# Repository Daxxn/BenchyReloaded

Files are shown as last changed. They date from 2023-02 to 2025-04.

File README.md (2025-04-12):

# BENCHY Version 2 - A Whole New Benchy Boi

>Alot of this is old and needs to be updated!

Your electronics workbench buddy! (Warning - Benchy is not actually your buddy and will probably try to kill you. It's hideously expensive, and way too time consuming to build!)

## Features

- Single Board Computer running embedded linux
- 5 Port USB 3.1 hub
- All data ports are **properly** protected agains over-current and backfeeding
- 2 USB 2.0 ports for the SBC peripherals (keyboard/mouse)
- 2 1Gb Ethernet ports
- 8 Software controlled relays for general things like lighting
- (In Development) Lab Power Supply W/ Current or Voltage Limiting (15V @ 2A)
- Lighting system that can drive 4 RGBW, 2 RGB, 6 dimmable, and 4 switched LED strips
- Electronic Load (5A Max)
- Simple 8 channel volt meter for quick and easy voltage testing
- (in development) Simple LCR Meter
- (in development) Function Generator

# Complete Assembly

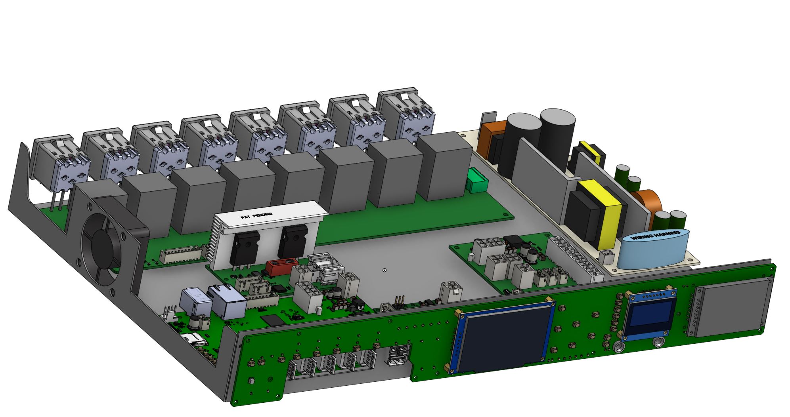
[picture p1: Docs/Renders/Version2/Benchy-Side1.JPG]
Assembly Render


## Motherboard Processor

This design integrates an STM32MP1 Series micro processor (U2) with 8Gb DDR3 memory (U20). This adds a large amount of raw power internally. Taking alot of the load required to control the sub-systems from the users PC and adds more flexability to the system as a whole.

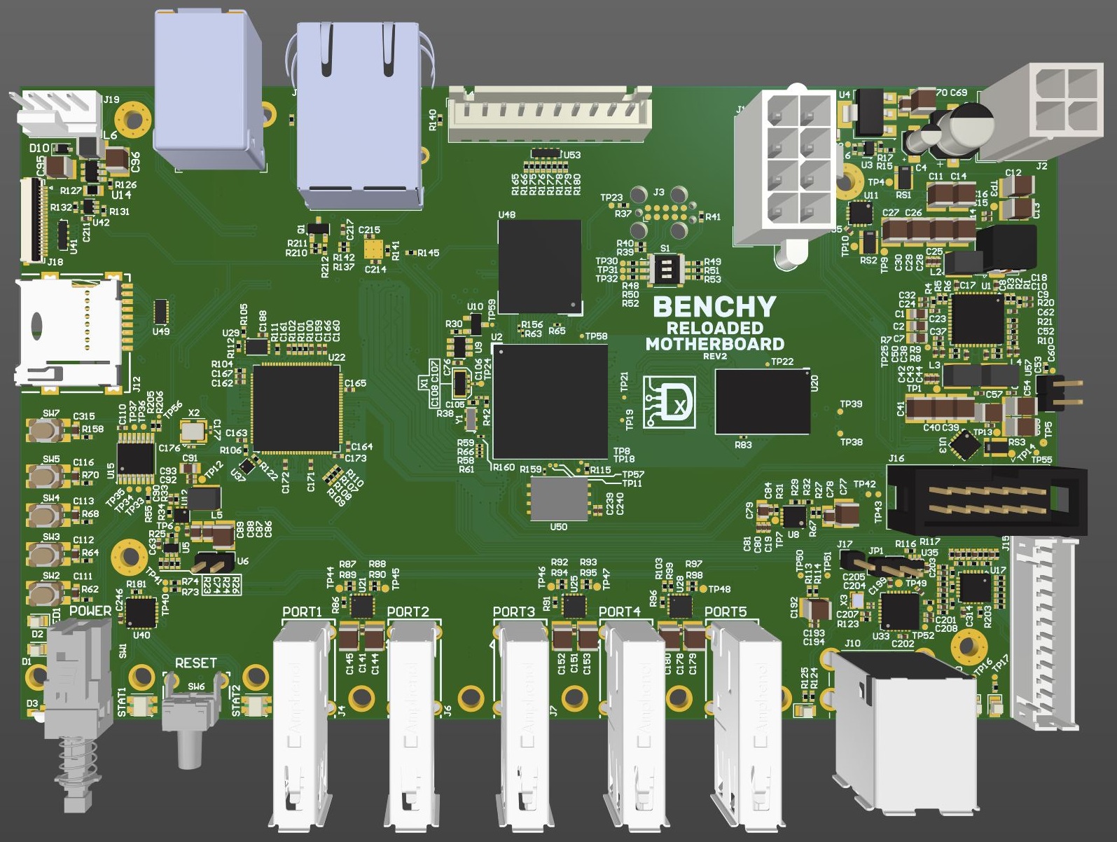
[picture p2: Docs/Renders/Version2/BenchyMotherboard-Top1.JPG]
MB Render


## USB Hub

The main reason why I needed to design my own USB hub instead of stuffing an "off the shelf" hub up benchys trumpet was the absolute lack of protection circuitry in most "consumer grade" USB hubs. There is no back-feed protection, verry little to no current monitoring, and the bare minimum ESD and EMI protection. Thats just not acceptable! imagine my supprise when I cracked open an $85 hub from Amazon and, after blowing out a channel, found no power management at all. The cost of finding a hub that has these protections is going to be around the same price as designing and building my own. (Except for the time investment... but who cares about that?!?)

These features arent exaclty flashy, they dont look very good on a brochure. So they usually arent there. If they are, its just a bullet point. Often they just _claim_ to conform to the USB spec. The lack protection doesn't actually conform to the spec at all. I will admit, some of the protection features are optional and not necessary for every day use. The problem is an electronics workbench is very mean. It will bully these simple hubs until they don't want to play along anymore.

## I2C Bus

Im using a quite extensive I2C bus system to communicate with the different boards and functional blocks. This cuts WAY down on the number of wires and pins required for the main controller and allows for better modularity within benchy.

Due to the size of the bus and the different devices, the bus is split by an I2C Mux to keep bus integrity while communicating to far PCBs.

# Power Supply

The one thing that made the two different power supplies possible was the Switch-Mode Power Supply (SMPS) that was built into the DVR box that spawned this project. The output from the SMPS is a high-current 12V source and 30V source. This was easy to adapt to my needs.

## Adjustable supply

- 15v @ 2A
- Controlled from the motherboard or front panel

The adjustable supply is built with help from [Dave, (Thanks Dave!)](https://www.youtube.com/watch?v=CIGjActDeoM&list=PLBF35875F73B5C9B5&index=1&ab_channel=EEVblog) using the [LM317](https://rocelec.widen.net/view/pdf/mlzstqhekh/slvs044x.pdf?t.download=true&u=5oefqw) adjustable regulator.

## 5V Supply

The ATX supply can provide 15 amps to the USB ports allowing each port to supply around 2 amps. Power is managed by the [UCS2114s.](https://ww1.microchip.com/downloads/aemDocuments/documents/APID/ProductDocuments/DataSheets/UCS2114-Data-Sheet-20005743B.pdf) Controlling both the current limit and backfeeding.

# Electronic Load

Fairly standard design using a MOSFET in its linear region, dissipating alot of energy. With the help of a big heatsink and a fan, it can be used to load power supplies to test their response. The current shunt will allow for precise measurement of power usage. Control is linked to the main microcontroller on the the motherboard. Allowing full control.

# 8 Channel Volt Meter

Low voltage volt meters with moderate accuracy and speed. Designed to measure multiple voltage levels simultaneously. This is helpful for testing power supplies designed for advanced ICs that require lots of voltages to run. Such as Processors, FPGAs, and PC Motherboards.

# Function generator

Creates sine, square, and triangle waves. from ~100Hz to ~100KHz.

# 8 Mains Rated Relays

8 channel relay block used to control general things around the bench like lighting and other small devices. Rated for mains voltage but not for high current.

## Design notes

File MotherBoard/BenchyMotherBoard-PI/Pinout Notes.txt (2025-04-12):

8 relay pins

	COMMS:
6 USART signals
1 I2C
2 SPI
FMC interface? Need to set up the RasPI and STM32 to run some tests with the code I found.

	INPUTS:
PWR SWITCH
EXT-INT
SLEEP
EXTRA BUTTON
PWR PGOOD

	OUTPUTS:
8 RELAYS

  INDICATORS:
STATUS
USB
DEBUG
ETH
MAIN-PG

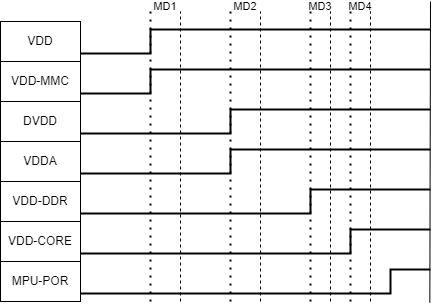
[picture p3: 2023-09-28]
Docs/Notes/AM6254-Power-Seq.png

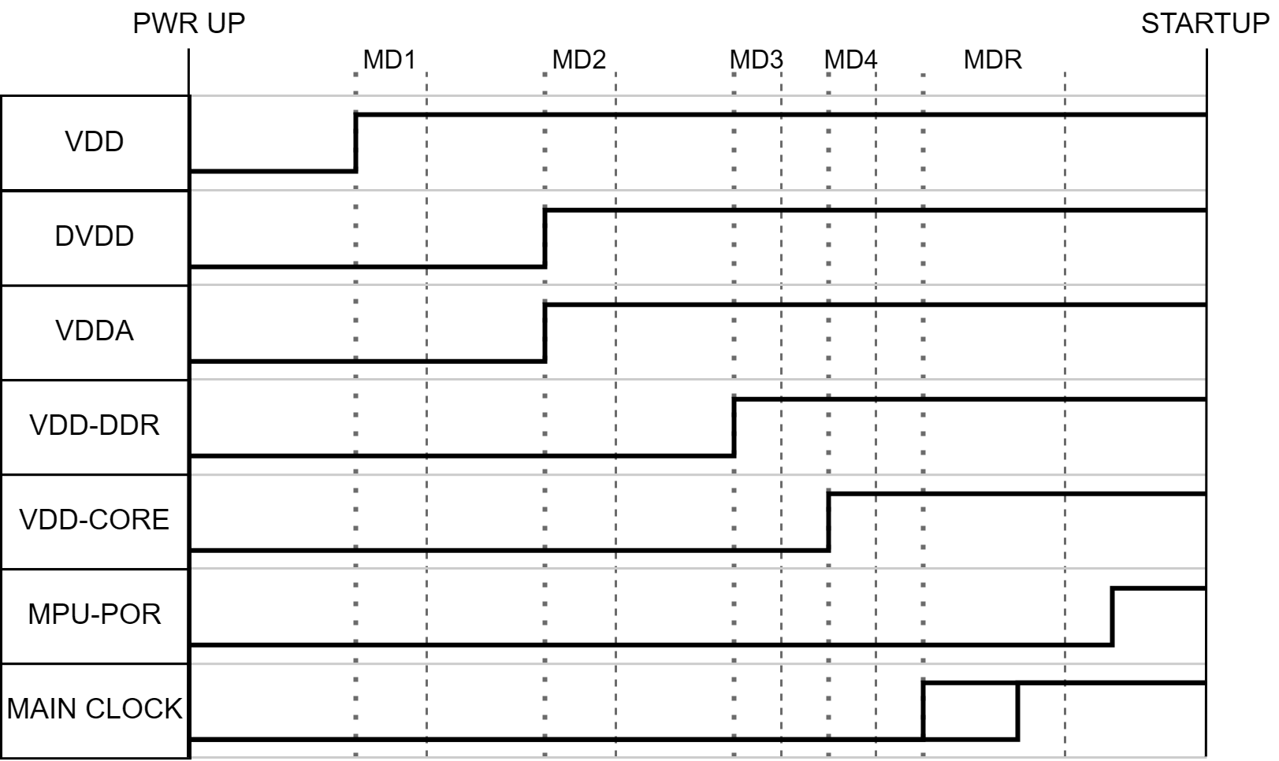
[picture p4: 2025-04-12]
MotherBoard/BenchyMotherBoard-AM625/Docs/AM6254-Power-Seq.png

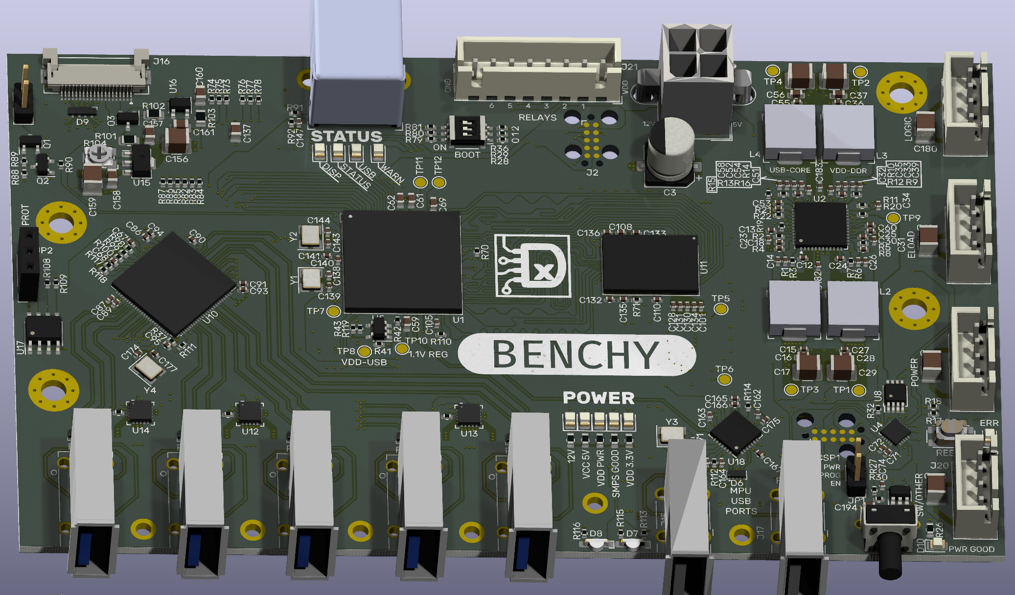
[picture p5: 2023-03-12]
Docs/Renders/MotherBoard/BenchyMotherBoard-REV1-TOP1.png

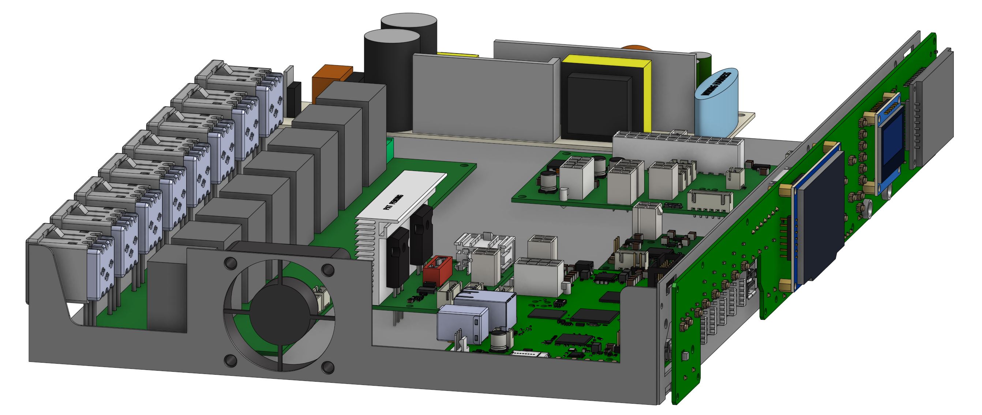
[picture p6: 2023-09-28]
Docs/Renders/Version2/Benchy-Side2.JPG

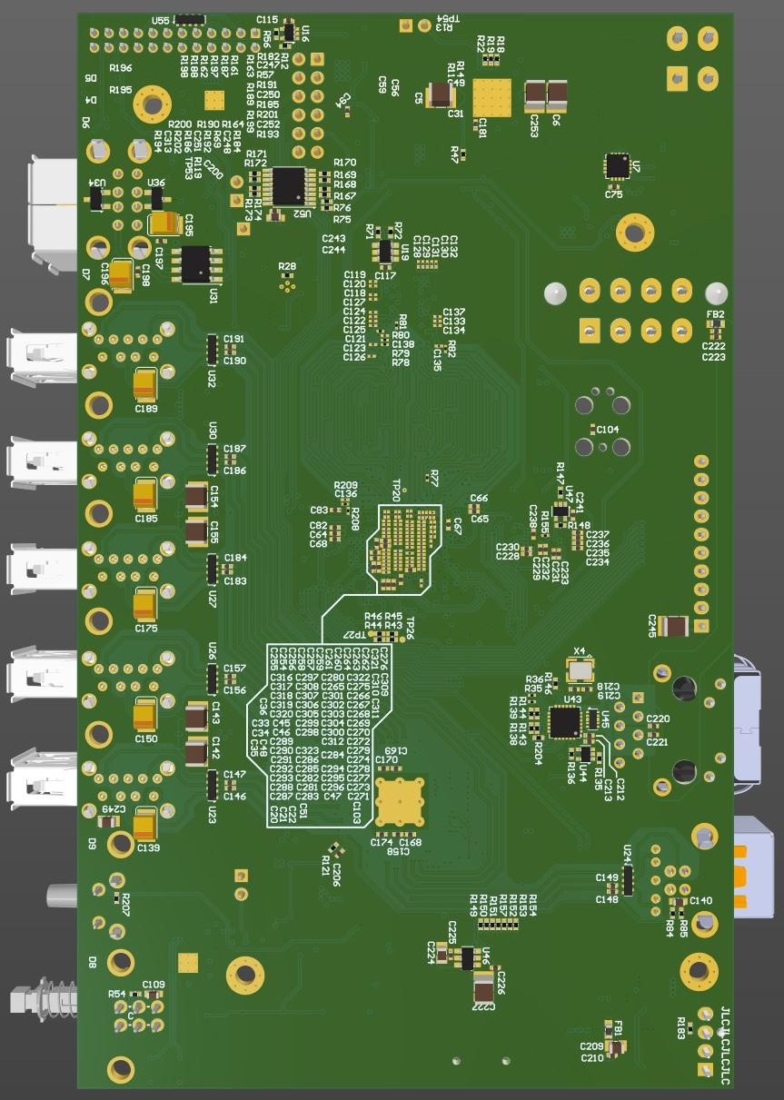
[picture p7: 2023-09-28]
Docs/Renders/Version2/BenchyMotherboard-Bot1.JPG

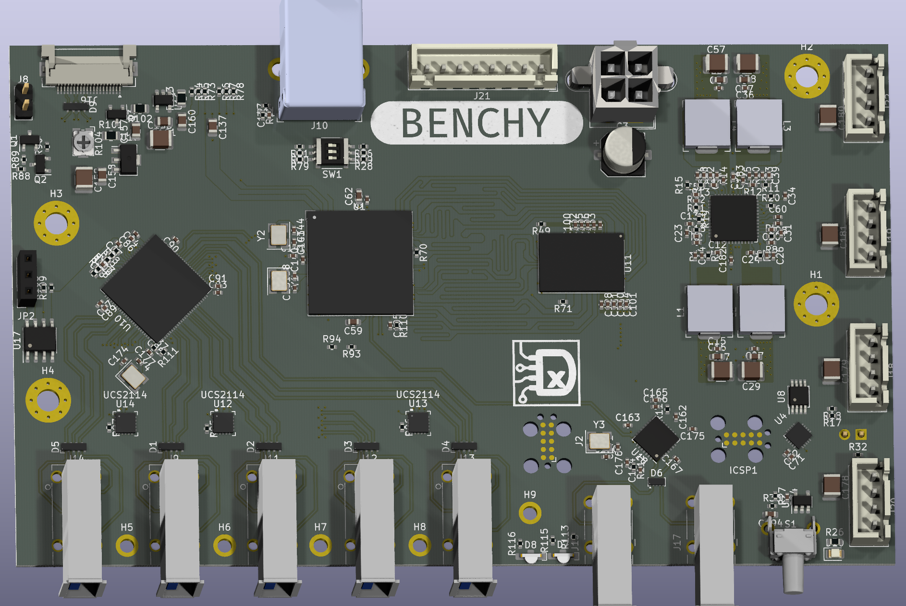
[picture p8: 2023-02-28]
Docs/Renders/MotherBoard/BenchyMotherBoard-PCB_Early2-TOP1.png

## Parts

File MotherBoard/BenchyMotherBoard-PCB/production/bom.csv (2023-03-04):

Designator | Footprint | Quantity | Value | LCSC Part #
C1 | 0603 | 1 | 100nF
C10 | 0402 | 1 | 100nF
C100 | 0402 | 1 | 100nF
C101 | 0402 | 1 | 100nF
C102 | 0402 | 1 | 100nF
C103 | 0402 | 1 | 100nF
C104 | 0402 | 1 | 100nF
C105 | 0402 | 1 | 100nF
C106 | 0402 | 1 | 100nF
C107 | 0402 | 1 | 100nF
C108 | 0402 | 1 | 100nF
C109 | 0402 | 1 | 100nF
C11 | 0402 | 1 | 100nF
C110 | 0402 | 1 | 100nF
C111 | 0402 | 1 | 100nF
C112 | 0402 | 1 | 100nF
C113 | 0402 | 1 | 100nF
C114 | 0402 | 1 | 100nF
C115 | 0402 | 1 | 100nF
C116 | 0402 | 1 | 100nF
C117 | 0402 | 1 | 100nF
C118 | 0402 | 1 | 100nF
C119 | 0402 | 1 | 100nF
C12 | 0402 | 1 | 100nF
C120 | 0402 | 1 | 100nF
C121 | 0402 | 1 | 100nF
C122 | 0402 | 1 | 100nF
C123 | 0603 | 1 | 1uF
C124 | 0603 | 1 | 1uF
C125 | 1210 | 1 | 22uF
C126 | 1210 | 1 | 22uF
C127 | 0402 | 1 | 100nF
C128 | 0402 | 1 | 100nF
C129 | 0402 | 1 | 100nF
C13 | 0402 | 1 | 100nF
C130 | 0402 | 1 | 100nF
C131 | 0402 | 1 | 100nF
C132 | 0402 | 1 | 100nF
C133 | 0402 | 1 | 100nF
C134 | 0402 | 1 | 100nF
C135 | 0402 | 1 | 100nF
C136 | 0402 | 1 | 100nF
C137 | 0805 | 1 | 4.7uF
C138 | 0402 | 1 | 15pF
C139 | 0402 | 1 | 15pF
C14 | 0402 | 1 | 100nF
C140 | 0402 | 1 | 1nF
C141 | 0402 | 1 | 10nF
C142 | 0805 | 1 | 4.7uF
C143 | 0402 | 1 | 15pF
C144 | 0402 | 1 | 15pF
C145 | 1210 | 1 | 10uF
C146 | 1210 | 1 | 10uF
C147 | 0402 | 1 | 100nF
C148 | 1210 | 1 | 10uF
C149 | 1210 | 1 | 10uF
C15 | 0402 | 1 | 100nF
C150 | 1210 | 1 | 10uF
C151 | 1210 | 1 | 10uF
C152 | 1210 | 1 | 10uF
C153 | 1210 | 1 | 10uF
C154 | 1210 | 1 | 10uF
C155 | 1210 | 1 | 10uF
C156 | 1210 | 1 | 10uF
C157 | 0805 | 1 | 1uF
C158 | 0805 | 1 | 1uF
C159 | 1210 | 1 | 10uF
C16 | 0603 | 1 | 1uF
C160 | 0805 | 1 | 1uF
C161 | 0805 | 1 | 100nF
C162 | 0402 | 1 | 100nF
C163 | 0402 | 1 | 100nF
C164 | 0402 | 1 | 100nF
C165 | 0402 | 1 | 100nF
C166 | 0402 | 1 | 100nF
C167 | 0402 | 1 | 100nF
C168 | 1210 | 1 | 10uF
C169 | 1210 | 1 | 1uF
C17 | 1210 | 1 | 10uF
C170 | 0402 | 1 | 15pF
C171 | 0402 | 1 | 15pF
C172 | 1210 | 1 | 10uF
C173 | 1210 | 1 | 1uF
C174 | 0402 | 1 | 15pF
C175 | 0402 | 1 | 100nF
C176 | 0402 | 1 | 100nF
C177 | 0402 | 1 | 15pF
C178 | 1210 | 1 | 10uF
C179 | 1210 | 1 | 10uF
C18 | 0402 | 1 | 47pF
C180 | 1210 | 1 | 10uF
C181 | 1210 | 1 | 10uF
C182 | 0402 | 1 | 100nF
C183 | 0402 | 1 | 100nF
C184 | 1210 | 1 | 10uF
C185 | 0402 | 1 | 100nF
C186 | 0402 | 1 | 100nF
C187 | 0402 | 1 | 100nF
C188 | 0402 | 1 | 100nF
C189 | 0402 | 1 | 100nF
C19 | 0603 | 1 | 1uF
C190 | 0402 | 1 | 100nF
C191 | 0402 | 1 | 100nF
C192 | 0402 | 1 | 100nF
C193 | 0402 | 1 | 100nF
C194 | 0603 | 1 | 1uF
C195 | 0402 | 1 | 100nF
C2 | 0603 | 1 | 100nF
C20 | 0603 | 1 | 1uF
C21 | 0603 | 1 | 1uF
C22 | 0603 | 1 | 1uF
C23 | 0402 | 1 | 330pF
C24 | 0402 | 1 | 100nF
C25 | 0402 | 1 | 100nF
C26 | 0402 | 1 | 100nF
C27 | 0402 | 1 | 100nF
C28 | 0603 | 1 | 1uF
C29 | 1210 | 1 | 10uF
C3 | CP_Elec_6.3x7.7 | 1 | 47uF
C30 | 0402 | 1 | 117pF
C31 | 0402 | 1 | 1nF
C32 | 0402 | 1 | 100nF
C33 | 0402 | 1 | 100pF
C34 | 0402 | 1 | 100nF
C35 | 0402 | 1 | 100nF
C36 | 0402 | 1 | 100nF
C37 | 0603 | 1 | 1uF
C38 | 1210 | 1 | 10uF
C39 | 0402 | 1 | 820pF
C4 | 1210 | 1 | 10uF
C40 | 0402 | 1 | 100nF
C41 | 0402 | 1 | 100nF
C42 | 0402 | 1 | 100nF
C43 | 0402 | 1 | 100nF
C44 | 0402 | 1 | 100nF
C45 | 0402 | 1 | 100nF
C46 | 0402 | 1 | 100nF
C47 | 0402 | 1 | 100nF
C48 | 0402 | 1 | 100nF
C49 | 0402 | 1 | 100nF
C5 | 0402 | 1 | 100nF
C50 | 0402 | 1 | 100nF
C51 | 0402 | 1 | 100nF
C52 | 0402 | 1 | 150pF
C53 | 0402 | 1 | 100nF
C54 | 0402 | 1 | 100nF
C55 | 0402 | 1 | 100nF
C56 | 0603 | 1 | 1uF
C57 | 1210 | 1 | 10uF
C58 | 0402 | 1 | 1.5nF
C59 | 0603 | 1 | 2.2uF
C6 | 0402 | 1 | 100nF
C60 | 0402 | 1 | 100nF
C61 | 0603 | 1 | 2.2uF
C62 | 0603 | 1 | 1uF
C63 | 0603 | 1 | 4.7uF
C64 | 0805 | 1 | 10uF
C65 | 0805 | 1 | 10uF
C66 | 0805 | 1 | 10uF
C67 | 0402 | 1 | 100nF
C68 | 0402 | 1 | 100nF
C69 | 0603 | 1 | 2.2uF
C7 | 0402 | 1 | 100nF
C70 | 0603 | 1 | 1uF
C71 | 0402 | 1 | 100nF
C72 | 0402 | 1 | 100nF
C73 | 0603 | 1 | 1uF
C74 | 0402 | 1 | 100nF
C75 | 0603 | 1 | 1uF
C76 | 0402 | 1 | 100nF
C77 | 0603 | 1 | 4.7uF
C78 | 0402 | 1 | 200nF
C79 | 0603 | 1 | 1uF
C8 | 0402 | 1 | 100nF
C80 | 0603 | 1 | 1uF
C81 | 0402 | 1 | 100nF
C82 | 0402 | 1 | 100nF
C83 | 0402 | 1 | 100nF
C84 | 0402 | 1 | 100nF
C85 | 0402 | 1 | 100nF
C86 | 0402 | 1 | 100nF
C87 | 0402 | 1 | 100nF
C88 | 0402 | 1 | 100nF
C89 | 0402 | 1 | 100nF
C9 | 0402 | 1 | 100nF
C90 | 0402 | 1 | 100nF
C91 | 0402 | 1 | 100nF
C92 | 0402 | 1 | 100nF
C93 | 0402 | 1 | 100nF
C94 | 0402 | 1 | 100nF
C95 | 0402 | 1 | 100nF
C96 | 0805 | 1 | 10uF
C97 | 0805 | 1 | 10uF
C98 | 0402 | 1 | 1nF
C99 | 0402 | 1 | 100nF
D1, D2, D3, D4, D5, D9 | U-DFN3810-9 | 6 | ESDLC5V0PB8
D10 | 0805 | 1 | GREEN
D11 | 0805 | 1 | RED
D12 | 0805 | 1 | ORANGE
D13 | 0805 | 1 | RED
D14 | 0805 | 1 | ORANGE
D15 | 0805 | 1 | GREEN
D6 | DFN2510A-10 | 1 | PUSB3AB4-2USB
D7 | LED-SMD-1204_RA | 1 | ORANGE
D8 | LED-SMD-1204_RA | 1 | YELLOW
H1, H2, H3, H4 | MountingHole_3.5mm_Pad_Via | 4 | M3
H10, H5, H6, H7, H8, H9 | MountingHole_2.2mm_M2_ISO7380_Pad | 6 | M2
ICSP1 | Tag-Connect_TC2050-IDC-FP_2x05_P1.27mm_Vertical | 1 | ICSP
J1 | 4-Pin_Molex_Mini-Fit_Jr_Vertical_Mount | 1 | PWR-CONN
J10 | USB-GSB3211311WEU | 1 | USB3_B
J11 | GSB4116341HR | 1 | USB3-PORT2
J12 | GSB4116341HR | 1 | USB3-PORT3
J13 | GSB4116341HR | 1 | USB3-PORT4
J14 | GSB4116341HR | 1 | USB3-PORT5
J15 | 1002-014-01000 | 1 | USB-INTERNAL-PORT1
J16 | FH12A-20S-0.5SH55 | 1 | TFT-DISPLAY
J17 | 1002-014-01000 | 1 | USB-INTERNAL-PORT2
J18 | JST_XH_B4B-XH-A_Vertical | 1 | COMMS-PWR
J19 | JST_XH_B4B-XH-A_Vertical | 1 | COMMS-ELOAD
J2 | Tag-Connect_TC2050-IDC-FP_2x05_P1.27mm_Vertical | 1 | SWD-TAG
J20 | JST_XH_B4B-XH-A_Vertical | 1 | COMMS-SWITCHER
J21 | JST_XH_B8B-XH-A_1x08_P2.50mm_Vertical | 1 | RELAYS-CONN
J22 | JST_XH_B4B-XH-A_Vertical | 1 | COMMS-LOGIC
J3 | microSD_HC_Molex_47219-2001 | 1 | FILES-SD-CARD
J7 | microSD_HC_Molex_47219-2001 | 1 | BOOT-SD-CARD
J8 | PinHeader_1x02_P2.54mm_Vertical | 1 | FAN-CONN
J9 | GSB4116341HR | 1 | USB3-PORT1
JP1 | PinHeader_1x02_P2.54mm_Vertical | 1 | PWR-ICSP-RST
JP2 | PinSocket_1x03_P2.54mm_Vertical | 1 | WP-JMP
L1 | PA4341 | 1 | 22uH
L2, L3, L4 | PA4341 | 3 | 10uH
Q1 | SOT-23 | 1 | SQ2310ES_SOT23
Q2 | SOT-23 | 1 | MMBT2222A
Q3 | SOT-23 | 1 | RQ5A030AP
R1 | 0402 | 1 | 24K
R10 | 0402 | 1 | 13K
R100 | 0402 | 1 | 10K
R101 | 0805 | 1 | 10 1%
R102 | 0805 | 1 | 120
R103 | 0805 | 1 | 330
R104 | Bourns_TC33X | 1 | 10K
R105 | 0402 | 1 | 10K
R106 | 0402 | 1 | 200K
R107 | 0402 | 1 | 200K
R108 | 0402 | 1 | 2.2K
R109 | 0402 | 1 | 2.2K
R11 | 0402 | 1 | 10K
R110 | 0402 | 1 | 3K
R111 | 0402 | 1 | 10K
R112 | 0402 | 1 | 12K 1%
R113 | 0402 | 1 | 50K
R114 | 0402 | 1 | 50K
R115 | 0402 | 1 | 1K
R116 | 0402 | 1 | 1K
R117 | 0402 | 1 | 10K
R118 | 0402 | 1 | 200K
R119 | 0402 | 1 | 4.7K
R12 | 0402 | 1 | 15K
R13 | 0402 | 1 | 8.2K
R14 | 0402 | 1 | 4.3K
R15 | 0402 | 1 | 10K
R16 | 0402 | 1 | 11K
R17 | 0402 | 1 | 2.2K
R18 | 0402 | 1 | 2.2K
R19 | 0402 | 1 | 10K
R2 | 0402 | 1 | 24K
R20 | 0402 | 1 | 10K
R21 | 0402 | 1 | 160K
R22 | 0402 | 1 | 160K
R23 | 0402 | 1 | 10K
R24 | 0402 | 1 | 10K
R25 | 0402 | 1 | 10K
R26 | 0603 | 1 | 500
R27 | 0402 | 1 | 1K
R28 | 0402 | 1 | 1K
R29 | 0402 | 1 | 1K
R3 | 0402 | 1 | 10K
R30 | 0402 | 1 | 10K
R31 | 0603 | 1 | 500
R32 | 0402 | 1 | 10K
R33 | 0603 | 1 | 500
R34 | 0402 | 1 | 10K
R35 | 0402 | 1 | 6.8K
R36 | 0402 | 1 | 1K
R37 | 0402 | 1 | 12K 1%
R38 | 0603 | 1 | 500
R39 | 0603 | 1 | 500
R4 | 0402 | 1 | 7.5K
R40 | 0603 | 1 | 500
R41 | 0402 | 1 | 10K
R42 | 0402 | 1 | 100
R43 | 0402 | 1 | 10K
R44 | 0402 | 1 | 56
R45 | 0402 | 1 | 100
R46 | 0402 | 1 | 56
R47 | 0402 | 1 | 56
R48 | 0402 | 1 | 56
R49 | 0402 | 1 | 10K
R5 | 0402 | 1 | 10K
R50 | 0402 | 1 | 10K
R51 | 0402 | 1 | 56
R52 | 0402 | 1 | 56
R53 | 0402 | 1 | 56
R54 | 0402 | 1 | 56
R55 | 0402 | 1 | 56
R56 | 0402 | 1 | 56
R57 | 0402 | 1 | 56
R58 | 0402 | 1 | 56
R59 | 0402 | 1 | 56
R6 | 0402 | 1 | 6.2K
R60 | 0402 | 1 | 56
R61 | 0402 | 1 | 56
R62 | 0402 | 1 | 56
R63 | 0402 | 1 | 56
R64 | 0402 | 1 | 56
R65 | 0402 | 1 | 56
R66 | 0402 | 1 | 56
R67 | 0402 | 1 | 56
R68 | 0402 | 1 | 56
R69 | 0402 | 1 | 56
R7 | 0402 | 1 | 10K
R70 | 0402 | 1 | 240 1%
R71 | 0402 | 1 | 240 1%
R72 | 0402 | 1 | 56
R73 | 0402 | 1 | 10K
R74 | 0402 | 1 | 47K
R75 | 0402 | 1 | 47K
R76 | 0402 | 1 | 47K
R77 | 0402 | 1 | 47K
R78 | 0402 | 1 | 47K
R79 | 0402 | 1 | 100
R8 | 0402 | 1 | 10K
R80 | 0402 | 1 | 100
R81 | 0402 | 1 | 100
R82 | 0402 | 1 | 10K
R83 | 0402 | 1 | 47K
R84 | 0402 | 1 | 47K
R85 | 0402 | 1 | 47K
R86 | 0402 | 1 | 47K
R87 | 0402 | 1 | 47K
R88 | 0402 | 1 | 10K
R89 | 0402 | 1 | 100
R9 | 0402 | 1 | 10K
R90 | 0402 | 1 | 1K
R91 | 0402 | 1 | 43K
R92 | 0402 | 1 | 50K
R93 | 0402 | 1 | 2.2K
R94 | 0402 | 1 | 2.2K
R95 | 0402 | 1 | 18K
R96 | 0402 | 1 | 18K
R97 | 0402 | 1 | 18K
R98 | 0402 | 1 | 10K
R99 | 0402 | 1 | 10K
S1 | TL1105SF | 1 | PWR-SW
S2 | TL3365AF180QG | 1 | PWR-RESET
SW1 | SW_DIP_SPSTx03_Slide_Copal_CVS-03xB_W5.9mm_P1mm | 1 | BOOT-SEL
TP1 | TestPoint_Pad_D1.5mm | 1 | TP-VDD-CORE
TP10 | TestPoint_Pad_D1.5mm | 1 | TP-1V1-REG
TP11 | TestPoint_Pad_D1.5mm | 1 | TP-1V8-REG
TP12 | TestPoint_Pad_D1.5mm | 1 | TP-DSI-REG
TP2 | TestPoint_Pad_D1.5mm | 1 | TP-VDD-DDR
TP3 | TestPoint_Pad_D1.5mm | 1 | TP-VDD
TP4 | TestPoint_Pad_D1.5mm | 1 | TP-USB-CORE
TP5 | TestPoint_Pad_D1.5mm | 1 | TP-VTT
TP6 | TestPoint_Pad_D1.5mm | 1 | TP-VREF-DDR
TP7 | TestPoint_Pad_D1.5mm | 1 | TP-VDDA
TP8 | TestPoint_Pad_D1.5mm | 1 | TP-VDD-USB
TP9 | TestPoint_Pad_D1.5mm | 1 | TP-VDD-PWR
U1 | LFBGA354-P0.8mm | 1 | STM32MP157FAB1
U10 | 100-VQFN-GND_12X12 | 1 | USB7206C
U11 | DDR_FBGA-96_9x13mm_P0.8mm | 1 | IS43TR16256B-125KBLI
U12, U13, U14 | UCS2114T-1-V_LXVAO-Custom | 3 | UCS2114
U15 | SOT-89-3 | 1 | LM317L
U16 | SOT-23-5 | 1 | AS321
U17 | SOIC-8_3.9x4.9mm_P1.27mm | 1 | 24LC08
U18 | QFN-28-1EP_5x5mm_P0.5mm_EP3.35x3.35mm | 1 | USB2412
U2 | QFN-48-1EP_7x7mm_P0.5mm_EP5.15x5.15mm_ThermalVias | 1 | TPS65400RGZT
U3 | DFN-10-1EP_3x3mm_P0.5mm_EP1.65x2.38mm | 1 | NCP51200
U4 | QFN-20-1EP_3x3mm_P0.4mm_EP1.65x1.65mm | 1 | ATTINY416-MNR
U5 | SOT-23-5 | 1 | TLV3401
U6 | DFN-10-1EP_3x3mm_P0.5mm_EP1.65x2.38mm | 1 | MAX15027
U7 | SOT-23-5 | 1 | SN74LVC1G32
U8 | TSSOP-8_3x3mm_P0.65mm | 1 | 74HCT2G08
U9 | SOT-23-5 | 1 | AP2127K-3.3
Y1 | Crystal_SMD_4Pin_3.2x2.5mm | 1 | 24MHz
Y2 | Crystal_SMD_4Pin_3.2x2.5mm | 1 | 32.7KHz
Y3, Y4 | Crystal_SMD_4Pin_3.2x2.5mm | 2 | 25MHz

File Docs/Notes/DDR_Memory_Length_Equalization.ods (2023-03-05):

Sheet: Sheet 1
Memory_length_equalization_in_mm_for_STM32MP15XXAB
Board reference: | STM32MP15XXAB
Variant:
PCB revision:
Assembly revision:
Date:

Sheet: Address_Command
 | STM32MP15XXAB
LFBGA354 PINOUT | NET NAME | STM32MP15XXAB LENGTH (mm) | STM32MP15XXAB to memory (mm) | KiCAD Total Length (mm) | TOTAL LENGTH (mm) | DELTA WITH ((CLK_P+CLK_N)/2): from -1.016 to 0 mm | Fill the column C with the track lengths of printed circuit board including via Modify the track length of column C in order to be within the limits of column E
H18 | A0 | 5.19 | 61.4075 | 65.0171 | 65.0171 | -0.2012 | value | within the limits
M17 | A1 | 6.31 | 60.0967 | 65.0539 | 65.0539 | -0.164400000000001 | value | outside the limits
G18 | A2 | 5.63 | 61.0362 | 65.0241 | 65.0241 | -0.194199999999995
F19 | A3 | 6.58 | 60.1274 | 64.9999 | 64.9999 | -0.218400000000003
P17 | A4 | 5.55 | 61.1017 | 65.0387 | 65.0387 | -0.179599999999994
H17 | A5 | 3.79 | 62.8956 | 65.0519 | 65.0519 | -0.166399999999996
N16 | A6 | 4.06 | 62.6386 | 65.0006 | 65.0006 | -0.217699999999994
E17 | A7 | 7.8 | 58.8546 | 64.9999 | 64.9999 | -0.218400000000003
R17 | A8 | 6.62 | 60.0918 | 65 | 65 | -0.218299999999999
G17 | A9 | 4.05 | 62.6402 | 65.0131 | 65.0131 | -0.205200000000005
M19 | A10 | 6.59 | 60.0643 | 65 | 65 | -0.218299999999999
M18 | A11 | 5.69 | 61.0072 | 65 | 65 | -0.218299999999999
L17 | A12 | 4.57 | 62.0861 | 65.0903 | 65.0903 | -0.128
F17 | A13 | 6.34 | 60.2901 | 65.0523 | 65.0523 | -0.165999999999997
N18 | A14 | 6.65 | 60.0339 | 65.0218 | 65.0218 | -0.1965
L16 | A15 | 4.11 | 0 | 0 | 4.11 | -61.1083
G19 | BA0 | 6.01 | 60.6675 | 65 | 65 | -0.218299999999999
N17 | BA1 | 6.76 | 59.676 | 65 | 65 | -0.218299999999999
J16 | BA2 | 5.81 | 60.8156 | 65 | 65 | -0.218299999999999
K17 | CASN | 4.85 | 61.8182 | 65.0271 | 65.0271 | -0.191199999999995
P19 | CKE | 6.66 | 60.0232 | 65 | 65 | -0.218299999999999
L19 | CLK_N | 6.03 | 60.559 | 65.2336 | 65.2336
K19 | CLK_P | 6.09 | 60.7447 | 65.203 | 65.203
J18 | CSN | 5.86 | 60.8061 | 65.0106 | 65.0106 | -0.207700000000003
H19 | ODT | 6.47 | 60.1628 | 65 | 65 | -0.218299999999999
L18 | RASN | 5.21 | 61.4307 | 65.0012 | 65.0012 | -0.217100000000002
J17 | WEN | 4.69 | 61.9582 | 65 | 65 | -0.218299999999999

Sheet: Data
STM32MP15XXAB
 | LFBGA354 PINOUT | NET NAME | STM32MP15XXAB LENGTH (mm) | STM32MP15XXAB to memory (mm) | KiCAD Total Length (mm) | TOTAL LENGTH (mm) | DELTA WITH ((DQSn_P+DQSn_N)/2) MAX: +/- 1.016 mm | DELTA WITH ((CLK_P+CLK_N)/2): from -15 to 0 mm | Fill the column D with the track lengths of printed circuit board including via Modify the track length of column D in order to be within the limits of columns F and G
Byte 0 | A17 | DQ0 | 8.17 | 0 | 65.0894 | 65.0894 | 0.0852499999999878 |  | value | within the limits
 | A18 | DQ1 | 8.19 | 0 | 65.0434 | 65.0434 | 0.0392499999999956 |  | value | outside the limits
 | D18 | DQ2 | 6.92 | 0 | 65.0477 | 65.0477 | 0.0435499999999962
 | B17 | DQ3 | 6.97 | 0 | 64.9933 | 64.9933 | -0.0108500000000049
 | E18 | DQ4 | 6.7 | 0 | 65.0011 | 65.0011 | -0.00305000000001598
 | D17 | DQ5 | 7.63 | 0 | 65.0037 | 65.0037 | -0.000450000000014938
 | D19 | DQ6 | 7.33 | 0 | 65 | 65 | -0.00415000000000987
 | B18 | DQ7 | 7.47 | 0 | 65.0023 | 65.0023 | -0.00185000000000457
 | C18 | DQM0 | 6.76 | 0 | 65.0017 | 65.0017 | -0.00245000000001028
 | C19 | DQS0_P | 8.08 | 0 | 65 | 65 |  | -0.214149999999989
 | B19 | DQS0_N | 8.09 | 0 | 65.0083 | 65.0083
Byte 1 | P18 | DQ8 | 5.36 | 0 | 65.0211 | 65.0211 | -0.0274500000000017
 | T17 | DQ9 | 7.37 | 0 | 65 | 65 | -0.0485500000000059
 | R18 | DQ10 | 6.67 | 0 | 65.0964 | 65.0964 | 0.0478499999999968
 | V19 | DQ11 | 7.66 | 0 | 65.0914 | 65.0914 | 0.0428499999999872
 | W18 | DQ12 | 7.85 | 0 | 65.0942 | 65.0942 | 0.0456499999999949
 | T18 | DQ13 | 6.8 | 0 | 65.0643 | 65.0643 | 0.015749999999997
 | V18 | DQ14 | 7.23 | 0 | 65.0042 | 65.0042 | -0.0443500000000086
 | W17 | DQ15 | 7.9 | 0 | 65.0048 | 65.0048 | -0.0437500000000028
 | U18 | DQM1 | 6.83 | 0 | 65.0071 | 65.0071 | -0.0414500000000118
 | U19 | DQS1_P | 7.26 | 0 | 65.011 | 65.011 |  | -0.169749999999993
 | T19 | DQS1_N | 7.26 | 0 | 65.0861 | 65.0861

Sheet: Impedance
DDR3 MEMORY IMPEDANCE
Differential Pairs | Req | Calculated | Width | Spacing
Diff Pair Inner | 100 | 100.189 | 0.195 | 0.1
DiffPair Outer | 100 | 100.164 | 0.12 | 0.13
Striplines | Req | Calculated | Width | Clearance
Strip Line (Inner) | 55 | 55.0422 | 0.15 | 0.4584
Microstrip Line (Outer) | 55 | 55.0052 | 0.15 | 0.3
Theres no guarantee that the impedance calculations are correct

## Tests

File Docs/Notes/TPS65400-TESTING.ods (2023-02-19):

Voltage Feedback
VREF | RTOP | RBOT
0.8 | 6.6 | 7.5
VOUT
1.504
Inductor Selection / Ripple
uL | L | Khz | Hz | Nominal Ripple | Max Ripple
10 | 0.00001 | 1000 | 1000000 | 0.6 | 0.9
VIN
12
Output Current Ripple
0.131549866666667

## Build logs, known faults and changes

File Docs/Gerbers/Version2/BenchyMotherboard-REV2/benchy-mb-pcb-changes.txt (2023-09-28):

%FSLAX23Y23*%
%MOIN*%
%SFA1B1*%

%IPPOS*%
%ADD9500C,0.007900*%
%ADD9501C,0.009800*%
%ADD9502C,0.011800*%
%ADD9503C,0.015700*%
%ADD9504C,0.027600*%
%ADD9505C,0.029100*%
%ADD9506C,0.029500*%
%ADD9507C,0.035000*%
%ADD9508C,0.035400*%
%ADD9509C,0.036200*%
%ADD9510C,0.037400*%
%ADD9511C,0.039400*%
%ADD9512C,0.040200*%
%ADD9513C,0.051200*%
%ADD9514C,0.055100*%
%ADD9515C,0.059000*%
%ADD9516C,0.063000*%
%ADD9517C,0.090600*%
%ADD9518C,0.106300*%
%ADD9519C,0.037000*%
%ADD9520C,0.039000*%
%ADD9521C,0.043300*%
%ADD9522C,0.093500*%
%ADD9523C,0.118100*%
%ADD9524C,0.128000*%
%LNbenchy-mb-pcb-changes-1*%
%LPD*%
G54D9500*
X911Y887D03*
X954Y1181D03*
X822D03*
Y1338D03*
X954D03*
X1076Y1531D03*
X1183Y1486D03*
X1395Y1502D03*
X1474D03*
X1465Y1426D03*
Y1385D03*
Y1343D03*
X1423D03*
Y1385D03*
Y1426D03*
X1506D03*
Y1385D03*
Y1343D03*
X1366Y1334D03*
X1350Y1387D03*
X1492Y893D03*
X1795Y1023D03*
X2214D03*
X2242D03*
X2192Y905D03*
X2110Y1133D03*
Y1161D03*
Y1190D03*
X2637Y1169D03*
X2667D03*
X2696Y1171D03*
Y1143D03*
Y1200D03*
Y1252D03*
Y1322D03*
Y1342D03*
X2722Y1344D03*
X2744D03*
X2765D03*
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

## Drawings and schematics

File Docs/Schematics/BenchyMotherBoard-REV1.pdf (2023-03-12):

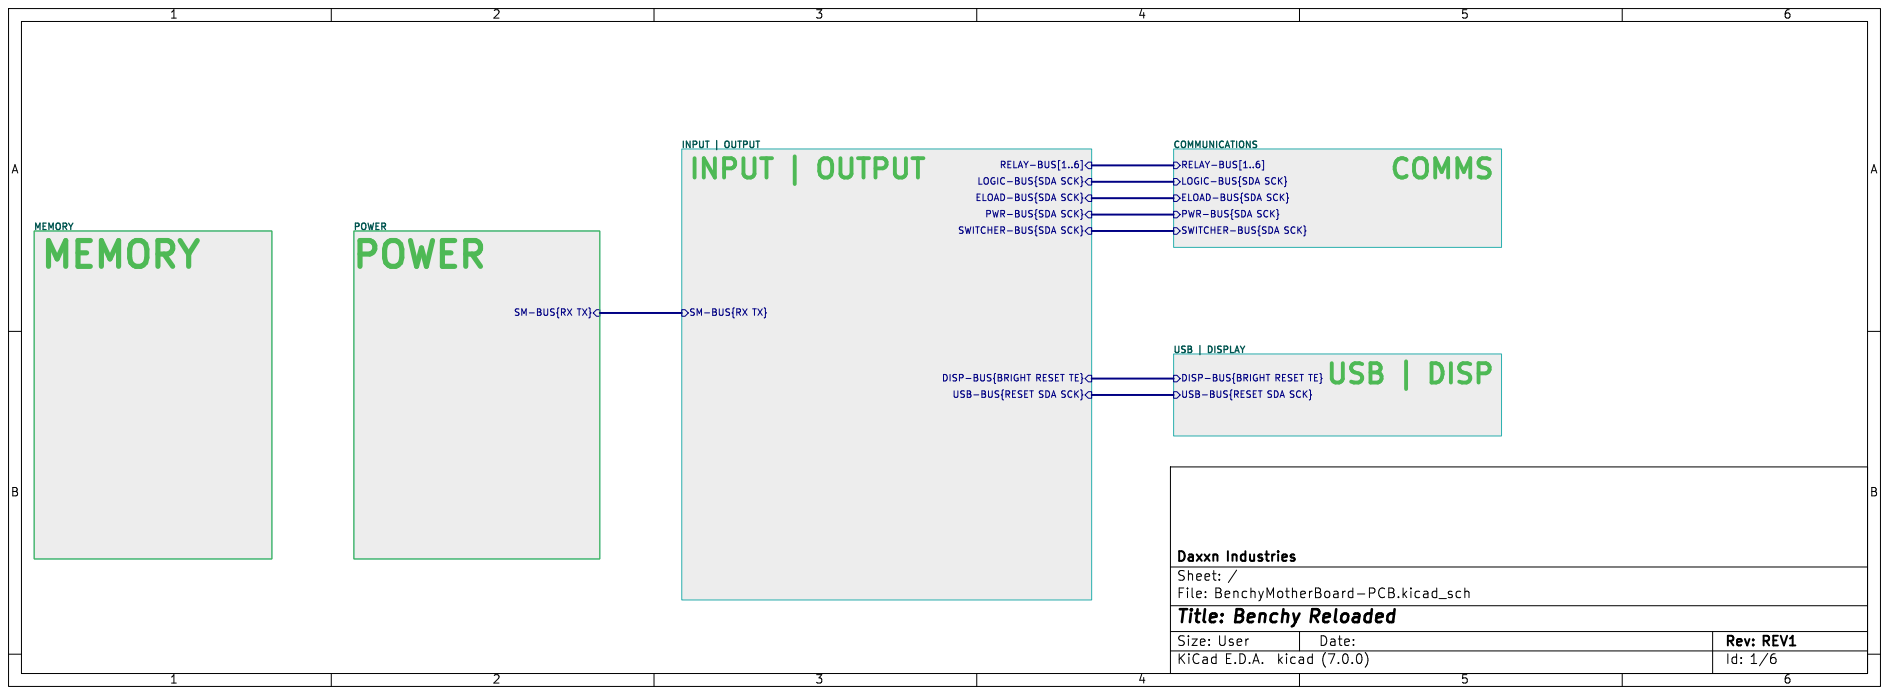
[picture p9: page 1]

Id: 1/6 Title: Benchy Reloaded

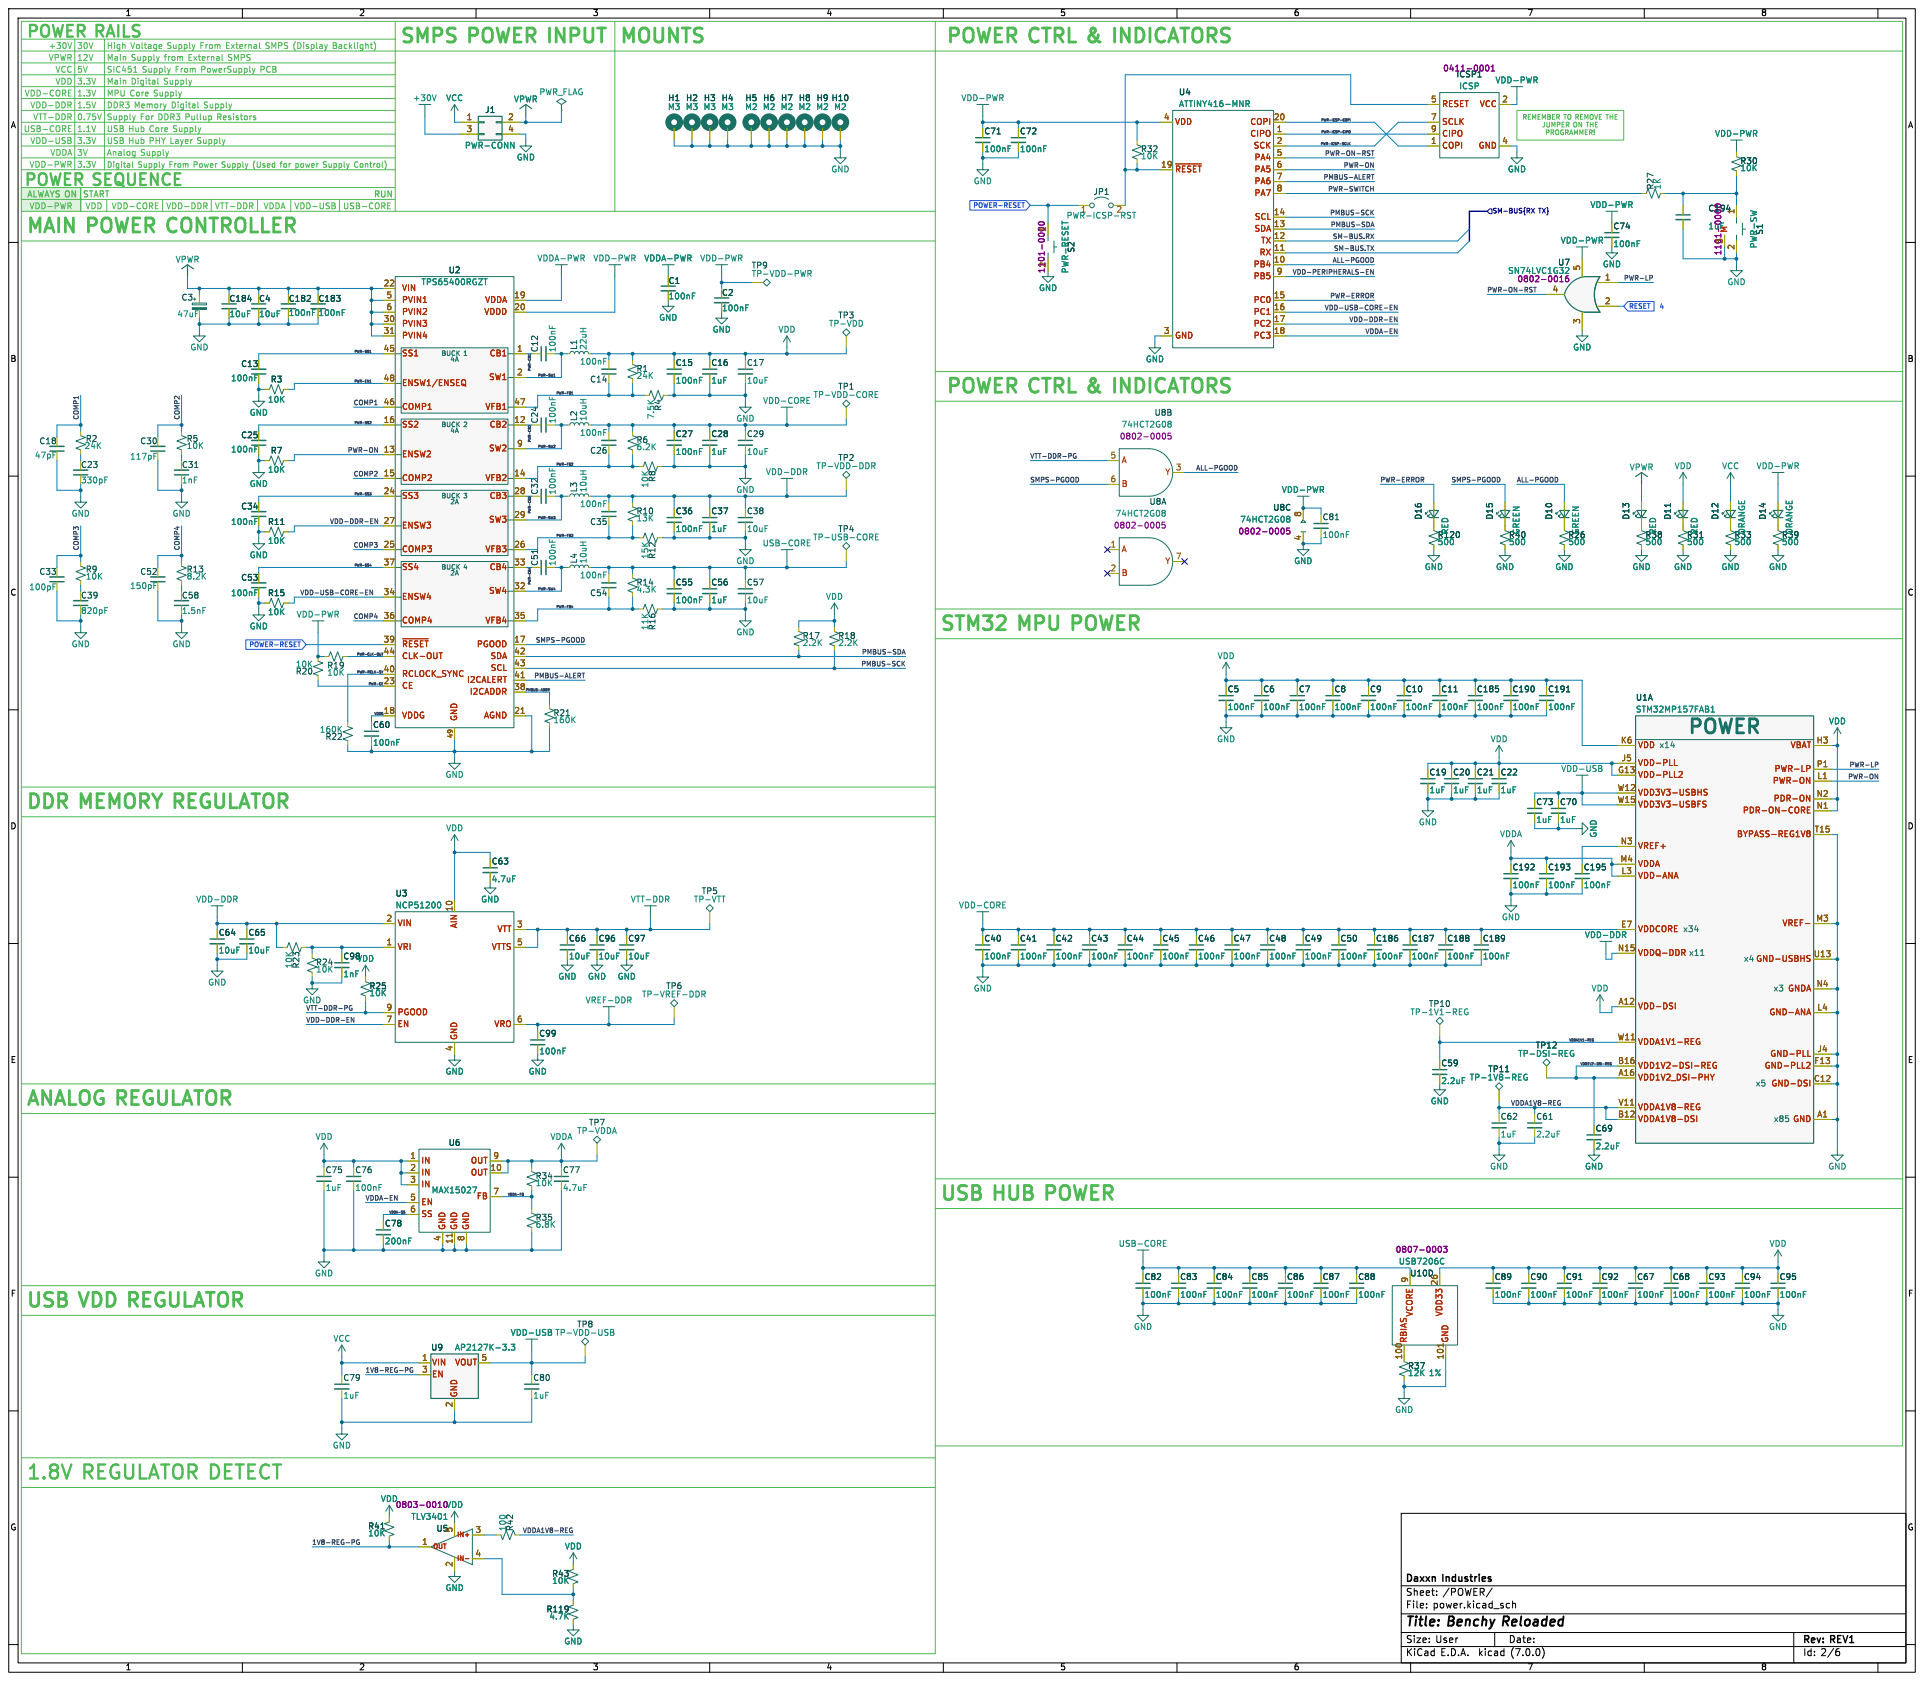
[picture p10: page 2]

30V USB VDD REGULATOR
Supply For DDR3 Pullup Resistors VDD-PWR ANALOG REGULATOR
1.1V MAIN POWER CONTROLLER

Digital Supply From Power Supply (Used for power Supply Control) POWER

High Voltage Supply From External SMPS (Display Backlight) VDD-DDR
SIC451 Supply From PowerSupply PCB Main Supply from External SMPS
VTT-DDR POWER SEQUENCE

JP1 PWR-ICSP-RST VDD-PWR GND

VDD-USB USB Hub Core Supply

PWR-ICSP-COPI PWR-ON-RST

VDDA 3V
VTT-DDR-PG VDD-PWR

100nF VDDA-PWR VDD-PWR

PWR-ON
PMBUS-ALERT PWR-SWITCH

POWER-RESET VDD-USB-CORE-EN

PWR-ERROR
VDD-USB-CORE-EN

J5 VDD
J4 VDD-PLL
P1 BYPASS-REG1V8 T15 GND-USBHS U13 VDDA1V8-REG
L1 VDD-ANA

4 VTTS 5 VRO 6 EN 7 PGOOD 9 U3 NCP51200 GND

4 VTTS 5 VRO 6 EN 7 PGOOD 9 GND GND

TP6 TP-VREF-DDR GND

2 EN 3 VOUT 5 U9 AP2127K-3.3 VREF-DDR GND

4 EN 5 SS 6 FB 7 GND

Id: 2/6 Title: Benchy Reloaded

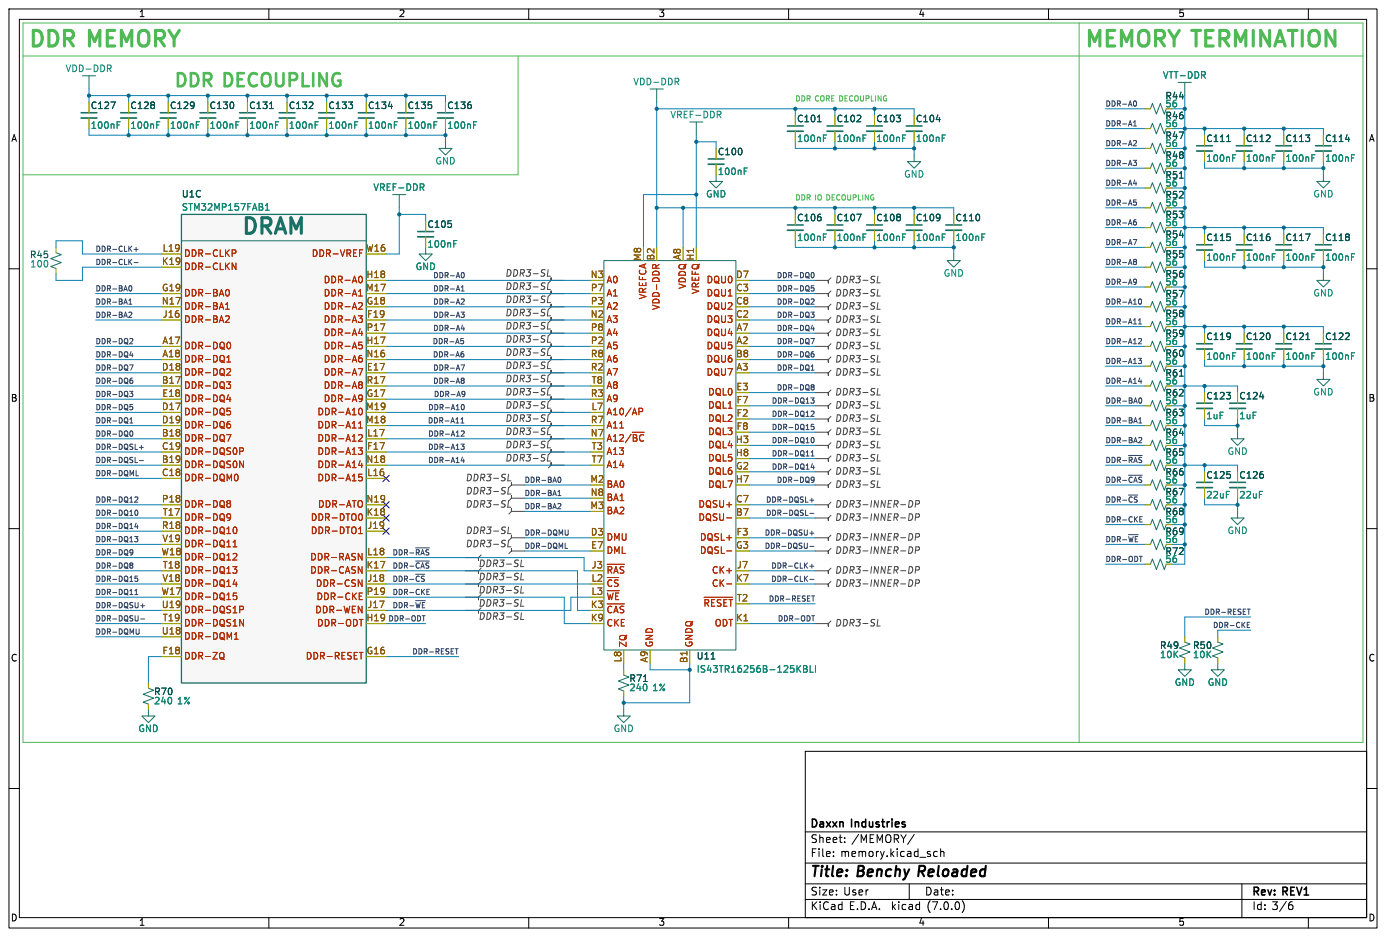
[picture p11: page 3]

DDR IO DECOUPLING DDR DECOUPLING

Id: 3/6 Title: Benchy Reloaded

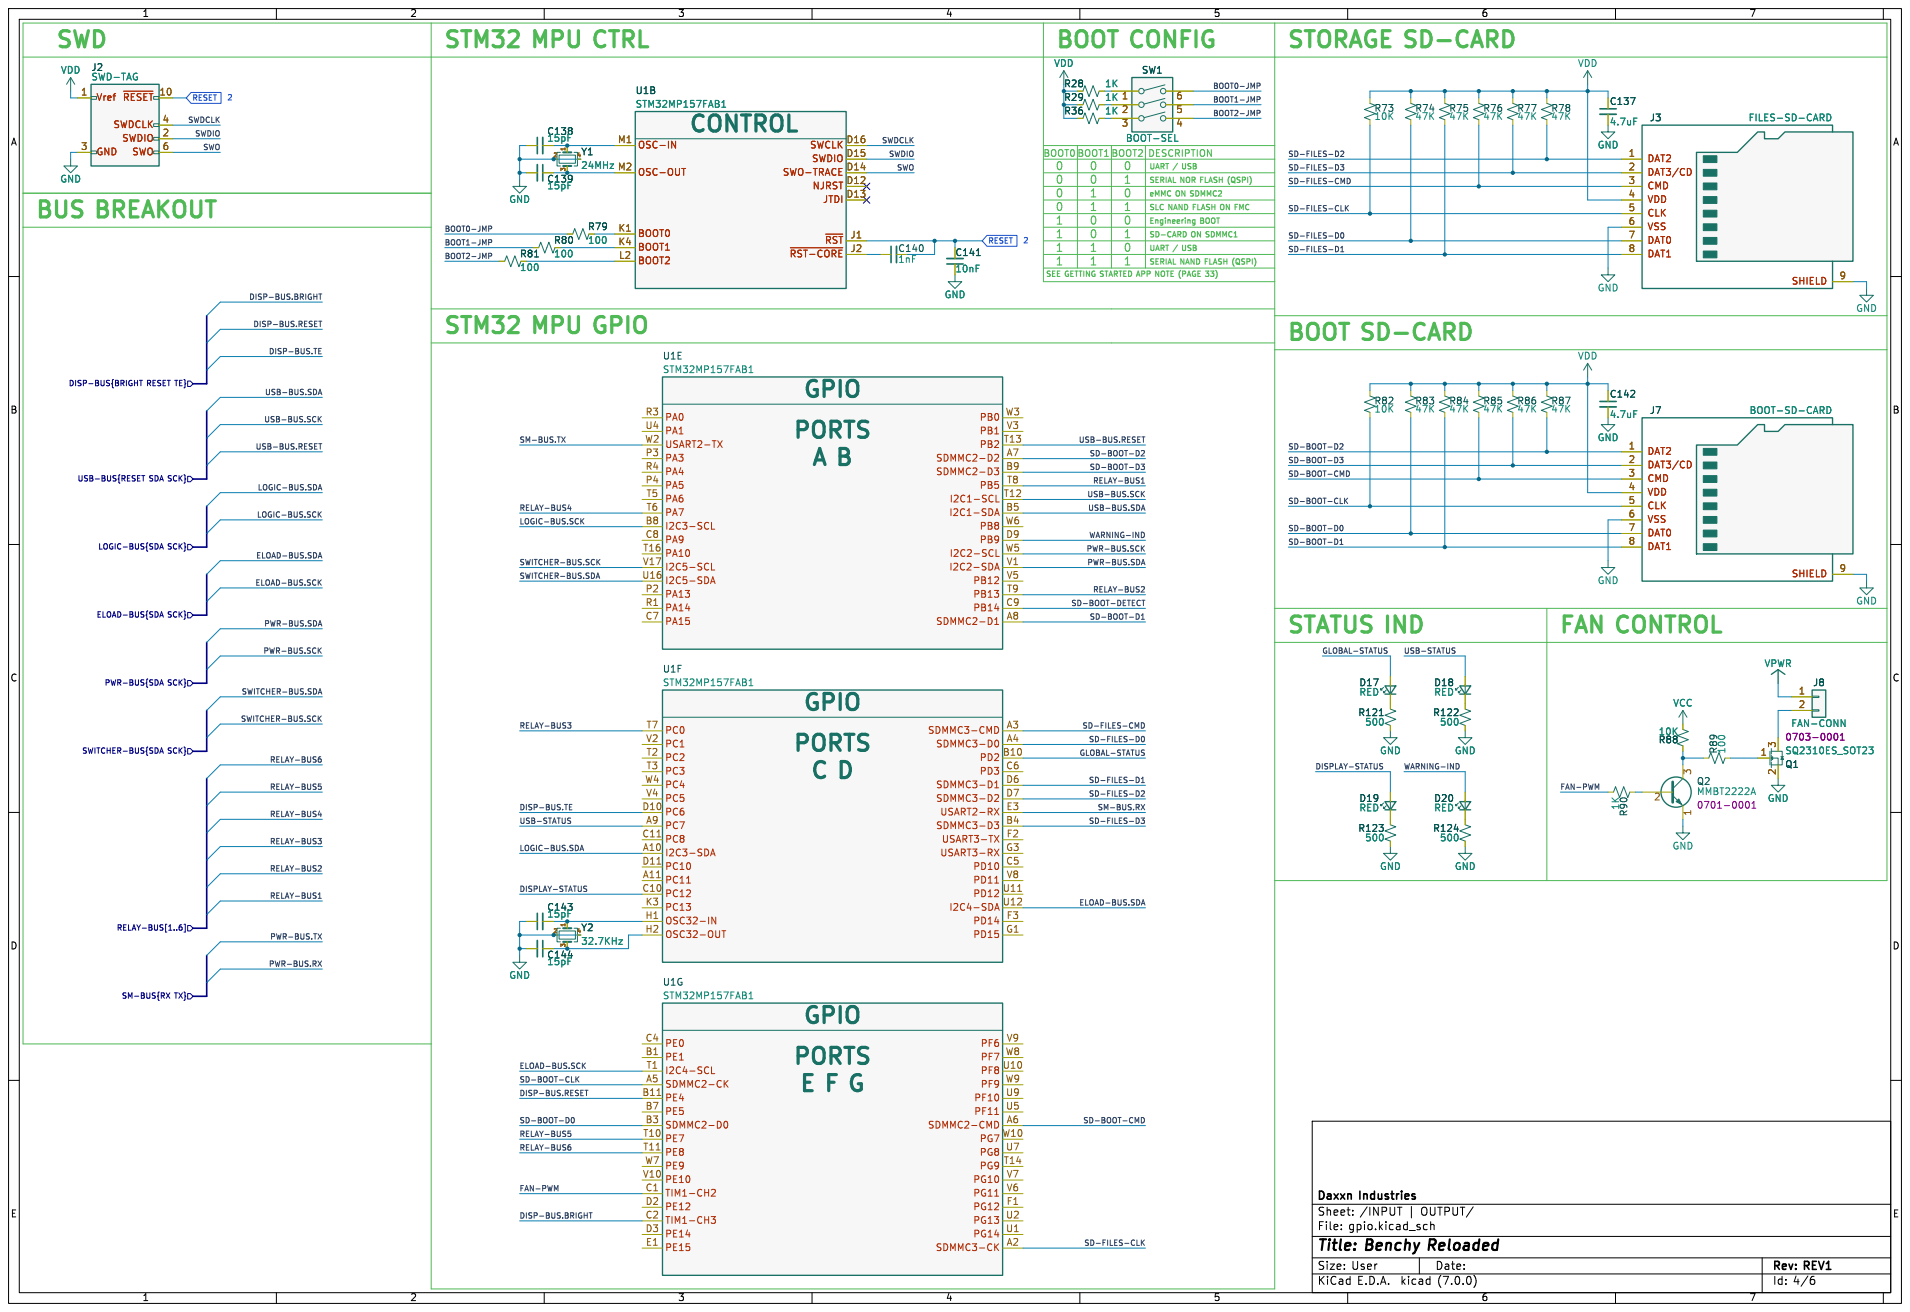
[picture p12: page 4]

SD-FILES-D0 SD-FILES-D3

SERIAL NOR FLASH (QSPI) STM32 MPU GPIO

1 SLC NAND FLASH ON FMC
Engineering BOOT SERIAL NAND FLASH (QSPI) SD-CARD ON SDMMC1 0

USB-BUS.SDA USB-BUS.RESET USB-BUS.SCK DISP-BUS.TE

SD-BOOT-D2 ELOAD-BUS.SCK

SD-BOOT-D1 SD-BOOT-CMD

LOGIC-BUS.SCK RELAY-BUS4

SD-FILES-D3 SWITCHER-BUS.SCK
SWITCHER-BUS.SDA

SD-FILES-D2 SD-FILES-D1 GLOBAL-STATUS

SM-BUS{RX TX}

Id: 4/6 Title: Benchy Reloaded

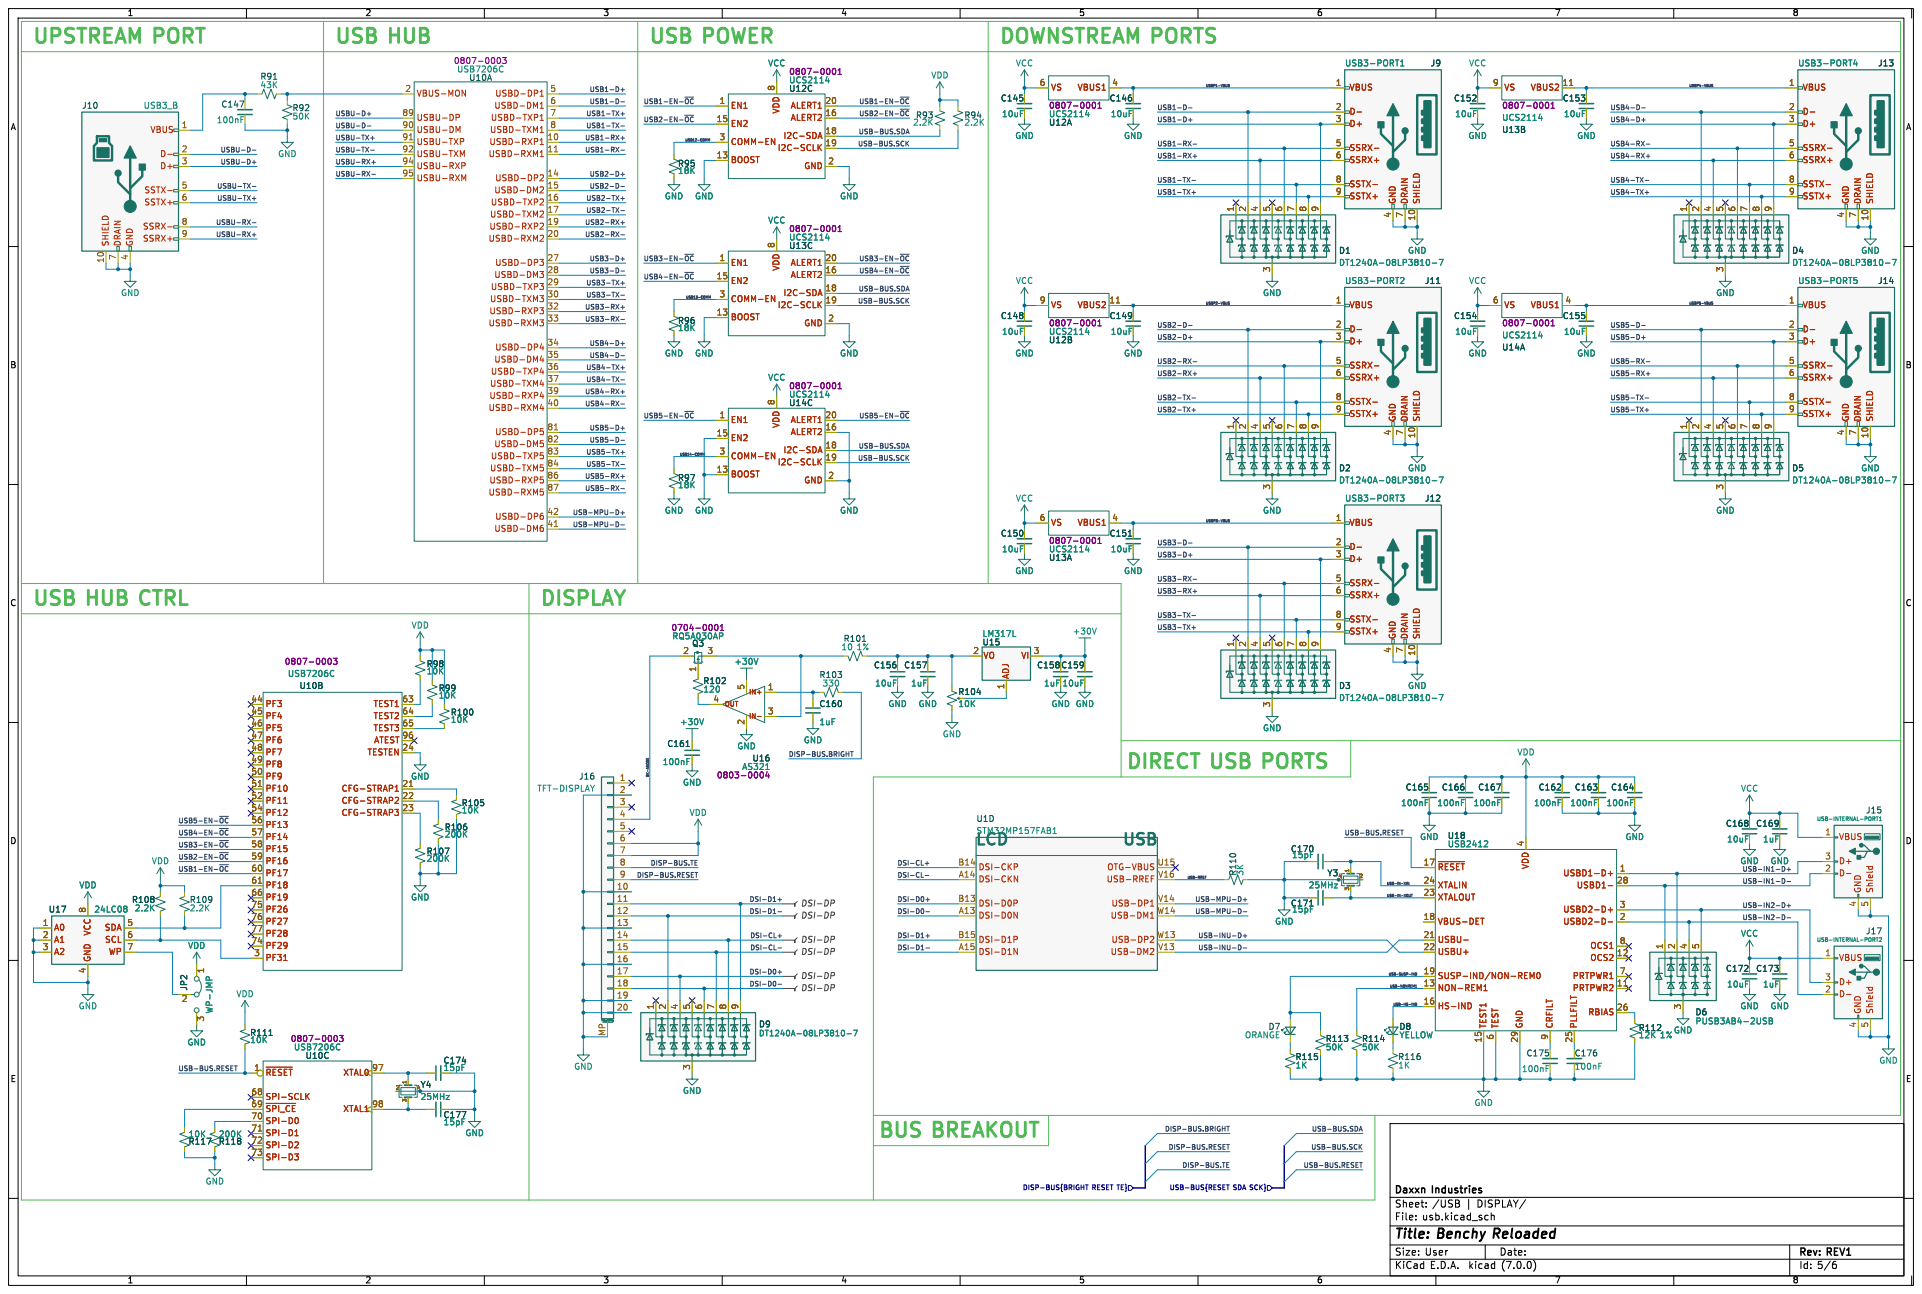
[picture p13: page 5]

USB5-RX+ USB5-RX- USB4-RX+ USB4-RX- USB5-D+ USB4-TX- USB1-D+ USB1-TX+ USB1-D- USB3-D+ USB5-TX+ USB1-TX- USB3-RX- USB5-D- USB2-D-

7 SSTX- 8 SSTX+ 9 USB3-PORT1 J9 VCC GND

USB1-EN-~{OC}
USB1-RX+ USB2-D+ USB3-TX- USB3-RX+ USB3-TX+ USB2-RX+ USB2-RX-

USB2-EN-~{OC}
18K GND GND GND GND

USBP2-VBUS USB2-RX- USB2-RX+ USB2-D+ USB2-D- USB2-TX- USB2-TX+ USBU-RX+
USBU-RX-

7 SSTX- 8 SSTX+ 9 GND GND GND

7 SSTX- 8 SSTX+ 9 USB3-PORT2 J11 VBUS 1 SHIELD 10 D- 2 D+ 3 GND

USB-IN-XIN USB-BUS.RESET

USB-RREF DISP-BUS.TE

DSI-DP DSI-DP DSI-DP

USB-MPU-D- USB-MPU-D+

4 SDA 5 SCL 6 WP 7 VCC

USB-NONREM1 USB-HS-IND

USB-BUS.RESET USB-BUS.SCK

Id: 5/6 Title: Benchy Reloaded

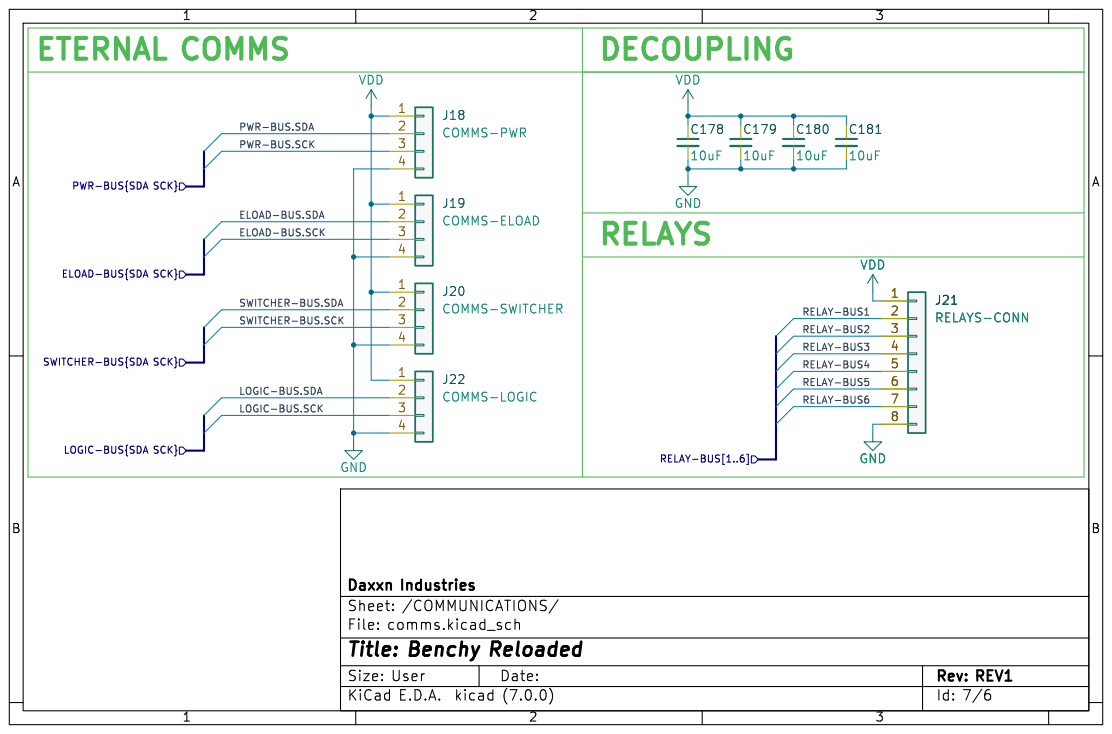
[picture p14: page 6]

VDD

Id: 7/6 Title: Benchy Reloaded

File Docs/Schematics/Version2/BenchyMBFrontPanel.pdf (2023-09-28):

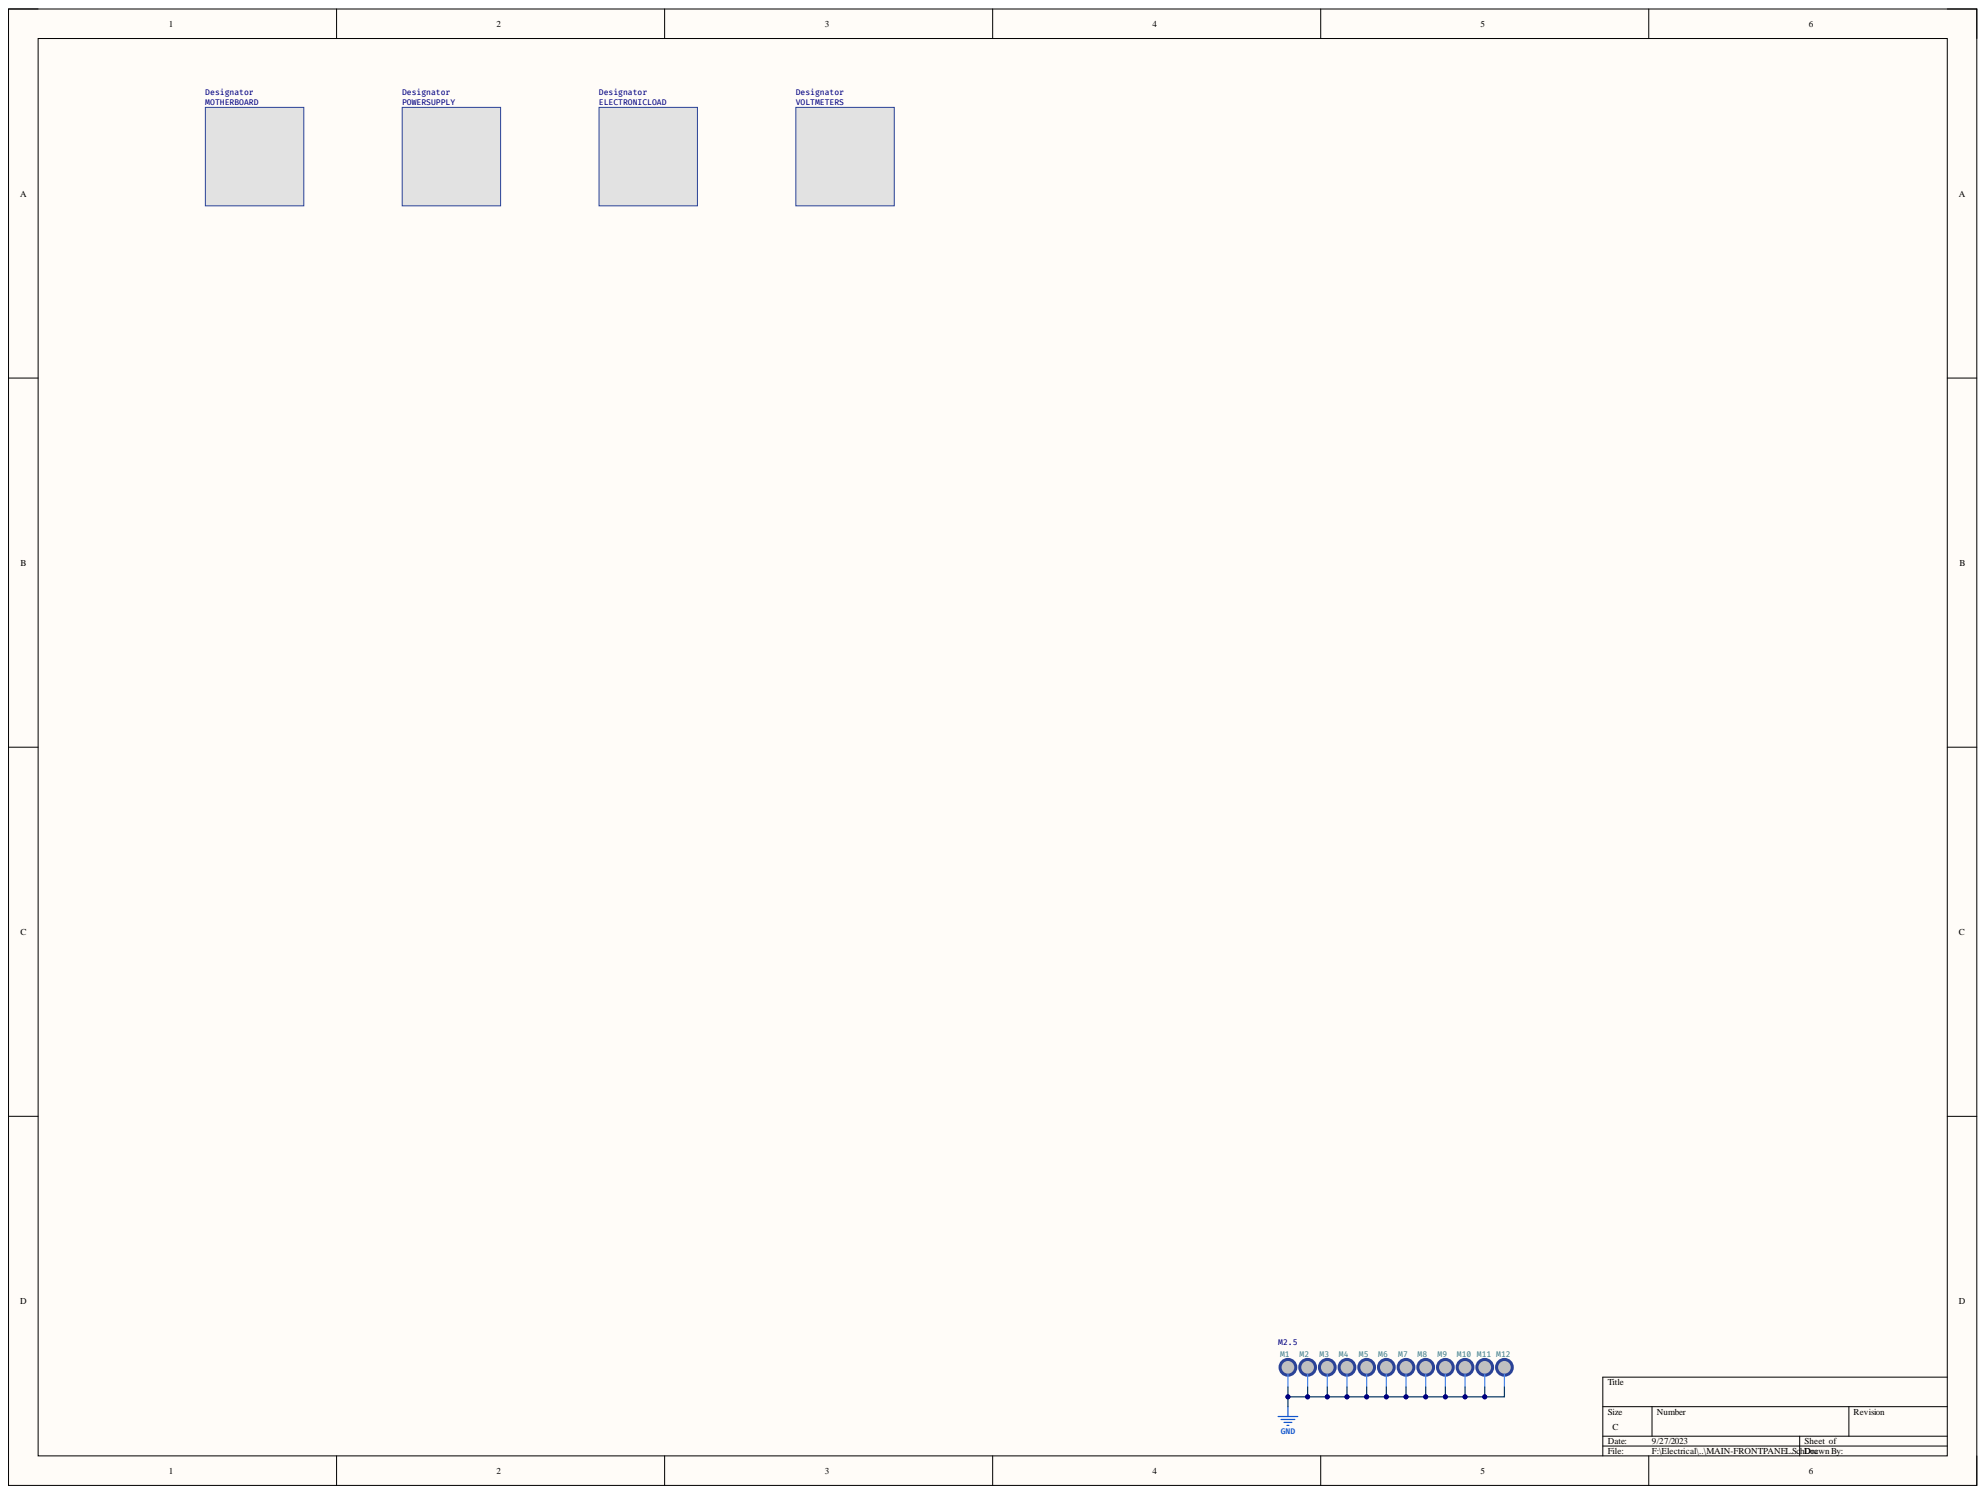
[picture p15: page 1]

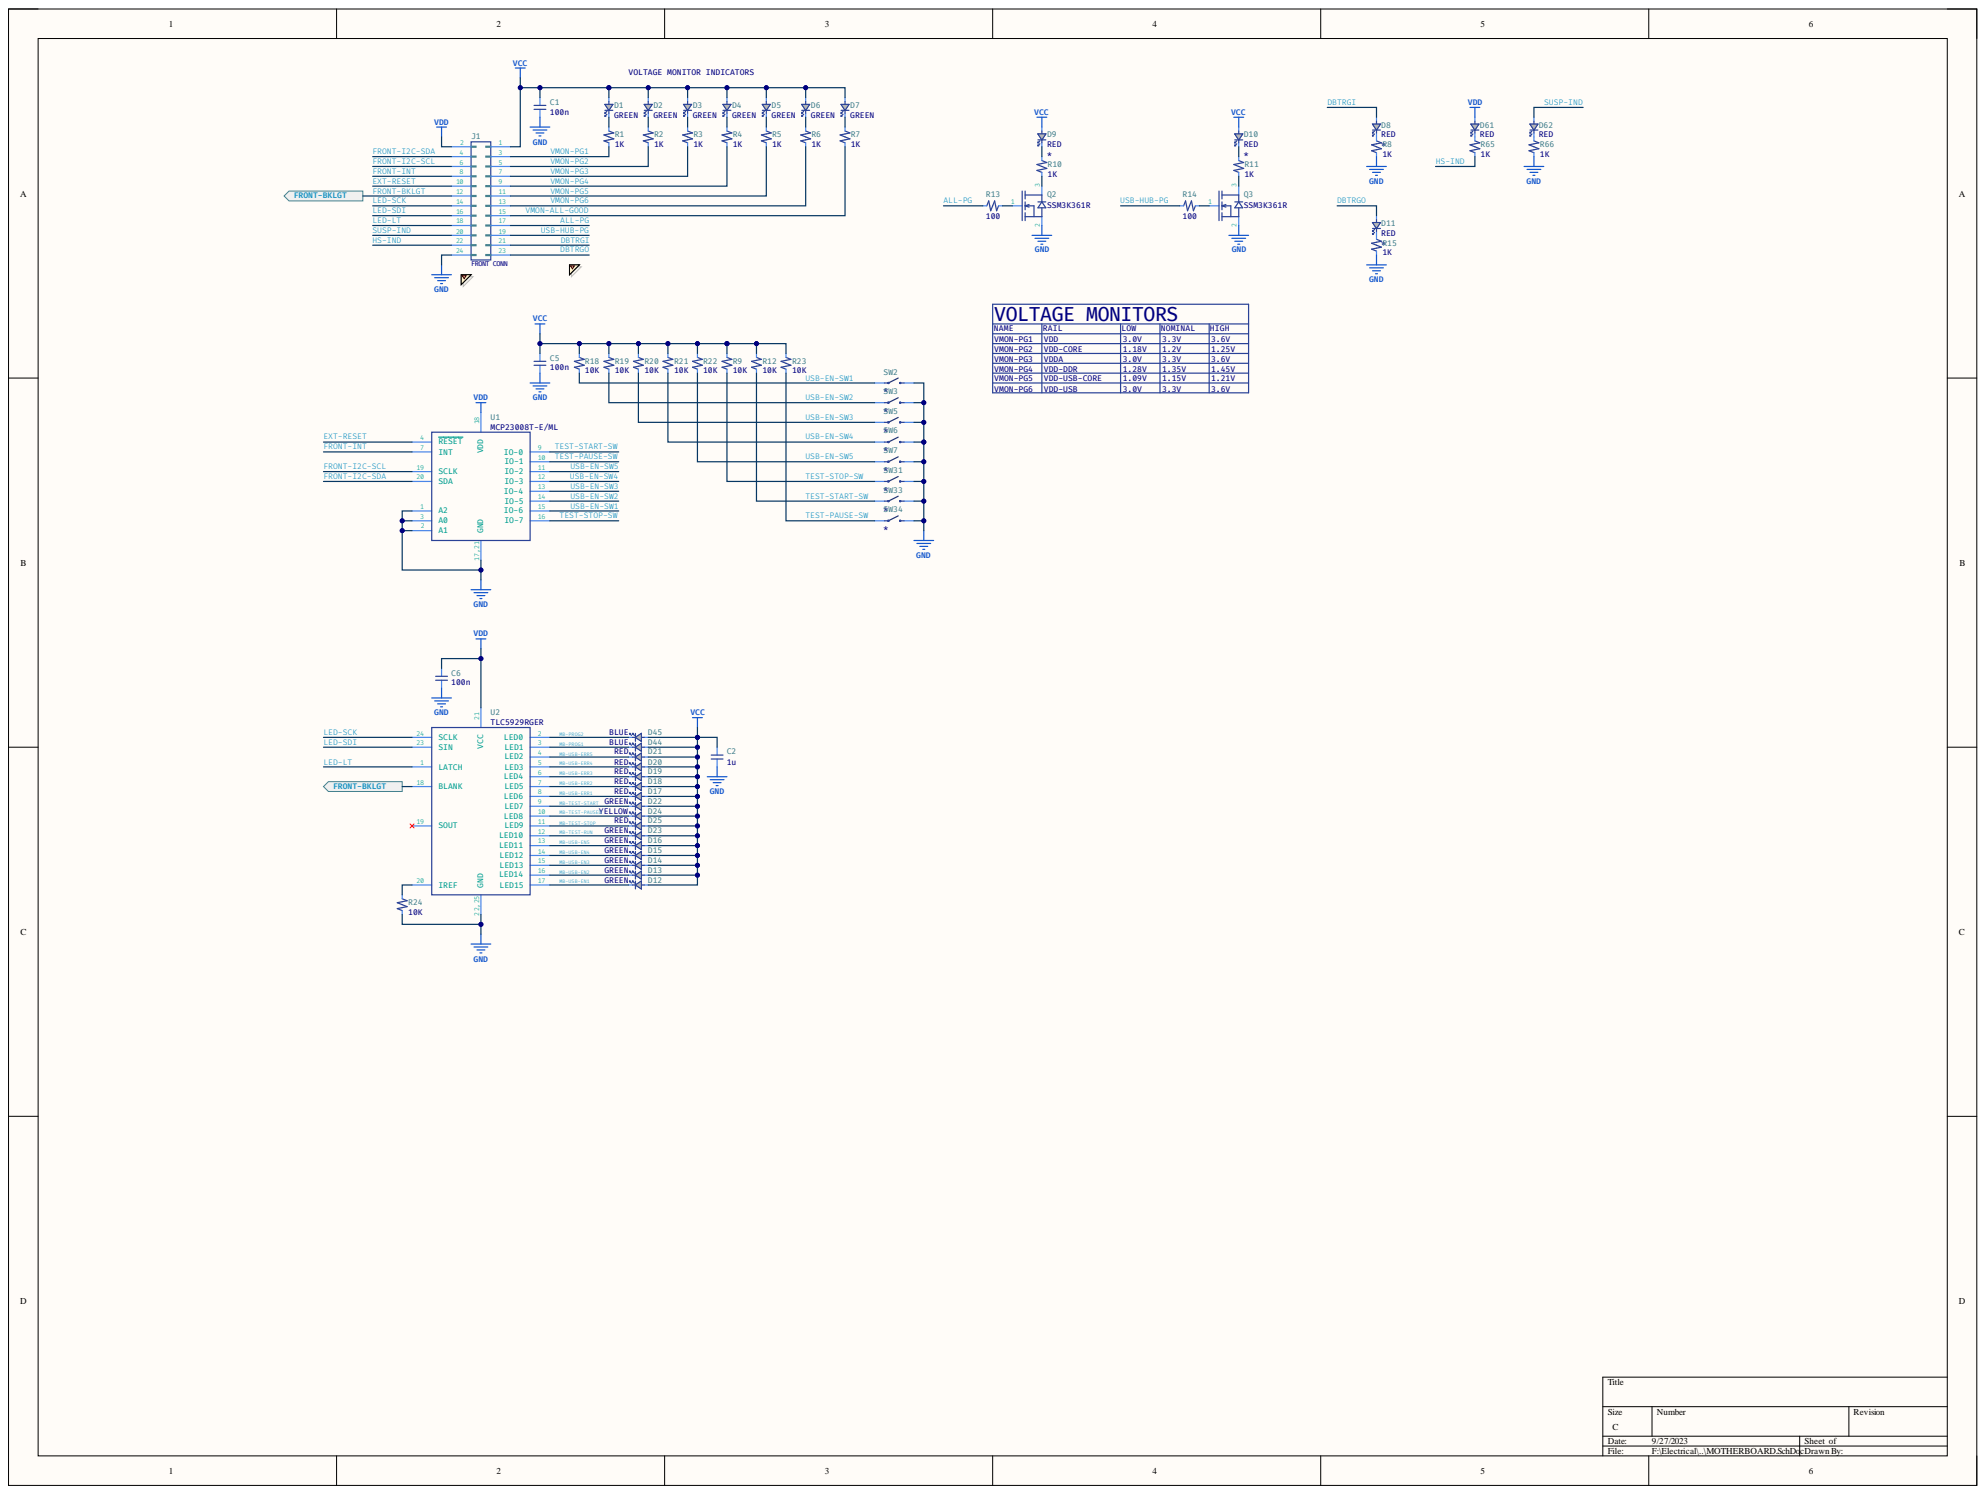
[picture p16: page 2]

NAME | RAIL | LOW | NOMINAL | HIGH
VMON-PG1 | VDD | 3.0V | 3.3V | 3.6V
VMON-PG2 | VDD-CORE | 1.18V | 1.2V | 1.25V
VMON-PG3 | VDDA | 3.0V | 3.3V | 3.6V
VMON-PG4 | VDD-DDR | 1.28V | 1.35V | 1.45V
VMON-PG5 | VDD-USB-CORE | 1.09V | 1.15V | 1.21V
VMON-PG6 | VDD-USB | 3.0V | 3.3V | 3.6V

USB-EN-SW3

USB-EN-SW4

USB-EN-SW5

TEST-STOP-SW

TEST-START-SW

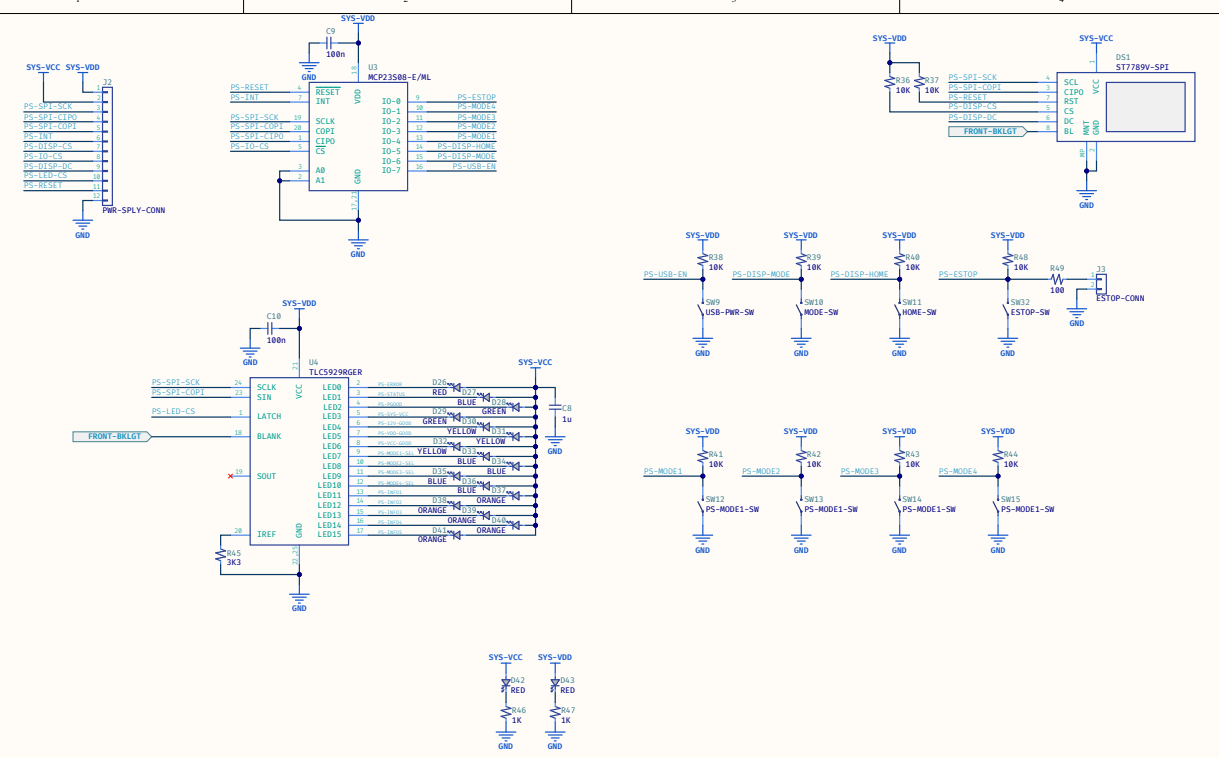
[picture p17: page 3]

SYS-VCC SYS-VDD

CIPO 3 SCL 4

PS-RESET PS-DISP-CS | RST 7 CS 5

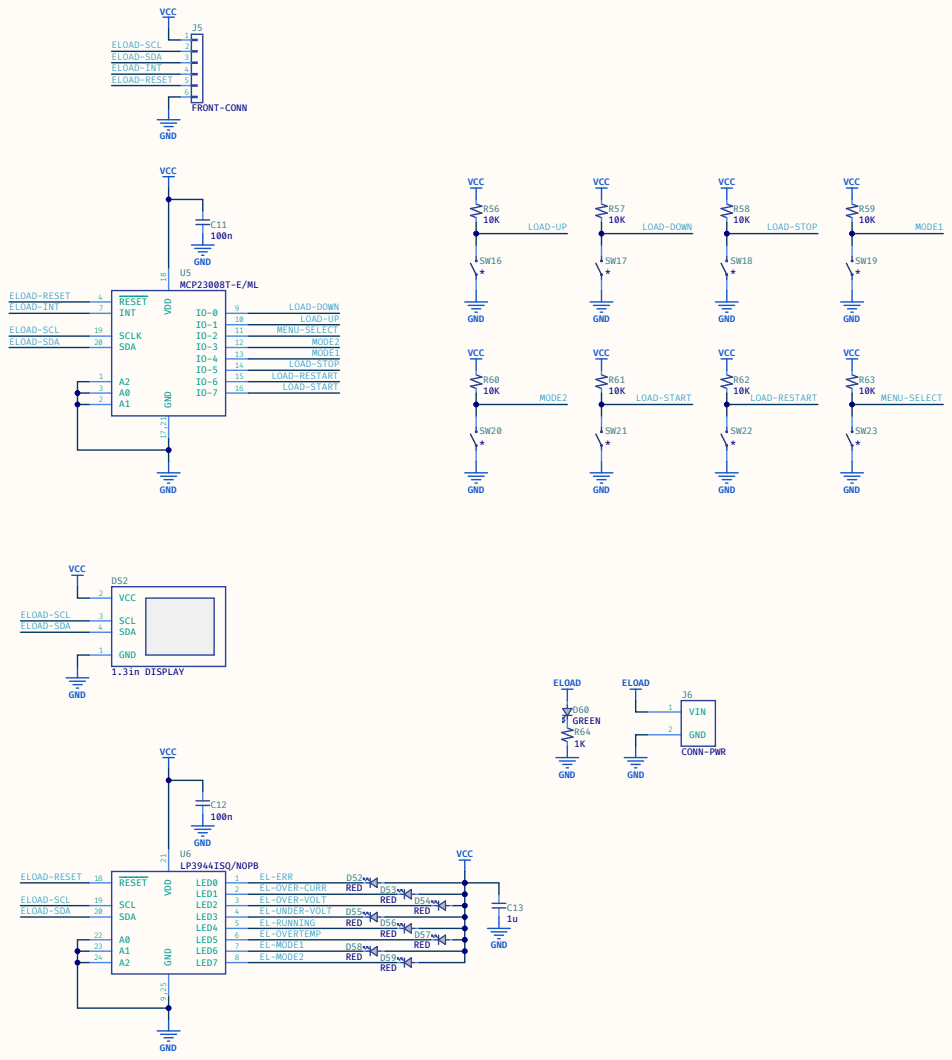
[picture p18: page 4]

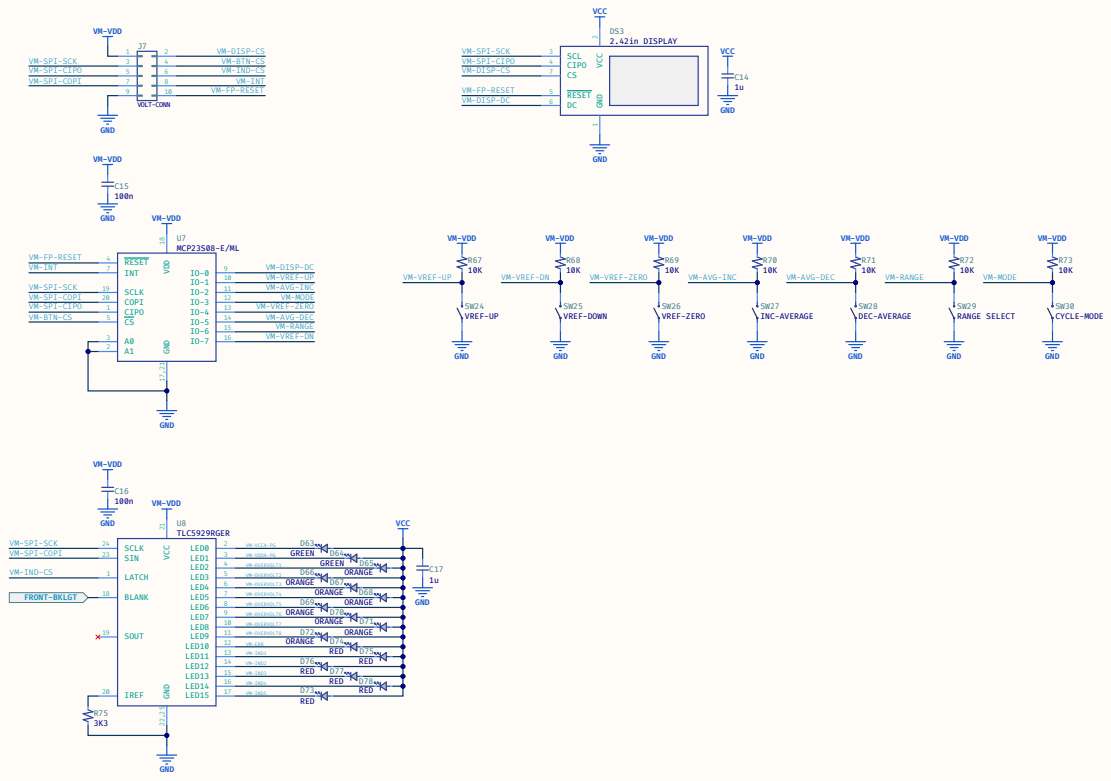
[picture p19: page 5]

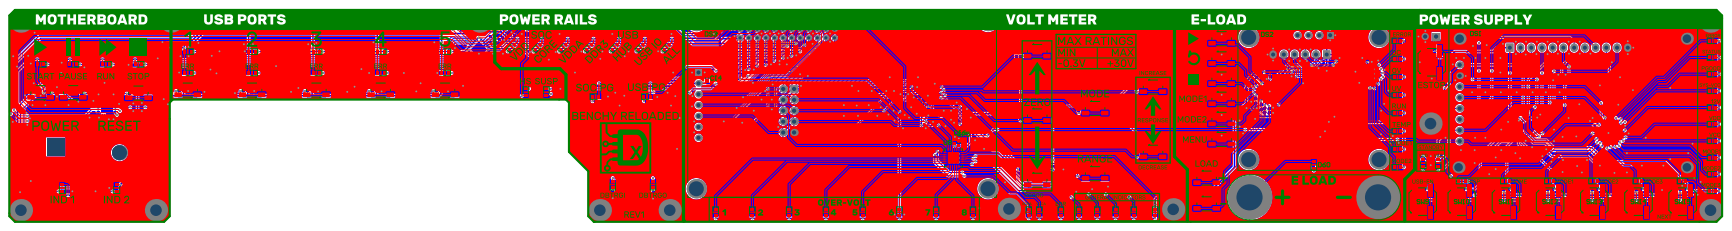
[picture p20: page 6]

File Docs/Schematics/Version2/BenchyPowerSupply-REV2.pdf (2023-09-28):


This line to the MC needs to be
set as Open-Emitter to avoid
overriding the voltage divider.
SMBUS-EN

Date: 9/02/2023 | Sheet of
File: F:\Electrical\..\MAIN-POWERSUPPLY.SchDrDoawn c By:









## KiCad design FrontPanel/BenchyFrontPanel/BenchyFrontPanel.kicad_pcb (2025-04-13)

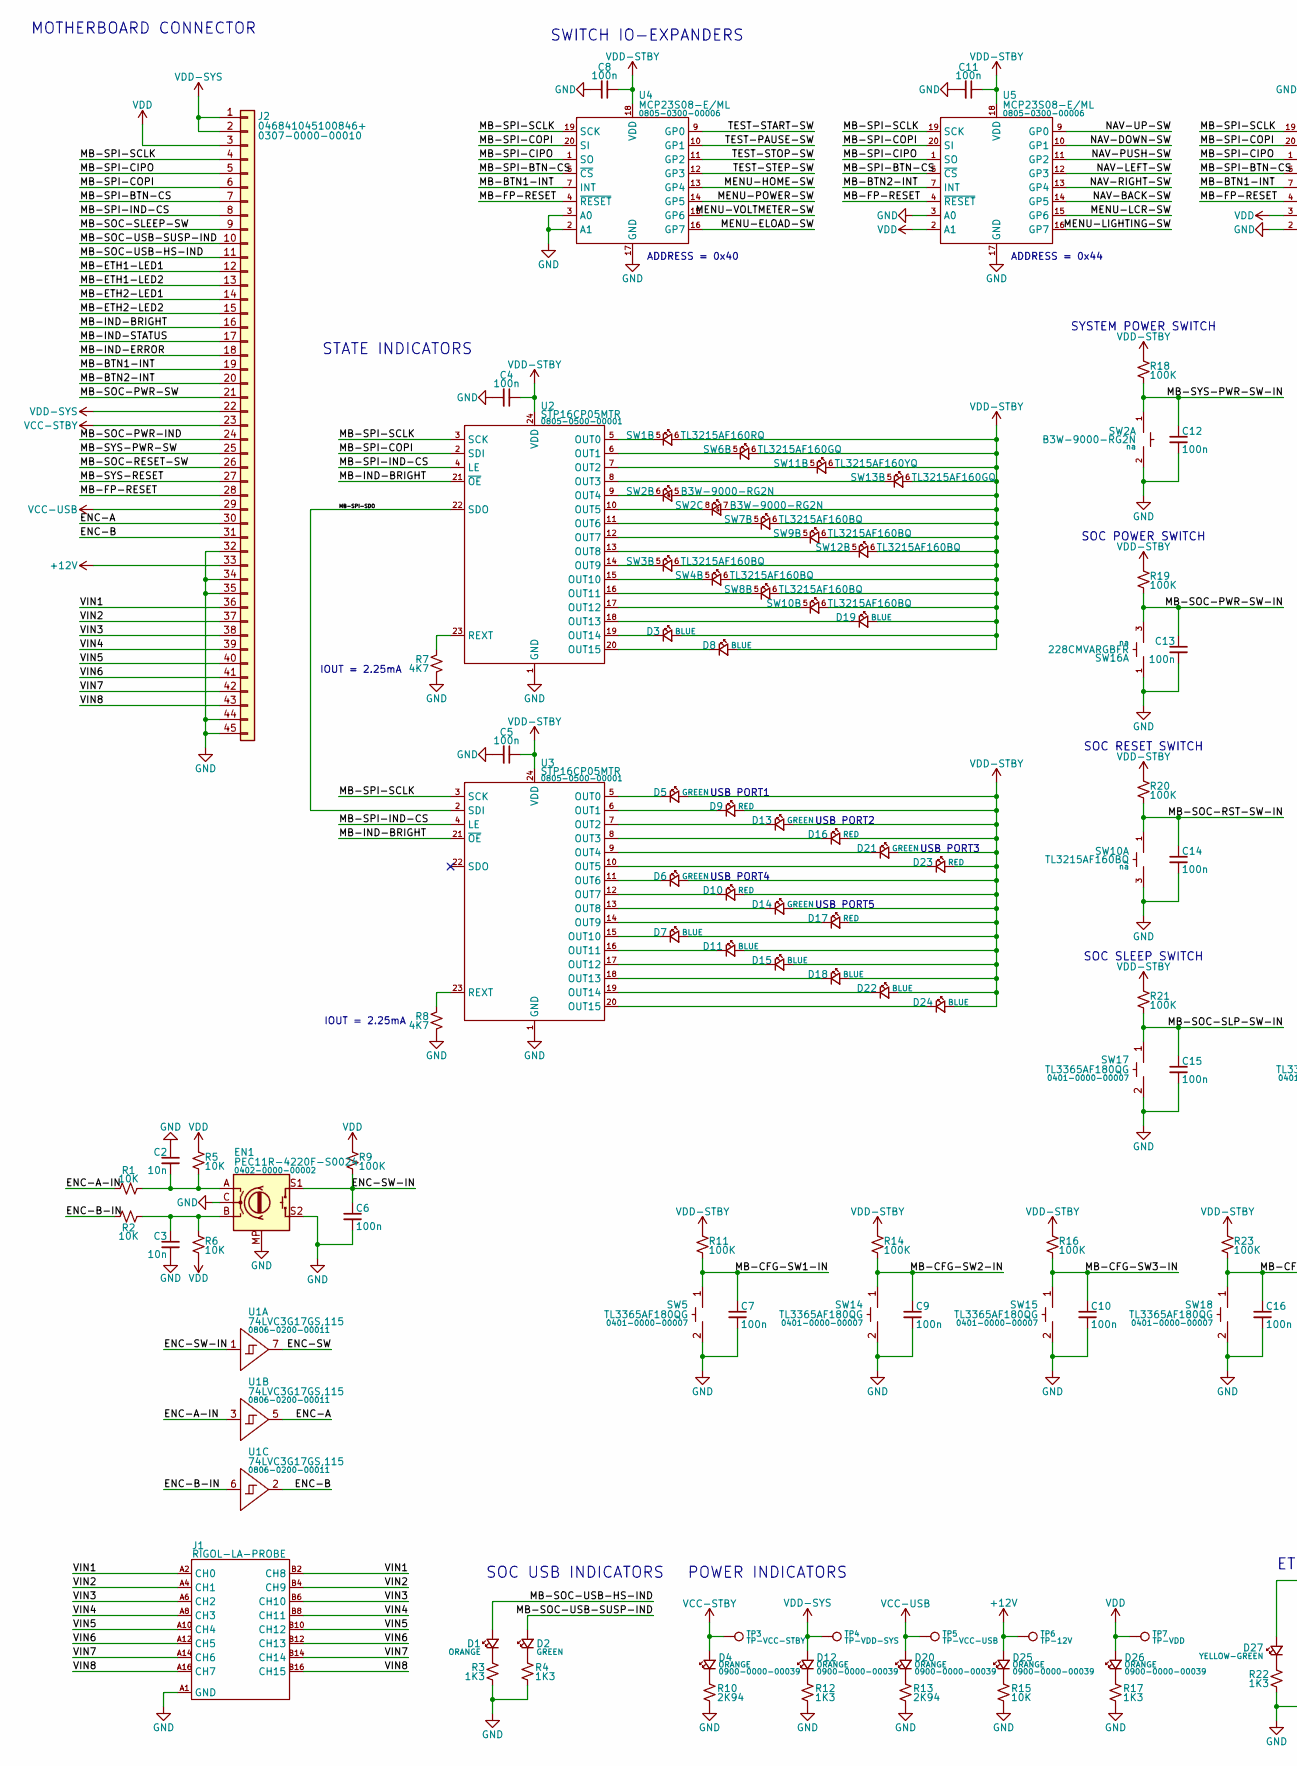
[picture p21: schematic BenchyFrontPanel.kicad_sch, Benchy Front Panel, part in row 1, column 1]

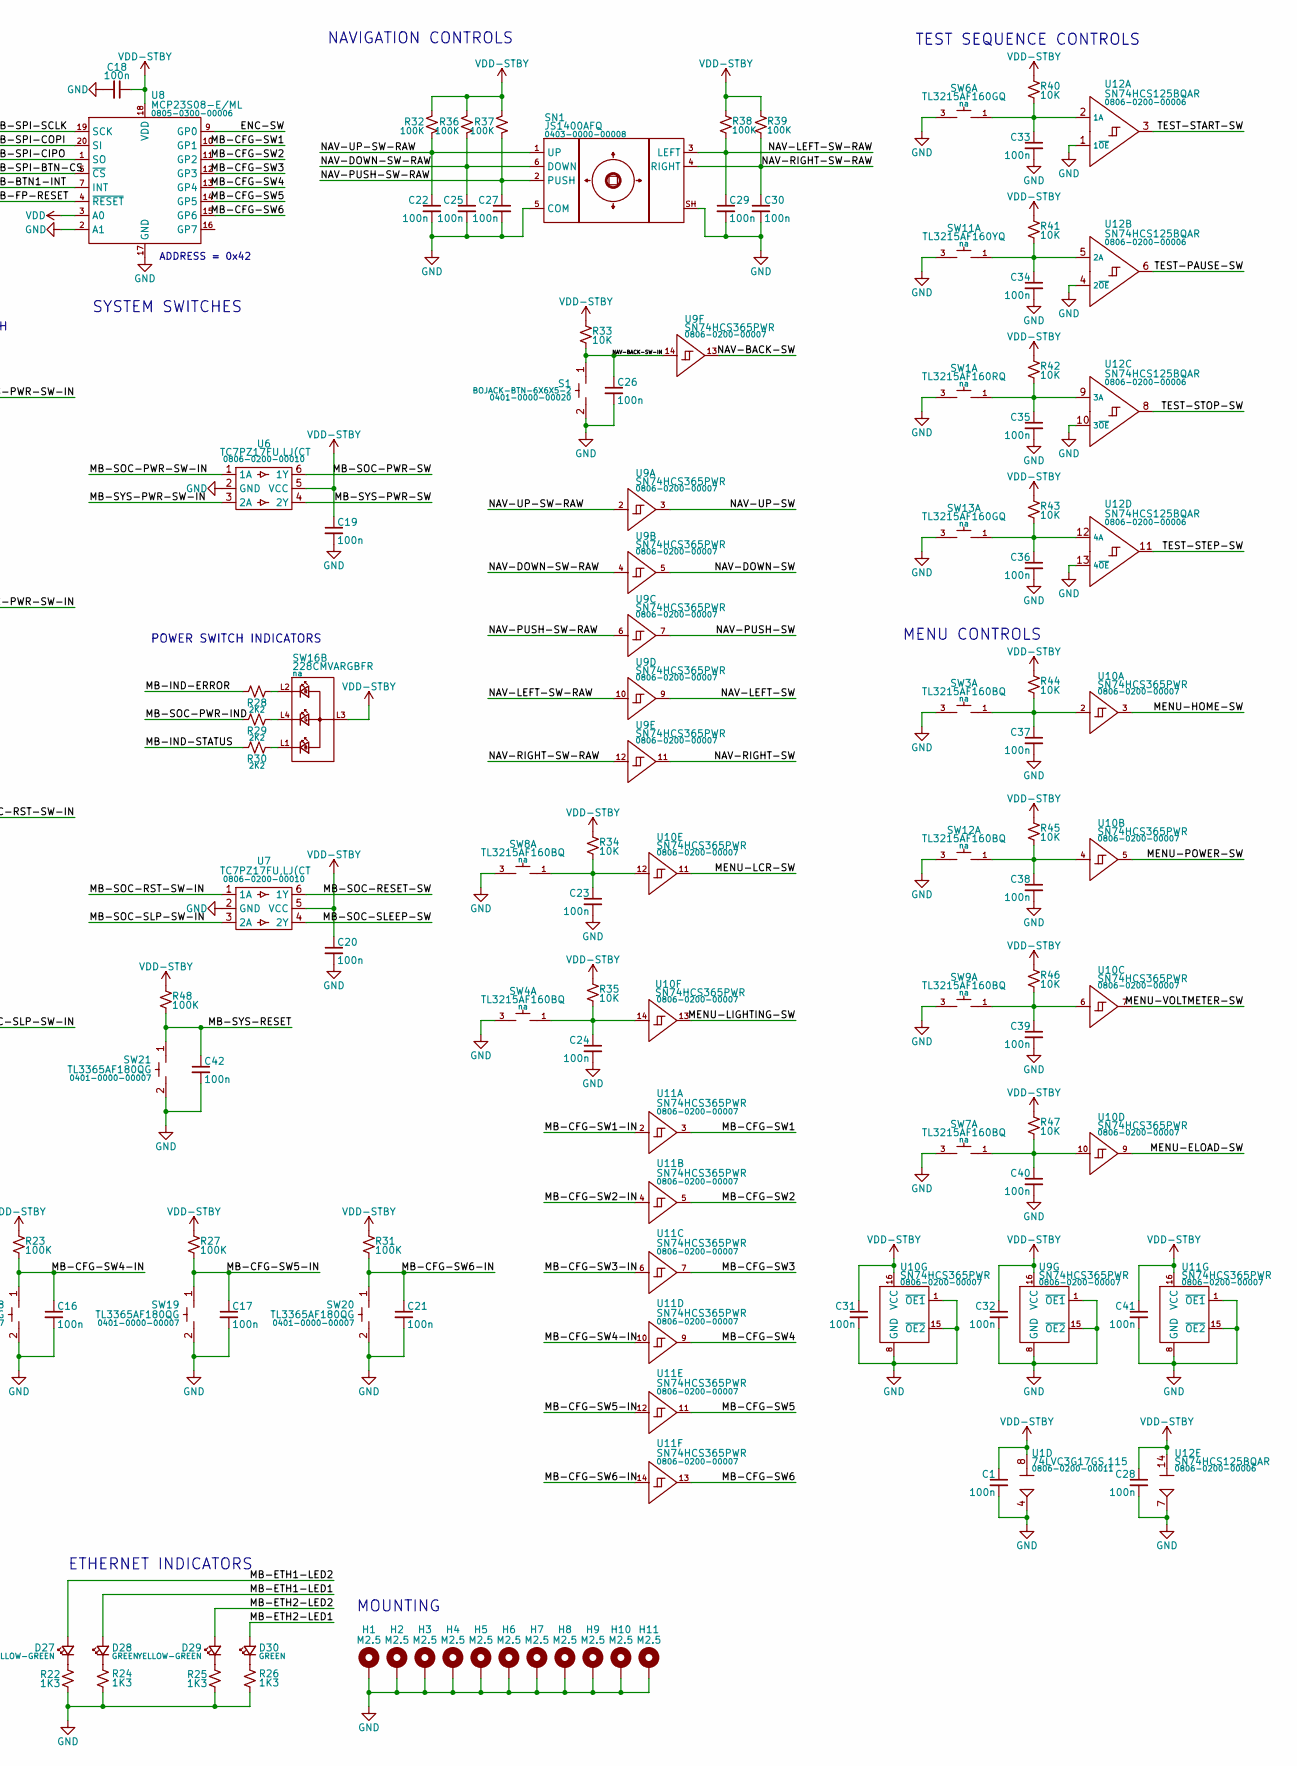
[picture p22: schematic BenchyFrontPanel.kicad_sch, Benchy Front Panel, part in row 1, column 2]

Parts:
C1, C4, C5, C6, C7, C8, C9, C10, C11, C12, C13, C14, C15, C16, C17, C18, C19, C20, C21, C22, C23, C24, C25, C26, C27, C28, C29, C30, C31, C32, C33, C34, C35, C36, C37, C38, C39, C40, C41, C42: 100n; CAP_0402; PartNumber 0201-0100-00086
C2, C3: 10n; CAP_0402; PartNumber 0201-0100-00031
D1, D4, D12, D20, D25, D26: CZ3-0603-ORANGE; LED_0603_1608Metric; PartNumber 0900-0000-00039
D2, D5, D6, D13, D14, D21, D28, D30: CZ2-0603-GREEN; LED_0603_1608Metric; PartNumber 0900-0000-00038
D3, D7, D8, D11, D15, D18, D19, D22, D24: CZ1-0603-BLUE; LED_0603_1608Metric; PartNumber 0900-0000-00037
D9, D10, D16, D17, D23: CZ5-0603-RED; LED_0603_1608Metric; PartNumber 0900-0000-00041
D27, D29: CZ8-0603-YLW-GREEN; LED_0603_1608Metric; PartNumber 0900-0000-00044
EN1: PEC11R-4220F-S0024; PEC11R; PartNumber 0402-0000-00002
H1, H2, H3, H4, H5, H6, H7, H8, H9, H10, H11: M2.5; MountingHole_2.7mm_M2.5_ISO7380_Pad
J1: RIGOL-LA-PROBE; 10018784-10200TLF; PartNumber na
J2: 046841045100846+; PartNumber 0307-0000-00010
R1, R2, R5, R6, R15, R33, R34, R35, R40, R41, R42, R43, R44, R45, R46, R47: 10K; RES_0402; PartNumber 0204-0000-00016
R3, R4, R12, R17, R22, R24, R25, R26: 1K3; RES_0402; PartNumber 0204-0000-00004
R7, R8: 4K7; RES_0402; PartNumber 0204-0000-00068
R9, R11, R14, R16, R18, R19, R20, R21, R23, R27, R31, R32, R36, R37, R38, R39, R48: 100K; RES_0402; PartNumber 0204-0000-00013
R10, R13: 2K94; RES_0402; PartNumber 0204-0000-00039
R28, R29, R30: 2K2; RES_0402; PartNumber 0204-0000-00033
S1: BOJACK-BTN-6X6X5-2; BOJACK-BTN-6x6x5; PartNumber 0401-0000-00020
SN1: JS1400AFQ; JS1400; PartNumber 0403-0000-00008
SW1: TL3215AF160RQ; TL3215A; PartNumber na
SW2: B3W-9000-RG2N; B3W-9000; PartNumber na
SW3, SW4, SW7, SW8, SW9, SW10, SW12: TL3215AF160BQ; TL3215A; PartNumber na
SW5, SW14, SW15, SW17, SW18, SW19, SW20, SW21: TL3365AF180QG; PartNumber 0401-0000-00007
SW6, SW13: TL3215AF160GQ; TL3215A; PartNumber na
SW11: TL3215AF160YQ; TL3215A; PartNumber na
SW16: 228CMVARGBFR; 228C; PartNumber na
TP3: TP-VCC-STBY; TestPoint_Pad_D2.0mm; PartNumber na
TP4: TP-VDD-SYS; TestPoint_Pad_D2.0mm; PartNumber na
TP5: TP-VCC-USB; TestPoint_Pad_D2.0mm; PartNumber na
TP6: TP-12V; TestPoint_Pad_D2.0mm; PartNumber na
TP7: TP-VDD; TestPoint_Pad_D2.0mm; PartNumber na
U1: 74LVC3G17GS,115; X2SON-8_1.4x1mm_P0.35mm; PartNumber 0806-0200-00011
U2, U3: STP16CP05MTR; SOIC-24W_7.5x15.4mm_P1.27mm; PartNumber 0805-0500-00001
U4, U5, U8: MCP23S08-E/ML; QFN-20-1EP_4x4mm_P0.5mm_EP2.7x2.7mm; PartNumber 0805-0300-00006
U6, U7: TC7PZ17FU,LJ(CT; SOT-363_SC-70-6; PartNumber 0806-0200-00010
U9, U10, U11: SN74HCS365PWR; TSSOP-16_4.4x5mm_P0.65mm; PartNumber 0806-0200-00007
U12: SN74HCS125BQAR; WQFN-14_B3x2.5mm_P0.5mm; PartNumber 0806-0200-00006

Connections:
+12V: D25.2 (A), J2.33, TP6.1 (TP)
/ENC-A: J2.30, U1.5 (2Y)
/ENC-A-IN: R1.1, U1.3 (2A)
/ENC-B: J2.31, U1.2 (3Y)
/ENC-B-IN: R2.1, U1.6 (3A)
/ENC-SW: U1.7 (1Y), U8.9 (GP0)
/ENC-SW-IN: C6.1, EN1.S1, R9.2, U1.1 (1A)
/MB-BTN1-INT: J2.19, U4.7 (INT), U8.7 (INT)
/MB-BTN2-INT: J2.20, U5.7 (INT)
/MB-CFG-SW1: U8.10 (GP1), U11.3 (Y1)
/MB-CFG-SW1-IN: C7.1, R11.2, SW5.1, U11.2 (A1)
/MB-CFG-SW2: U8.11 (GP2), U11.5 (Y2)
/MB-CFG-SW2-IN: C9.1, R14.2, SW14.1, U11.4 (A2)
/MB-CFG-SW3: U8.12 (GP3), U11.7 (Y3)
/MB-CFG-SW3-IN: C10.1, R16.2, SW15.1, U11.6 (A3)
/MB-CFG-SW4: U8.13 (GP4), U11.9 (Y4)
/MB-CFG-SW4-IN: C16.1, R23.2, SW18.1, U11.10 (A4)
/MB-CFG-SW5: U8.14 (GP5), U11.11 (Y5)
/MB-CFG-SW5-IN: C17.1, R27.2, SW19.1, U11.12 (A5)
/MB-CFG-SW6: U8.15 (GP6), U11.13 (Y6)
/MB-CFG-SW6-IN: C21.1, R31.2, SW20.1, U11.14 (A6)
/MB-ETH1-LED1: D28.2 (A), J2.12
/MB-ETH1-LED2: D27.2 (A), J2.13
/MB-ETH2-LED1: D30.2 (A), J2.14
/MB-ETH2-LED2: D29.2 (A), J2.15
/MB-FP-RESET: J2.28, U4.4 (~RESET), U5.4 (~RESET), U8.4 (~RESET)
/MB-IND-BRIGHT: J2.16, U2.21 (~OE), U3.21 (~OE)
/MB-IND-ERROR: J2.18, R28.1
/MB-IND-STATUS: J2.17, R30.1
/MB-SOC-PWR-IND: J2.24, R29.1
/MB-SOC-PWR-SW: J2.21, U6.6 (1Y)
/MB-SOC-PWR-SW-IN: C13.1, R19.2, SW16.3 (SWB), SW16.4 (SWB), U6.1 (1A)
/MB-SOC-RESET-SW: J2.26, U7.6 (1Y)
/MB-SOC-RST-SW-IN: C14.1, R20.2, SW10.1 (SWA), SW10.2 (SWA), U7.1 (1A)
/MB-SOC-SLEEP-SW: J2.9, U7.4 (2Y)
/MB-SOC-SLP-SW-IN: C15.1, R21.2, SW17.1, U7.3 (2A)
/MB-SOC-USB-HS-IND: D1.2 (A), J2.11
/MB-SOC-USB-SUSP-IND: D2.2 (A), J2.10
/MB-SPI-BTN-CS: J2.7, U4.5 (~CS), U5.5 (~CS), U8.5 (~CS)
/MB-SPI-CIPO: J2.5, U4.1 (SO), U5.1 (SO), U8.1 (SO)
/MB-SPI-COPI: J2.6, U2.2 (SDI), U4.20 (SI), U5.20 (SI), U8.20 (SI)
/MB-SPI-IND-CS: J2.8, U2.4 (LE), U3.4 (LE)
/MB-SPI-SCLK: J2.4, U2.3 (SCK), U3.3 (SCK), U4.19 (SCK), U5.19 (SCK), U8.19 (SCK)
/MB-SPI-SDO: U2.22 (SDO), U3.2 (SDI)
/MB-SYS-PWR-SW: J2.25, U6.4 (2Y)
/MB-SYS-PWR-SW-IN: C12.1, R18.2, SW2.1 (SWA), SW2.3 (SWA), U6.3 (2A)
/MB-SYS-RESET: C42.1, J2.27, R48.2, SW21.1
/MENU-ELOAD-SW: U4.16 (GP7), U10.9 (Y4)
/MENU-HOME-SW: U4.13 (GP4), U10.3 (Y1)
/MENU-LCR-SW: U5.15 (GP6), U10.11 (Y5)
/MENU-LIGHTING-SW: U5.16 (GP7), U10.13 (Y6)
/MENU-POWER-SW: U4.14 (GP5), U10.5 (Y2)
/MENU-VOLTMETER-SW: U4.15 (GP6), U10.7 (Y3)
/NAV-BACK-SW: U5.14 (GP5), U9.13 (Y6)
/NAV-BACK-SW-IN: C26.1, R33.2, S1.1, U9.14 (A6)
/NAV-DOWN-SW: U5.10 (GP1), U9.5 (Y2)
/NAV-DOWN-SW-RAW: C25.1, R36.2, SN1.6 (DOWN), U9.4 (A2)
/NAV-LEFT-SW: U5.12 (GP3), U9.9 (Y4)
/NAV-LEFT-SW-RAW: C29.1, R38.2, SN1.3 (LEFT), U9.10 (A4)
/NAV-PUSH-SW: U5.11 (GP2), U9.7 (Y3)
/NAV-PUSH-SW-RAW: C27.1, R37.2, SN1.2 (PUSH), U9.6 (A3)
/NAV-RIGHT-SW: U5.13 (GP4), U9.11 (Y5)
/NAV-RIGHT-SW-RAW: C30.1, R39.2, SN1.4 (RIGHT), U9.12 (A5)
/NAV-UP-SW: U5.9 (GP0), U9.3 (Y1)
/NAV-UP-SW-RAW: C22.1, R32.2, SN1.1 (UP), U9.2 (A1)
/TEST-PAUSE-SW: U4.10 (GP1), U12.6 (2Y)
/TEST-START-SW: U4.9 (GP0), U12.3 (1Y)
/TEST-STEP-SW: U4.12 (GP3), U12.11 (4Y)
/TEST-STOP-SW: U4.11 (GP2), U12.8 (3Y)
/VIN1: J1.A2 (CH0), J1.B2 (CH8), J2.36
/VIN2: J1.A4 (CH1), J1.B4 (CH9), J2.37
/VIN3: J1.A6 (CH2), J1.B6 (CH10), J2.38
/VIN4: J1.A8 (CH3), J1.B8 (CH11), J2.39
/VIN5: J1.A10 (CH4), J1.B10 (CH12), J2.40
/VIN6: J1.A12 (CH5), J1.B12 (CH13), J2.41
/VIN7: J1.A14 (CH6), J1.B14 (CH14), J2.42
/VIN8: J1.A16 (CH7), J1.B16 (CH15), J2.43
GND: C1.2, C2.1, C3.2, C4.2, C5.2, C6.2, C7.2, C8.2, C9.2, C10.2, C11.2, C12.2, C13.2, C14.2, C15.2, C16.2, C17.2, C18.2, C19.2, C20.2, C21.2, C22.2, C23.2, C24.2, C25.2, C26.2, C27.2, C28.2, C29.2, C30.2, C31.2, C32.2, C33.2, C34.2, C35.2, C36.2, C37.2, C38.2, C39.2, C40.2, C41.2, C42.2, EN1.C, EN1.MP, EN1.S2, H1.1, H2.1, H3.1, H4.1, H5.1, H6.1, H7.1, H8.1, H9.1, H10.1, H11.1, J1.A1 (GND), J1.A3 (GND), J1.A5 (GND), J1.A7 (GND), J1.A9 (GND), J1.A11 (GND), J1.A13 (GND), J1.A15 (GND), J1.A17 (GND), J1.A18 (GND), J1.B1 (GND), J1.B3 (GND), J1.B5 (GND), J1.B7 (GND), J1.B9 (GND), J1.B11 (GND), J1.B13 (GND), J1.B15 (GND), J1.B17 (GND), J1.B18 (GND), J2.32, J2.34, J2.35, J2.44, J2.45, R3.2, R4.2, R7.2, R8.2, R10.2, R12.2, R13.2, R15.2, R17.2, R22.2, R24.2, R25.2, R26.2, S1.2, SN1.5 (COM), SN1.SH, SW1.3 (SWB), SW1.4 (SWB), SW2.2 (SWB), SW2.4 (SWB), SW3.3 (SWB), SW3.4 (SWB), SW4.3 (SWB), SW4.4 (SWB), SW5.2, SW6.3 (SWB), SW6.4 (SWB), SW7.3 (SWB), SW7.4 (SWB), SW8.3 (SWB), SW8.4 (SWB), SW9.3 (SWB), SW9.4 (SWB), SW10.3 (SWB), SW10.4 (SWB), SW11.3 (SWB), SW11.4 (SWB), SW12.3 (SWB), SW12.4 (SWB), SW13.3 (SWB), SW13.4 (SWB), SW14.2, SW15.2, SW16.1 (SWA), SW16.2 (SWA), SW17.2, SW18.2, SW19.2, SW20.2, SW21.2, U1.4 (GND), U2.1 (GND), U3.1 (GND), U4.2 (A1), U4.3 (A0), U4.17 (GND), U4.21 (GND), U5.3 (A0), U5.17 (GND), U5.21 (GND), U6.2 (GND), U7.2 (GND), U8.2 (A1), U8.17 (GND), U8.21 (GND), U9.1 (~OE1), U9.8 (GND), U9.15 (~OE2), U10.1 (~OE1), U10.8 (GND), U10.15 (~OE2), U11.1 (~OE1), U11.8 (GND), U11.15 (~OE2), U12.1 (1~OE), U12.4 (2~OE), U12.7 (GND), U12.10 (3~OE), U12.13 (4~OE), U12.15 (GND)
unnamed: C2.2, EN1.A, R1.2, R5.2
unnamed: C3.1, EN1.B, R2.2, R6.1
unnamed: D1.1 (K), R3.1
unnamed: D2.1 (K), R4.1
unnamed: D3.1 (K), U2.19 (OUT14)
unnamed: D4.1 (K), R10.1
unnamed: D5.1 (K), U3.5 (OUT0)
unnamed: D6.1 (K), U3.11 (OUT6)
unnamed: D7.1 (K), U3.15 (OUT10)
unnamed: D8.1 (K), U2.20 (OUT15)
unnamed: D9.1 (K), U3.6 (OUT1)
unnamed: D10.1 (K), U3.12 (OUT7)
unnamed: D11.1 (K), U3.16 (OUT11)
unnamed: D12.1 (K), R12.1
unnamed: D13.1 (K), U3.7 (OUT2)
unnamed: D14.1 (K), U3.13 (OUT8)
unnamed: D15.1 (K), U3.17 (OUT12)
unnamed: D16.1 (K), U3.8 (OUT3)
unnamed: D17.1 (K), U3.14 (OUT9)
unnamed: D18.1 (K), U3.18 (OUT13)
unnamed: D19.1 (K), U2.18 (OUT13)
unnamed: D20.1 (K), R13.1
unnamed: D21.1 (K), U3.9 (OUT4)
unnamed: D22.1 (K), U3.19 (OUT14)
unnamed: D23.1 (K), U3.10 (OUT5)
unnamed: D24.1 (K), U3.20 (OUT15)
unnamed: D25.1 (K), R15.1
unnamed: D26.1 (K), R17.1
unnamed: D27.1 (K), R22.1
unnamed: D28.1 (K), R24.1
unnamed: D29.1 (K), R25.1
unnamed: D30.1 (K), R26.1
unnamed: SW1.5 (LED-K), U2.5 (OUT0)
unnamed: SW2.6 (LED-GK), U2.9 (OUT4)
unnamed: SW2.8 (LED-RK), U2.10 (OUT5)
unnamed: SW3.5 (LED-K), U2.14 (OUT9)
unnamed: SW4.5 (LED-K), U2.15 (OUT10)
unnamed: SW6.5 (LED-K), U2.6 (OUT1)
unnamed: SW7.5 (LED-K), U2.11 (OUT6)
unnamed: SW8.5 (LED-K), U2.16 (OUT11)
unnamed: SW9.5 (LED-K), U2.12 (OUT7)
unnamed: SW10.5 (LED-K), U2.17 (OUT12)
unnamed: SW11.5 (LED-K), U2.7 (OUT2)
unnamed: SW12.5 (LED-K), U2.13 (OUT8)
unnamed: SW13.5 (LED-K), U2.8 (OUT3)
unnamed: R30.2, SW16.L1 (LED-B)
unnamed: R29.2, SW16.L4 (LED-G)
unnamed: R28.2, SW16.L2 (LED-R)
unnamed: R7.1, U2.23 (REXT)
unnamed: R8.1, U3.23 (REXT)
unnamed: C37.1, R44.2, SW3.1 (SWA), SW3.2 (SWA), U10.2 (A1)
unnamed: C38.1, R45.2, SW12.1 (SWA), SW12.2 (SWA), U10.4 (A2)
unnamed: C39.1, R46.2, SW9.1 (SWA), SW9.2 (SWA), U10.6 (A3)
unnamed: C40.1, R47.2, SW7.1 (SWA), SW7.2 (SWA), U10.10 (A4)
unnamed: C23.1, R34.2, SW8.1 (SWA), SW8.2 (SWA), U10.12 (A5)
unnamed: C24.1, R35.2, SW4.1 (SWA), SW4.2 (SWA), U10.14 (A6)
unnamed: C33.1, R40.2, SW6.1 (SWA), SW6.2 (SWA), U12.2 (1A)
unnamed: C34.1, R41.2, SW11.1 (SWA), SW11.2 (SWA), U12.5 (2A)
unnamed: C35.1, R42.2, SW1.1 (SWA), SW1.2 (SWA), U12.9 (3A)
unnamed: C36.1, R43.2, SW13.1 (SWA), SW13.2 (SWA), U12.12 (4A)
VCC-STBY: D4.2 (A), J2.23, TP3.1 (TP)
VCC-USB: D20.2 (A), J2.29, TP5.1 (TP)
VDD: D26.2 (A), J2.3, R5.1, R6.2, R9.1, TP7.1 (TP), U5.2 (A1), U8.3 (A0)
VDD-STBY: C1.1, C4.1, C5.1, C8.1, C11.1, C18.1, C19.1, C20.1, C28.1, C31.1, C32.1, C41.1, D3.2 (A), D5.2 (A), D6.2 (A), D7.2 (A), D8.2 (A), D9.2 (A), D10.2 (A), D11.2 (A), D13.2 (A), D14.2 (A), D15.2 (A), D16.2 (A), D17.2 (A), D18.2 (A), D19.2 (A), D21.2 (A), D22.2 (A), D23.2 (A), D24.2 (A), R11.1, R14.1, R16.1, R18.1, R19.1, R20.1, R21.1, R23.1, R27.1, R31.1, R32.1, R33.1, R34.1, R35.1, R36.1, R37.1, R38.1, R39.1, R40.1, R41.1, R42.1, R43.1, R44.1, R45.1, R46.1, R47.1, R48.1, SW1.6 (LED-A), SW2.5 (LED-GA), SW2.7 (LED-RA), SW3.6 (LED-A), SW4.6 (LED-A), SW6.6 (LED-A), SW7.6 (LED-A), SW8.6 (LED-A), SW9.6 (LED-A), SW10.6 (LED-A), SW11.6 (LED-A), SW12.6 (LED-A), SW13.6 (LED-A), SW16.L3 (LED-AN), U1.8 (VCC), U2.24 (VDD), U3.24 (VDD), U4.18 (VDD), U5.18 (VDD), U6.5 (VCC), U7.5 (VCC), U8.18 (VDD), U9.16 (VCC), U10.16 (VCC), U11.16 (VCC), U12.14 (VCC)
VDD-SYS: D12.2 (A), J2.1, J2.2, J2.22, TP4.1 (TP)

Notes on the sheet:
SOC RESET SWITCH
SOC POWER SWITCH
MENU CONTROLS
IOUT = 2.25mA
MOUNTING
SYSTEM SWITCHES
ETHERNET INDICATORS
ADDRESS = 0x42
USB PORT5
SOC USB INDICATORS
SWITCH IO-EXPANDERS
NAVIGATION CONTROLS
USB PORT2
STATE INDICATORS
ADDRESS = 0x44
TEST SEQUENCE CONTROLS
SYSTEM POWER SWITCH
USB PORT3
MOTHERBOARD CONNECTOR
POWER SWITCH INDICATORS
USB PORT4
ADDRESS = 0x40
SOC SLEEP SWITCH
USB PORT1
POWER INDICATORS

Board: 2 copper layers, 174 parts (103 on the bottom side), 143 nets, no tracks yet.

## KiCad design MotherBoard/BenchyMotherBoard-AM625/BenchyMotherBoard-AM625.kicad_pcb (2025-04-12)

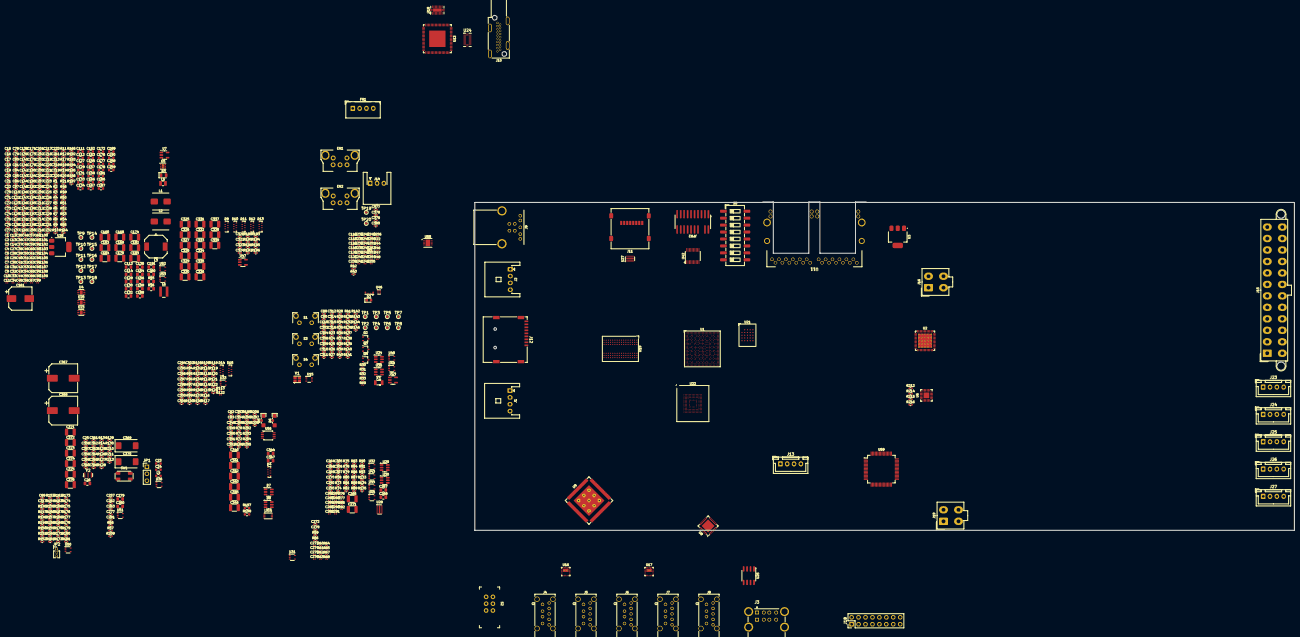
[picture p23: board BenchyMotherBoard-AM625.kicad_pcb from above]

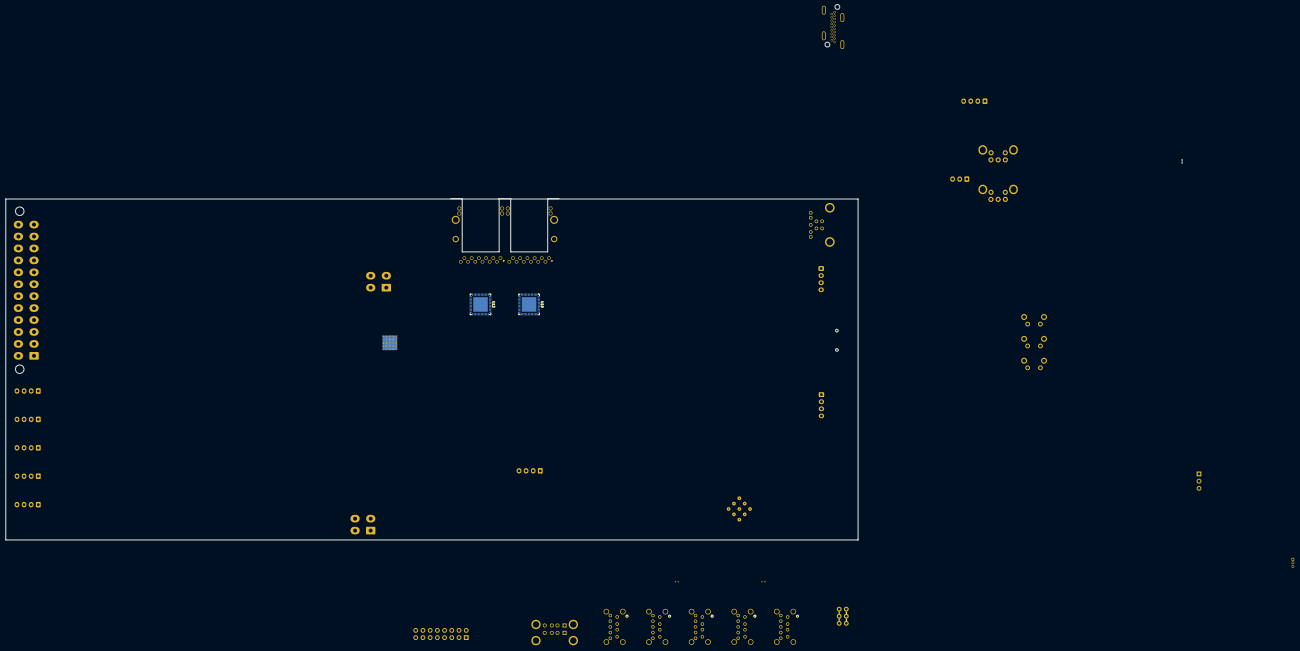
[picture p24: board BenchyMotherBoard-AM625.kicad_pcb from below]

Board: 6 copper layers, 300.0 x 120.0 mm, 730 parts (2 on the bottom side), 534 nets, no tracks yet.

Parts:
C1, C2, C3, C4, C5, C6, C7, C8, C9, C255, C256: 1u; CAP_0201
C10, C11, C12, C13, C14, C27, C28, C29, C30, C31, C32, C33, C34, C35, C36, C37, C38, C39, C40, C41, C42, C43, C44, C45, C46, C47, C48, C49, C50, C51, C52, C53, C54, C55, C56, C57, C58, C59, C60, C61, C62, C63, C64, C65, C66, C67, C68, C69, C91, C92, C93, C94, C95, C96, C97, C98, C99, C100, C101, C102, C103, C104, C105, C106, C107, C108, C109, C116, C117, C118, C119, C120, C121, C234, C235, C236, C237, C238, C239, C240, C241, C242, C243, C244, C245, C246, C247, C248, C249, C250, C251, C252, C253, C254, C273, C274, C275, C276, C282, C283, C284, C285, C286, C287, C288, C289, C290, C291: 100n; CAP_0201
C15, C17, C25, C261, C278, C292: 4u7; CAP_0402
C16: 10u; CAP_0402
C18, C19, C20, C21, C82, C83, C87, C88, C89, C90, C110, C115, C122, C123, C124, C125, C126, C136, C137, C138, C139, C140, C141, C142, C143, C144, C145, C146, C147, C148, C150, C151, C162, C165, C171, C173, C175, C179, C180, C184, C185, C192, C193, C194, C195, C196, C197, C198, C199, C200, C201, C202, C203, C204, C205, C206, C207, C208, C209, C210, C211, C212, C213, C214, C215, C216, C217, C218, C219, C220, C221, C222, C223, C224, C225, C226, C227, C228, C229, C230, C231, C232, C257, C262, C263, C264, C266, C269, C270, C272, C277, C281, C293, C294, C295, C296, C297, C298, C299, C300, C301, C302, C303, C304, C305, C306, C307, C308, C309, C310, C311, C312, C313, C314, C315, C316, C317, C319, C321, C322, C323, C324, C348, C349, C350, C351, C352, C354, C355, C357, C358, C359, C360, C361, C362, C363, C364, C365, C366, C377, C378, C379, C380: 100n; CAP_0402
C22, C70, C71, C72, C73: 6n8; CAP_0402
C23, C24, C111, C112, C127, C129, C131, C133, C134, C152, C153, C155, C157, C158, C167, C172, C176, C181, C186, C187, C189, C190, C258, C259: 1u; CAP_0603
C26, C113, C114, C128, C130, C132, C135, C154, C156, C188, C191, C260: 2u2; CAP_0805
C74, C75, C76, C77, C78, C79, C80, C81: 00; CAP_0402
C84, C85, C86, C320: 2n; CAP_0402
C149: 22p; CAP_0402
C159, C267, C268, C279, C280, C344, C347: 10u; CAP_0805
C160, C163, C164, C182, C183, C265, C271, C325, C326, C327, C328, C329, C330, C331, C332, C333, C334, C335, C336, C337, C338, C339, C340, C341, C342, C343, C345, C346, C375, C376: 47u; CAP_1210
C161: 220u; CAP_EL_8x10
C166, C177, C178: 10u; CAP_0603
C168, C169, C170, C174: 100u; CAP_1210
C233, C318: 10n; CAP_0402
C353: 1u; CAP_0402
C356: 2u2; CAP_0402
C367, C368: 220u; CAP_EL_10x10
C369, C370: 47u; CAP_TAN_2917
C371, C372: 22u; CAP_1210
C373, C374: 10u; CAP_1210
D1: EASV3015RGBA0
D2: CZ1-0603-BLUE; LED_0603_1608Metric
D3: APHCM2012SURCK-F01; LED_0805
D4, D9, D10, D11, D12, D13, D14, D15: DT1240A-08LP3810-7; U-DFN3810-9
D5, D6: SM1204SGC; LTST-S321TBKT
D7, D8: USBLC6-4SC6Y; SOT-23-6
EN1, EN2: PEC12R-2220F-S0024; PEC12R
FN1: CFM-5015CF-160-374-22; B4B-XH-A
J1, J2: S4B-XA-SK
J3: 5787745-2
J4, J5, J6, J7, J8: GSB4116341HR
J9: GSB3211311WEU
J10: HD01-19-RA-TH
J11: 472192001
J12: MEM2075-00-140-01-A; MEM2075-00-140-01-A_GCT
J13, J23, J24, J25, J26, J27: B4B-XH-AM; JST_XH_B4B-XH-A_1x04_P2.50mm_Vertical
J14: S3B-XH-A
J15: ATX-0039299243; 0039299243
J16: ATX-0039293046; 0039293046
J18: FRONT PANEL; PinHeader_2x08_P2.54mm_Vertical
J19: 0039293046
JP1: BOOT Jumper; PinHeader_1x03_P2.54mm_Vertical
JP2: Jumper_3_Bridged12; PinHeader_1x03_P1.27mm_Vertical
JPR2: JTAG-CTI; FTR-110-51-L-D-06
L1, L2: 15u; ETQP4MxxxKFN
L3: 8u2; 1217AS-H-8R2M=P3
L4: 100n; IND_0603
L5: 2u2; IND_0806
L6: 3u3; L_Wuerth_MAPI-4030
Q2, Q3, Q4: NX6008NBKWX; SOT-323_SC-70
R1: 750K; RES_0402
R2, R4, R6, R8: 240K; RES_0402
R3: 15K; RES_0402
R5: 300K; RES_0402
R7, R215: 120K; RES_0402
R9, R10, R11, R12, R21, R26, R29, R34, R35, R38, R54, R58, R59, R93, R94, R107, R108, R109, R110, R111, R112, R115, R116, R117, R118, R119, R120, R125, R126, R130, R131, R132, R133, R134, R135, R136, R137, R138, R139, R140, R141, R142, R143, R144, R146, R182, R183, R184, R185, R186, R187, R191, R192, R193, R194, R195, R196, R199, R203, R204, R205, R208, R209, R211, R213: 10K; RES_0402
R13: 3K6; RES_0402
R14, R165: 2K2; RES_0402
R15, R16: 3K3; RES_0805
R17, R18, R19, R20: 00; RES_0402
R22, R44: 240 0.1%; RES_0201
R23, R24, R25, R37, R98, R100, R102, R104, R145, R149, R150, R151, R152, R153, R154, R155, R166, R168, R170, R172, R174, R176, R178, R180, R200, R202: 1K; RES_0402
R27, R28, R36, R210: 100; RES_0402
R30, R31, R32, R33, R62, R64, R65, R68, R69, R76, R77, R85, R92, R113, R122: 22; RES_0201
R39, R41, R147, R148: 22; RES_0402
R40: 0; RES_0402
R42, R43: 39.2 0.1%; RES_0402
R45, R49, R51, R52, R66, R86, R128, R156, R157, R158, R159, R160, R161, R162, R163, R164, R167, R169, R171, R173, R175, R177, R179, R181, R189, R190: 100K; RES_0402
R46, R47, R48: 1K 0.1%; RES_0201
R50: 130K; RES_0402
R53: 110K; RES_0402
R55: 220K; RES_0402
R56, R114, R121: 4K7; RES_0402
R57: 4K3; RES_0402
R60, R61: 1K; RES_0201
R63, R67: 10K; RES_0201
R70: 43K2; RES_0402
R71, R73, R74, R75: 49K9; RES_0402
R72, R188: 12K 0.1%; RES_0402
R78, R79, R80, R81, R82, R83, R84, R87, R88, R89, R90, R91, R201: 47K; RES_0402
R95, R96, R105, R106: 220; RES_0402
R97, R99, R101, R103: 3K3; RES_0402
R123, R124: 4K99; RES_0402
R127: 8K2; RES_0402
R129: 33K; RES_0402
R197, R198: 500 0.1%; RES_0603
R206, R207: 200K; RES_0402
R212: 85K; RES_0402
R214: 122K; RES_0402
R216: 86K; RES_0402
S1, S3, S4: TL1105SF250Q; TL1105SF
S2: PBH2UEESNPNAGX
S5: 219-8MSTR
SW1: TL3365AF180QG
TP1: TP-LPM-EN; TestPoint_Pad_D1.0mm
TP2: TP-SOC-RST-OUT; TestPoint_Pad_D1.0mm
TP3: TP-REF-CLK0; TestPoint_Pad_D1.0mm
TP4: TP-MCU-RST-OUT; TestPoint_Pad_D1.0mm
TP5: TP-MCU-ERR; TestPoint_Pad_D1.0mm
TP6: TP-JTAG-RST; TestPoint_Pad_D1.0mm
TP7: TP-POR-OUT; TestPoint_Pad_D1.0mm
TP8: TP-GLOBAL-RST; TestPoint_Pad_D1.0mm
TP9: TP-HARD-RST; TestPoint_Pad_D1.0mm
TP10: TP-PSEQ-RST; TestPoint_Pad_D1.0mm
TP11: TP-GLOBAL-PG; TestPoint_Pad_D1.0mm
TP12: TP-MAIN-PG; TestPoint_Pad_D1.0mm
TP13: TP-PERP-PG; TestPoint_Pad_D1.0mm
TP14: TP-SOC-PWR-EN; TestPoint_Pad_D1.0mm
TP15: TP-PSEQ-EN1; TestPoint_Pad_D1.0mm
TP16: TP-PSEQ-EN2; TestPoint_Pad_D1.0mm
TP17: TP-PSEQ-EN3; TestPoint_Pad_D1.0mm
TP18: TP-PSEQ-EN4; TestPoint_Pad_D1.0mm
TP19: TP-MI2C-SCL; TestPoint_Pad_D1.0mm
TP20: TP-MI2C-SDA; TestPoint_Pad_D1.0mm
U1: AM6254ATCGGAALW; ALW0425A-BGA-425-13x13mm
U2: TPS65400RGZT; VQFN-48-1EP_7x7mm_P0.5mm_EP5.15x5.15mm_ThermalVias
U3: LM317-JCET; SOT-223
U4: AP3401DNTR-G1; DFN-6-1EP_2x2mm_P0.65mm_EP1x1.6mm
U5: TLV75518PDRVR; WSON-6-1EP_2x2mm_P0.65mm_EP1x1.6mm_ThermalVias
U6: MAX16043TG+T; TQFN-24-1EP_4x4mm_P0.5mm_EP2.1x2.1mm
U7: TPS7A0225PDBVR; SOT-23-5
U8: USB2412-DZK-TR; QFN-28-1EP_5x5mm_P0.5mm_EP3.35x3.35mm
U9: USB7206C/KDX; VQFN-100_EP_12x12_Pitch0.4mm
U10, U12: KSZ9021RN; QFN-48-1EP_7x7mm_P0.5mm_EP5.15x5.15mm
U11: RJMG212S21130ER
U13: SII9022ACNU; QFN-72-1EP_10x10mm_P0.5mm_EP6x6mm
U14: 74LVC1G17GV,125; SOT-23-5
U15: LMK1C1104DQFR; WSON-8_2x2mm_P0.5mm
U16, U17: UCS2114T-1-V/LX; UCS2114T-1-V_LXVAO-Custom
U18: 74LVC541ABQ,115; DHVQFN-20
U19: MT40A1G16TB-062E:F; DDR_FBGA-96_9x13mm_P0.8mm
U20, U23: TLV75901PDRVR; DFN-6-1EP_2x2mm_P0.65mm_EP1x1.6mm
U21: S28HS512TGABHI010; BGA-24_5x5_6.0x8.0mm
U22: EMMC256-TY29-5B101; LFBGA-153_11.5x13mm_Layout14x14_P0.5mm
U24: TPD12S016RKTR; UQFN-24_4x2mm_P0.5mm
U25: AP2156SG-13; SOIC-8_3.9x4.9mm_P1.27mm
U26: AZ1117IH-5.0TRG1; SOT-223
U27, U28: IP4252CZ16-8-TTL; QFN16_SOT1168-1_NEX-M
U29, U30: SIP32510DT-T1-GE3; TSOT-23-6
U31, U32, U33, U43, U44, U45, U48, U49, U50, U51, U52, U53: 74LVC1G08GW,125; SOT-353_SC-70-5
U34, U35: TMP100NA/3K; SOT-23-6
U36: SN74LVC1G17DCKR; SOT-353_SC-70-5
U42: SN74HCS541DGSR; VSSOP20_DGS_TEX
U46: 74LVC3G17GS,115; X2SON-8_1.4x1mm_P0.35mm
U47: AP2171WG-7; SOT-23-5
U55: W25Q16JVUXIQ TR; USON-8_2x3mm_P0.5mm
U56: 74HC2G08DP,125; TSSOP-8_3x3mm_P0.65mm
U58: NCV7357MW3R2G; DFN-8-1EP_3x3mm_P0.5mm_EP1.66x2.38mm
U59: STM32F412RGT6; LQFP-64_10x10mm_P0.5mm
X1: 32.768KHz; Crystal_SMD_3215-2Pin_3.2x1.5mm
Y1: 25MHz; Crystal_SMD_4Pin_2.5x2.0mm
Y2: 16MHz; Resonator_SMD_3Pin_3.0x1.1mm

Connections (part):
+12V: C159.1, C160.1, C161.1 (+), C259.1, C260.1, C367.1 (+), C368.1 (+), C369.1, C370.1, FN1.1 (V+), J1.1, J15.10 (12V1), J15.11 (12V1), J16.3 (12V), J16.4 (12V), J19.3, J23.1, J24.1, J25.1, J26.1, J27.1, R55.1, R129.1, U2.5 (PVIN1), U2.6 (PVIN2), U2.22 (VIN), U2.30 (PVIN3), U2.31 (PVIN4), U26.3 (IN)
-12V: J15.14 (-12), J19.4
/DDR MEMORY/DDR-A0: U1.J1 (DDR0-A0), U19.P3 (A0)
/DDR MEMORY/DDR-A1: U1.J2 (DDR0-A1), U19.P7 (A1)
/DDR MEMORY/DDR-A2: U1.K3 (DDR0-A2), U19.R3 (A2)
/DDR MEMORY/DDR-A3: U1.L5 (DDR0-A3), U19.N7 (A3)
/DDR MEMORY/DDR-A4: U1.K4 (DDR0-A4), U19.N3 (A4)
/DDR MEMORY/DDR-A5: U1.K1 (DDR0-A5), U19.P8 (A5)
/DDR MEMORY/DDR-A6: U1.R2 (DDR0-A6), U19.P2 (A6)
/DDR MEMORY/DDR-A7: U1.P2 (DDR0-A7), U19.R8 (A7)
/DDR MEMORY/DDR-A8: U1.P1 (DDR0-A8), U19.R2 (A8)
/DDR MEMORY/DDR-A9: U1.P4 (DDR0-A9), U19.R7 (A9)
/DDR MEMORY/DDR-A10: U1.R5 (DDR0-A10), U19.M3 (A10/AP)
/DDR MEMORY/DDR-A11: U1.P5 (DDR0-A11), U19.T2 (A11)
/DDR MEMORY/DDR-A12: U1.R6 (DDR0-A12), U19.M7 (A12/~BC)
/DDR MEMORY/DDR-A13: U1.R1 (DDR0-A13), U19.T8 (A13)
/DDR MEMORY/DDR-BA0: U1.M1 (DDR0-BA0), U19.N2 (BA0)
/DDR MEMORY/DDR-BA1: U1.N1 (DDR0-BA1), U19.N8 (BA1)
/DDR MEMORY/DDR-BG0: U1.T4 (DDR0-BG0), U19.M2 (BG0)
/DDR MEMORY/DDR-CKE: U1.H2 (DDR0-CKE0), U19.K2 (CKE)
/DDR MEMORY/DDR-CLK+: R42.1, U1.L1 (DDR0-CK0+), U19.K7 (CK+)
/DDR MEMORY/DDR-CLK-: R43.1, U1.L2 (DDR0-CK0-), U19.K8 (CK-)
/DDR MEMORY/DDR-DM0: U1.H5 (DDR0-DM0), U19.E7 (~LDM)
/DDR MEMORY/DDR-DM1: U1.W5 (DDR0-DM1), U19.E2 (~UDM)
/DDR MEMORY/DDR-DQ0: U1.F4 (DDR0-DQ0), U19.G2 (DQ0)
/DDR MEMORY/DDR-DQ1: U1.G5 (DDR0-DQ1), U19.F7 (DQ1)
/DDR MEMORY/DDR-DQ2: U1.F3 (DDR0-DQ2), U19.H3 (DQ2)
/DDR MEMORY/DDR-DQ3: U1.H6 (DDR0-DQ3), U19.H7 (DQ3)
/DDR MEMORY/DDR-DQ4: U1.E3 (DDR0-DQ4), U19.H2 (DQ4)
/DDR MEMORY/DDR-DQ5: U1.G2 (DDR0-DQ5), U19.H8 (DQ5)
/DDR MEMORY/DDR-DQ6: U1.F2 (DDR0-DQ6), U19.J3 (DQ6)
/DDR MEMORY/DDR-DQ7: U1.F1 (DDR0-DQ7), U19.J7 (DQ7)
/DDR MEMORY/DDR-DQ8: U1.U1 (DDR0-DQ8), U19.A3 (DQ8)
/DDR MEMORY/DDR-DQ9: U1.U3 (DDR0-DQ9), U19.B8 (DQ9)
/DDR MEMORY/DDR-DQ10: U1.U2 (DDR0-DQ10), U19.C3 (DQ10)
/DDR MEMORY/DDR-DQ11: U1.V5 (DDR0-DQ11), U19.C7 (DQ11)
/DDR MEMORY/DDR-DQ12: U1.W2 (DDR0-DQ12), U19.C2 (DQ12)
/DDR MEMORY/DDR-DQ13: U1.V6 (DDR0-DQ13), U19.C8 (DQ13)
/DDR MEMORY/DDR-DQ14: U1.Y1 (DDR0-DQ14), U19.D3 (DQ14)
/DDR MEMORY/DDR-DQ15: U1.W1 (DDR0-DQ15), U19.D7 (DQ15)
/DDR MEMORY/DDR-DQS0+: U1.E1 (DDR0-DQS0+), U19.G3 (LDQS+)
/DDR MEMORY/DDR-DQS0-: U1.E2 (DDR0-DQS0-), U19.F3 (LDQS-)
/DDR MEMORY/DDR-DQS1+: U1.V1 (DDR0-DQS1+), U19.B7 (UDQS+)
/DDR MEMORY/DDR-DQS1-: U1.V2 (DDR0-DQS1-), U19.A7 (UDQS-)
/DDR MEMORY/DDR-ODT: U1.H1 (DDR0-ODT0), U19.K3 (ODT)
/DDR MEMORY/DDR-PAR: U1.T1 (DDR0-PAR), U19.T3 (PAR)
/DDR MEMORY/DDR-~ACT: U1.N6 (DDR0-~ACT), U19.L3 (~ACT)
/DDR MEMORY/DDR-~ALERT: U1.R3 (DDR0-~ALERT), U19.P9 (~ALERT)
/DDR MEMORY/DDR-~CAS: U1.M4 (DDR0-~CAS), U19.M8 (~CAS/A15)
/DDR MEMORY/DDR-~CS: U1.L6 (DDR0-~CS0), U19.L7 (~CS)
/DDR MEMORY/DDR-~RAS: U1.M5 (DDR0-~RAS), U19.L8 (~RAS/A16)
/DDR MEMORY/DDR-~RESET: U1.G1 (DDR0-~RESET0), U19.P1 (~RESET)
/DDR MEMORY/DDR-~WE: U1.N3 (DDR0-~WE), U19.L2 (~WE/A14)
/DDR MEMORY/VREF-DDR: C116.2, C117.2, C118.1, C119.1, R46.2, R47.1, U19.M1 (VREFCA)
/DISPLAY/DSS-D0: U1.U22 (VOUT0-DATA0), U13.32 (D0)
/DISPLAY/DSS-D1: U1.V24 (VOUT0-DATA1), U13.31 (D1)
/DISPLAY/DSS-D2: U1.W25 (VOUT0-DATA2), U13.30 (D2)
/DISPLAY/DSS-D3: U1.W24 (VOUT0-DATA3), U13.29 (D3)
/DISPLAY/DSS-D4: U1.Y25 (VOUT0-DATA4), U13.28 (D4)
/DISPLAY/DSS-D5: U1.Y24 (VOUT0-DATA5), U13.27 (D5)
/DISPLAY/DSS-D6: U1.Y23 (VOUT0-DATA6), U13.25 (D6)
/DISPLAY/DSS-D7: U1.AA25 (VOUT0-DATA7), U13.24 (D7)
/DISPLAY/DSS-D8: U1.V21 (VOUT0-DATA8), U13.23 (D8)
/DISPLAY/DSS-D9: U1.W21 (VOUT0-DATA9), U13.20 (D9)
/DISPLAY/DSS-D10: U1.V20 (VOUT0-DATA10), U13.19 (D10)
/DISPLAY/DSS-D11: U1.AA23 (VOUT0-DATA11), U13.18 (D11)
/DISPLAY/DSS-D12: U1.AB25 (VOUT0-DATA12), U13.17 (D12)
/DISPLAY/DSS-D13: U1.AA24 (VOUT0-DATA13), U13.16 (D13)
/DISPLAY/DSS-D14: U1.Y22 (VOUT0-DATA14), U13.15 (D14)
/DISPLAY/DSS-D15: U1.AA21 (VOUT0-DATA15), U13.14 (D15)
/DISPLAY/DSS-DCLK: U1.AC24 (VOUT0-PCLK), U13.22 (IDCK)
/DISPLAY/DSS-DE: U1.Y20 (VOUT0-DE), U13.33 (DE)
/DISPLAY/DSS-HSYNC: U1.AB24 (VOUT0-HSYNC), U13.34 (HSYNC)
/DISPLAY/DSS-VSYNC: U1.AC25 (VOUT0-VSYNC), U13.35 (VSYNC)
/DISPLAY/HDMI-TX0+: J10.7 (D0+), U13.62 (TX0+), U24.17 (D0+)
/DISPLAY/HDMI-TX0-: J10.9 (D0-), U13.61 (TX0-), U24.16 (D0-)
/DISPLAY/HDMI-TX1+: J10.4 (D1+), U13.65 (TX1+), U24.20 (D1+)
/DISPLAY/HDMI-TX1-: J10.6 (D1-), U13.64 (TX1-), U24.19 (D1-)
/DISPLAY/HDMI-TX2+: J10.1 (D2+), U13.68 (TX2+), U24.22 (D2+)
/DISPLAY/HDMI-TX2-: J10.3 (D2-), U13.67 (TX2-), U24.21 (D2-)
/DISPLAY/HDMI-TXC+: J10.10 (CK+), U13.59 (TXC+), U24.15 (CLK+)
/DISPLAY/HDMI-TXC-: J10.12 (CK-), U13.58 (TXC-), U24.14 (CLK-)
/DISPLAY/RESET-HDMI: R209.1, U13.51 (~RESET), U51.4 (Y)
/EMMC/RESET-EMMC: R93.1, U22.K5 (~RESET), U32.4 (Y)
/EMMC/SD0-CLK: R73.1, R92.2, U22.M6 (CLK)
/EMMC/SD0-CMD: R75.2, U1.Y3 (MMC0-CMD), U22.M5 (CMD)
/EMMC/SD0-D0: R74.2, U1.AA2 (MMC0-DAT0), U22.A3 (D0)
/EMMC/SD0-D1: U1.AA1 (MMC0-DAT1), U22.A4 (D1)
/EMMC/SD0-D2: U1.AA3 (MMC0-DAT2), U22.A5 (D2)
/EMMC/SD0-D3: U1.Y4 (MMC0-DAT3), U22.B2 (D3)
/EMMC/SD0-D4: U1.AB2 (MMC0-DAT4), U22.B3 (D4)
/EMMC/SD0-D5: U1.AC1 (MMC0-DAT5), U22.B4 (D5)
/EMMC/SD0-D6: U1.AD2 (MMC0-DAT6), U22.B5 (D6)
/EMMC/SD0-D7: U1.AC2 (MMC0-DAT7), U22.B6 (D7)
/EMMC/SD1-CLK: R76.2, R83.1, U27.4 (4A)
/EMMC/SD1-CMD: R80.2, U1.A21 (MMC1-CMD), U27.3 (3A)
/EMMC/SD1-D0: R81.2, U1.A22 (MMC1-DAT0), U27.5 (5A)
/EMMC/SD1-D1: R84.2, U1.B21 (MMC1-DAT1), U27.6 (6A)
/EMMC/SD1-D2: R78.2, U1.C21 (MMC1-DAT2), U27.1 (1A)
/EMMC/SD1-D3: R79.2, U1.D22 (MMC1-DAT3), U27.2 (2A)
/EMMC/SD1-PWR: R134.2, U29.3 (EN), U43.4 (Y)
/EMMC/SD1-PWR-EN: U1.C17 (GPIO1-49), U43.2 (A)
/EMMC/SD2-CLK: R77.2, R89.1, U28.4 (4A)
/EMMC/SD2-CMD: R87.2, U1.C24 (MMC2-CMD), U28.3 (3A)
/EMMC/SD2-D0: R82.2, U1.B24 (MMC2-DAT0), U28.5 (5A)
/EMMC/SD2-D1: R91.2, U1.C25 (MMC2-DAT1), U28.6 (6A)
/EMMC/SD2-D2: R90.2, U1.E23 (MMC2-DAT2), U28.1 (1A)
/EMMC/SD2-D3: R88.2, U1.D24 (MMC2-DAT3), U28.2 (2A)
/EMMC/SD2-DET: R86.2, U1.A23 (MMC2-SDCD), U28.7 (7A)
/EMMC/SD2-PWR: R135.2, U1.B23 (GPIO0-72), U30.3 (EN), U44.4 (Y)
/EMMC/SDCARD-EXT-RESET: R133.2, U43.1 (B), U44.1 (B), U45.4 (Y)
/ETHERNET/ETH-PHY1-A+: D14.1 (K1), U11.B1 (MD1+), U12.2 (TXRX-A+)
/ETHERNET/ETH-PHY1-A-: D14.2 (K2), U11.B2 (MD1-), U12.3 (TXRX-A-)
/ETHERNET/ETH-PHY1-B+: D14.4 (K3), U11.B4 (MD2+), U12.5 (TXRX-B+)
/ETHERNET/ETH-PHY1-B-: D14.5 (K4), U11.B5 (MD2-), U12.6 (TXRX-B-)
/ETHERNET/ETH-PHY1-C+: D14.6 (K5), U11.B7 (MD3+), U12.7 (TXRX-C+)
/ETHERNET/ETH-PHY1-C-: D14.7 (K6), U11.B8 (MD3-), U12.8 (TXRX-C-)
/ETHERNET/ETH-PHY1-D+: D14.8 (K7), U11.B10 (MD4+), U12.10 (TXRX-D+)
/ETHERNET/ETH-PHY1-D-: D14.9 (K8), U11.B11 (MD4-), U12.11 (TXRX-D-)
/ETHERNET/ETH-PHY2-A+: D15.9 (K8), U10.2 (TXRX-A+), U11.A1 (MD1+)
/ETHERNET/ETH-PHY2-A-: D15.8 (K7), U10.3 (TXRX-A-), U11.A2 (MD1-)
/ETHERNET/ETH-PHY2-B+: D15.7 (K6), U10.5 (TXRX-B+), U11.A4 (MD2+)
/ETHERNET/ETH-PHY2-B-: D15.6 (K5), U10.6 (TXRX-B-), U11.A5 (MD2-)
/ETHERNET/ETH-PHY2-C+: D15.5 (K4), U10.7 (TXRX-C+), U11.A7 (MD3+)
/ETHERNET/ETH-PHY2-C-: D15.4 (K3), U10.8 (TXRX-C-), U11.A8 (MD3-)
/ETHERNET/ETH-PHY2-D+: D15.2 (K2), U10.10 (TXRX-D+), U11.A10 (MD4+)
/ETHERNET/ETH-PHY2-D-: D15.1 (K1), U10.11 (TXRX-D-), U11.A11 (MD4-)
/ETHERNET/MDIO-MDC: U1.AD24 (MDIO0-MDC), U10.36 (MD-SCL), U12.36 (MD-SCL)
/ETHERNET/MDIO-MDIO: U1.AB22 (MDIO0-MDIO), U10.37 (MD-SDA), U12.37 (MD-SDA)
/ETHERNET/RESET-ETH: R94.2, U10.42 (~RESET), U12.42 (~RESET), U33.4 (Y)
/ETHERNET/RGMII1-GTX-CLK: U1.AE19 (RGMII1-TXC), U12.24 (GTX-CLK)
/ETHERNET/RGMII1-RXCLK: R115.2, R122.1, U1.AD17 (RGMII1-RXC)
/ETHERNET/RGMII1-RXD0: R117.2, U1.AB17 (RGMII1-RD0), U12.32 (RXD0/_{MODE0})
/ETHERNET/RGMII1-RXD1: R118.2, U1.AC17 (RGMII1-RD1), U12.31 (RXD1/_{MODE1})
/ETHERNET/RGMII1-RXD2: R119.2, U1.AB16 (RGMII1-RD2), U12.28 (RXD2/_{MODE2})
/ETHERNET/RGMII1-RXD3: R120.2, U1.AA15 (RGMII1-RD3), U12.27 (RXD3/_{MODE3})
/ETHERNET/RGMII1-RXDV: R116.2, U1.AE17 (RGMII1-RX-CTL), U12.33 (RX-DV/_{CLK125-EN})
/ETHERNET/RGMII1-TXD0: U1.AE20 (RGMII1-TD0), U12.19 (TXD0)
/ETHERNET/RGMII1-TXD1: U1.AD20 (RGMII1-TD1), U12.20 (TXD1)
/ETHERNET/RGMII1-TXD2: U1.AE18 (RGMII1-TD2), U12.21 (TXD2)
/ETHERNET/RGMII1-TXD3: U1.AD18 (RGMII1-TD3), U12.22 (TXD3)
/ETHERNET/RGMII1-TXEN: U1.AD19 (RGMII1-TX-CTL), U12.25 (TX-EN)
/ETHERNET/RGMII2-GTX-CLK: U1.AE21 (RGMII2-TXC), U10.24 (GTX-CLK)
/ETHERNET/RGMII2-RXCLK: R112.2, R113.1, U1.AD23 (RGMII2-RXC)
/ETHERNET/RGMII2-RXD0: R110.2, U1.AE23 (RGMII2-RD0), U10.32 (RXD0/_{MODE0})
/ETHERNET/RGMII2-RXD1: R109.2, U1.AB20 (RGMII2-RD1), U10.31 (RXD1/_{MODE1})
/ETHERNET/RGMII2-RXD2: R108.2, U1.AC21 (RGMII2-RD2), U10.28 (RXD2/_{MODE2})
/ETHERNET/RGMII2-RXD3: R107.2, U1.AE22 (RGMII2-RD3), U10.27 (RXD3/_{MODE3})
/ETHERNET/RGMII2-RXDV: R111.2, U1.AD22 (RGMII2-RX-CTL), U10.33 (RX-DV/_{CLK125-EN})
/ETHERNET/RGMII2-TXD0: U1.Y18 (RGMII2-TD0), U10.19 (TXD0)
/ETHERNET/RGMII2-TXD1: U1.AA18 (RGMII2-TD1), U10.20 (TXD1)
/ETHERNET/RGMII2-TXD2: U1.AD21 (RGMII2-TD2), U10.21 (TXD2)
/ETHERNET/RGMII2-TXD3: U1.AC20 (RGMII2-TD3), U10.22 (TXD3)
/ETHERNET/RGMII2-TXEN: U1.AA19 (RGMII2-TX-CTL), U10.25 (TX-EN)
/POWER DISTRIBUTION/3V3-SENSE: R210.2, R213.1, U59.16 (ADC1-IN2)
/POWER DISTRIBUTION/5V-SENSE: R127.2, R211.1, U59.15 (ADC1-IN1)
/POWER DISTRIBUTION/12V-SENSE: R129.2, R130.1, U59.14 (ADC1-IN0)
/POWER DISTRIBUTION/BOOT: R125.1, U59.60 (BOOT0)
/POWER DISTRIBUTION/FP-DISP-CIPO: J18.5, U59.22 (SPI1-CIPO)
/POWER DISTRIBUTION/FP-DISP-COPI: J18.7, U59.23 (SPI1-COPI)
/POWER DISTRIBUTION/FP-DISP-CS: J18.9, U59.26 (PB0)
/POWER DISTRIBUTION/FP-DISP-DC: J18.11, U59.27 (PB1)
/POWER DISTRIBUTION/FP-DISP-RESET: J18.1, U59.20 (PA4)
/POWER DISTRIBUTION/FP-DISP-SCLK: J18.3, U59.21 (SPI1-SCK)
/POWER DISTRIBUTION/FP-IND-ERROR: J18.6, U59.39 (PC8)
/POWER DISTRIBUTION/FP-IND-STATUS: J18.4, U59.38 (PC7)
/POWER DISTRIBUTION/FP-SYS-PWR-SW: C365.1, J18.13, R128.2, U36.2 (A)
/POWER DISTRIBUTION/PWR-RESET: R126.2, SW1.1, U59.7 (RESET)
/POWER DISTRIBUTION/SMPS-EN: J15.16 (PS-ON), U59.11 (PC3)
/POWER DISTRIBUTION/SMPS-PG: J15.8 (PWR-OK), U59.10 (PC2)
/POWER DISTRIBUTION/SYS-PWR-SW: U36.4 (Y), U59.24 (PC4)
/POWER/MAIN-PGOOD: R12.2, TP12.1 (TP), U2.17 (PGOOD), U53.2 (A)
/POWER/PERIP-PGOOD: TP13.1 (TP), U4.2 (PG), U53.1 (B)
/POWER/PSEQ-EN1: R187.2, TP15.1 (TP), U2.48 (ENSW1/ENSEQ), U6.9 (EN2), U6.17 (OUT1)
/POWER/PSEQ-EN2: R186.2, TP16.1 (TP), U2.27 (ENSW3), U4.1 (EN), U6.10 (EN3), U6.16 (OUT2), U20.4 (EN), U23.4 (EN)
/POWER/PSEQ-EN3: R185.2, TP17.1 (TP), U2.34 (ENSW4), U6.11 (EN4), U6.15 (OUT3), U7.3 (EN)
/POWER/PSEQ-EN4: R184.2, TP18.1 (TP), U2.13 (ENSW2), U6.14 (OUT4)
/POWER/PSEQ-RESET: R164.1, TP10.1 (TP), U6.18 (~RESET), U52.1 (B)
/POWER/VDD-CORE-SEQ: R212.2, R214.1, U6.5 (IN4)
/POWER/VDD-DDR-SEQ: R215.2, R216.1, U6.4 (IN3)
/SOC CONTROL/CONN-JTAG-RESET: JPR2.15 (~RESET), R142.2, U42.4 (A3)
/SOC CONTROL/JTAG-EMU0: JPR2.13 (EMU0), U42.18 (Y1)
/SOC CONTROL/JTAG-EMU1: JPR2.14 (EMU1), U42.17 (Y2)
/SOC CONTROL/JTAG-RESET: R143.2, TP6.1 (TP), U42.16 (Y3), U48.2 (A)
/SOC CONTROL/JTAG-TCK: JPR2.11 (TCK), R139.2, U42.9 (A8)
/SOC CONTROL/JTAG-TDI: JPR2.3 (TDI), R136.2, U42.8 (A7)
/SOC CONTROL/JTAG-TDO: JPR2.7 (TDO), U42.13 (Y6)
/SOC CONTROL/JTAG-TMS: JPR2.1 (TMS), R140.2, U42.6 (A5)
/SOC CONTROL/JTAG-TRST: JPR2.2 (~TRST), R141.1, U42.5 (A4)
/SOC CONTROL/MCU-ERROR: R28.2, TP5.1 (TP), U1.D1 (MCU-~ERROR)
/SOC CONTROL/MCU-POR: R131.1, U1.D2 (~MCU-POR), U48.4 (Y)
/SOC CONTROL/MCU-RESET-OUT: R36.1, TP4.1 (TP), U1.B12 (MCU-~RESET-STAT)
/SOC CONTROL/MCU-RESET-SW: U1.E11 (MCU-~RESET), U46.7 (1Y)
/SOC CONTROL/POWER-SW: C314.1, R26.2, S2.2 (COM1), U14.2 (A)
/SOC CONTROL/SOC-EMU0: R138.2, U1.E12 (EMU0), U42.2 (A1)
/SOC CONTROL/SOC-EMU1: R137.2, U1.C11 (EMU1), U42.3 (A2)
/SOC CONTROL/SOC-MCU-CLK: R33.2, U1.B2 (MCU-OSC0-XI)
/SOC CONTROL/SOC-SLEEP-SW: U1.B3 (MCU-MCAN0-RX), U46.2 (3Y)
/SOC CONTROL/SOC-TCK: R39.2, U42.11 (Y8)
/SOC CONTROL/SOC-TDI: U1.A11 (TDI), U42.12 (Y7)
/SOC CONTROL/SOC-TDO: R41.2, U42.7 (A6)
/SOC CONTROL/SOC-TMS: U1.B11 (TMS), U42.14 (Y5)
/SOC CONTROL/SOC-TRST: U1.B10 (~TRST), U42.15 (Y4)
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

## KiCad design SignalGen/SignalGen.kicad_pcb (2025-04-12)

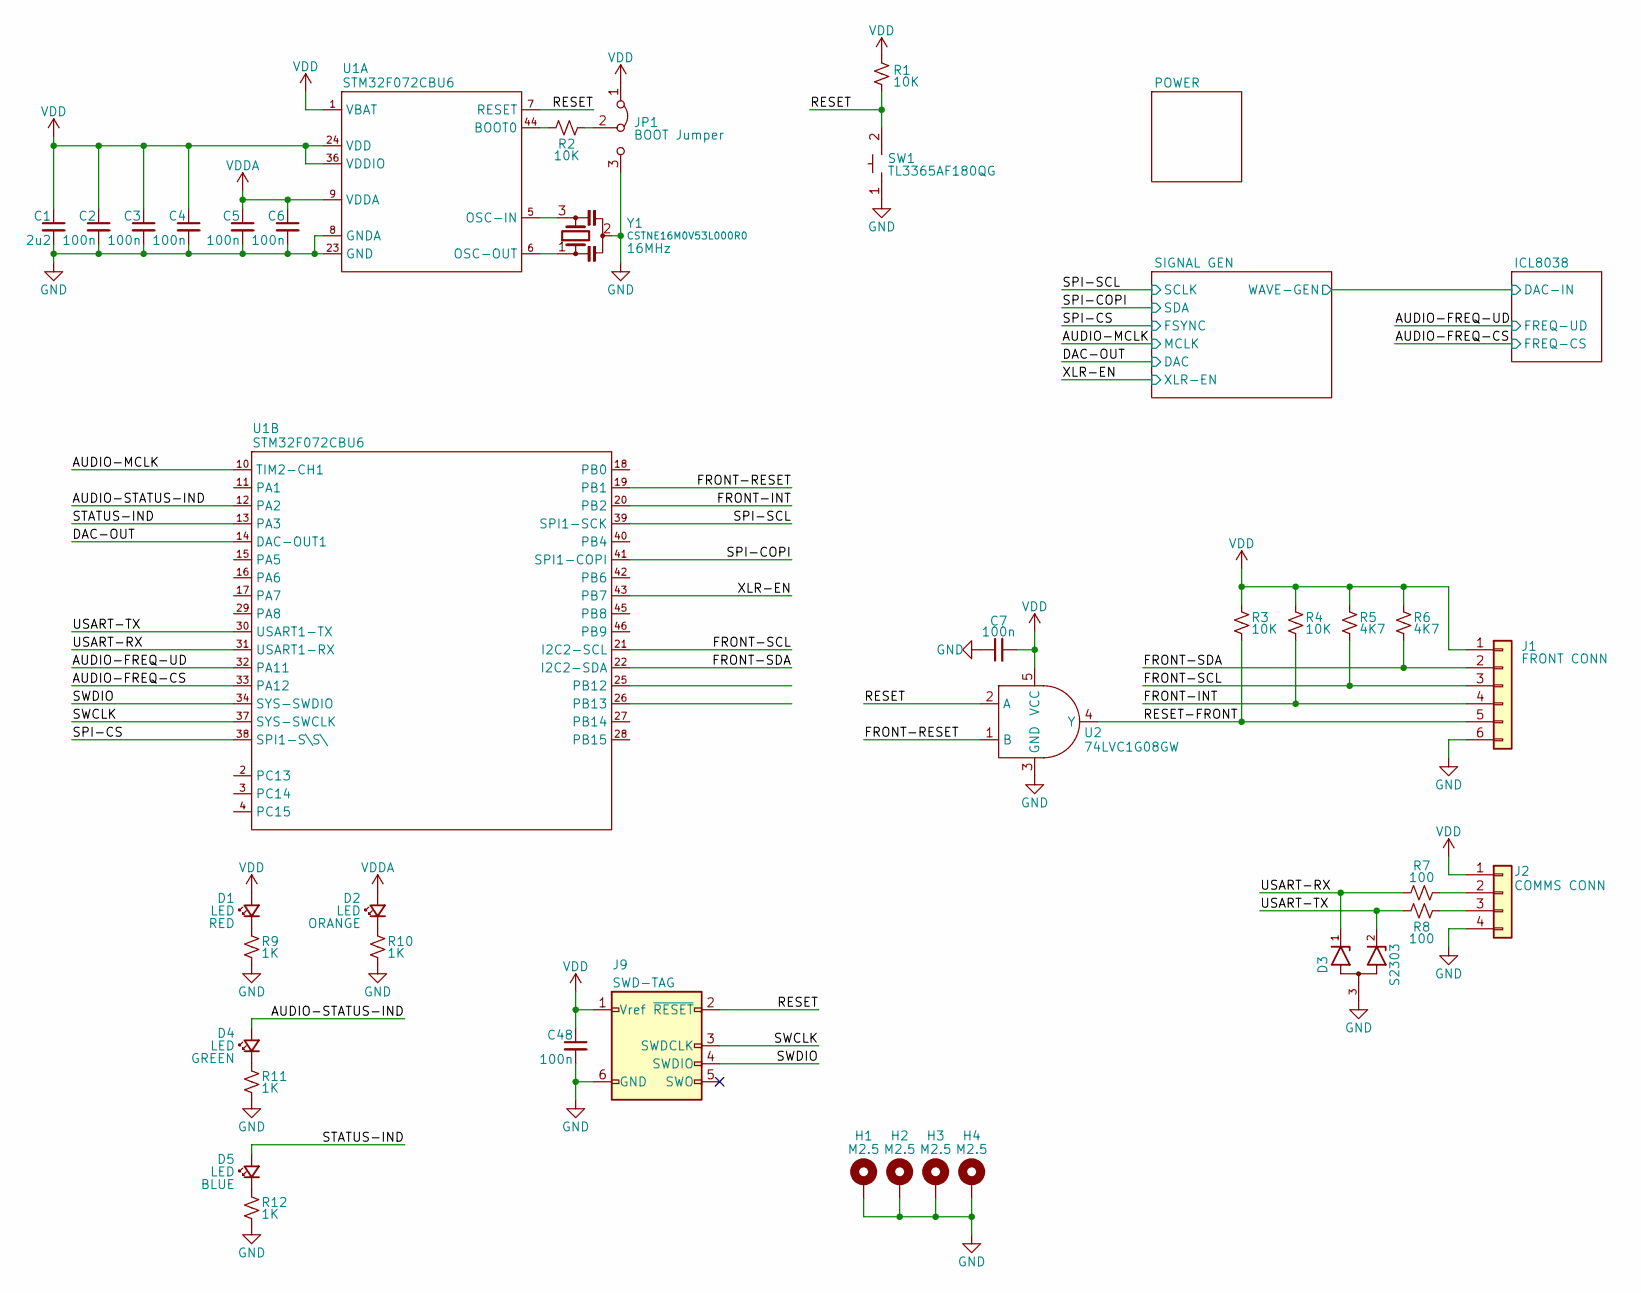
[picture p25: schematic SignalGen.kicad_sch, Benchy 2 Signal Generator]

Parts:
C1: 2u2; CAP_0402
C2, C3, C4, C5, C6, C7, C48: 100n; CAP_0402
D1, D2, D4, D5: LED; LED_0603_1608Metric
D3: S2303; SOT-23-3
H1, H2, H3, H4: M2.5; MountingHole_2.7mm_M2.5_DIN965_Pad
J1: FRONT CONN; JST_XH_B6B-XH-A_1x06_P2.50mm_Vertical
J2: COMMS CONN; JST_XH_B4B-XH-A_1x04_P2.50mm_Vertical
J9: SWD-TAG; Tag-Connect_TC2030-IDC-FP_2x03_P1.27mm_Vertical
JP1: BOOT Jumper; PinHeader_1x03_P2.54mm_Vertical
R1, R2, R3, R4: 10K; RES_0402
R5, R6: 4K7; RES_0402
R7, R8: 100; RES_0402
R9, R10, R11, R12: 1K; RES_0402
SW1: TL3365AF180QG
U1: STM32F072CBU6; QFN-48-1EP_7x7mm_P0.5mm_EP5.6x5.6mm
U2: 74LVC1G08GW; SOT-353_SC-70-5
Y1: CSTNE16M0V53L000R0; Resonator_SMD_3Pin_3.0x1.1mm

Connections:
/AUDIO-FREQ-CS: U1.33 (PA12); also elsewhere on the board
/AUDIO-FREQ-UD: U1.32 (PA11); also elsewhere on the board
/AUDIO-MCLK: U1.10 (TIM2-CH1); also elsewhere on the board
/AUDIO-STATUS-IND: D4.2 (A), U1.12 (PA2)
/DAC-OUT: U1.14 (DAC-OUT1); also elsewhere on the board
/FRONT-INT: J1.4, R4.2, U1.20 (PB2)
/FRONT-RESET: U1.19 (PB1), U2.1 (B)
/FRONT-SCL: J1.3, R5.2, U1.21 (I2C2-SCL)
/FRONT-SDA: J1.2, R6.2, U1.22 (I2C2-SDA)
/RESET: J9.2 (~RESET), R1.2, SW1.2, U1.7 (RESET), U2.2 (A)
/RESET-FRONT: J1.5, R3.2, U2.4 (Y)
/SPI-COPI: U1.41 (SPI1-COPI); also elsewhere on the board
/SPI-CS: U1.38 (SPI1-S\S\); also elsewhere on the board
/SPI-SCL: U1.39 (SPI1-SCK); also elsewhere on the board
/STATUS-IND: D5.2 (A), U1.13 (PA3)
/SWCLK: J9.3 (SWDCLK), U1.37 (SYS-SWCLK)
/SWDIO: J9.4 (SWDIO), U1.34 (SYS-SWDIO)
/USART-RX: D3.1 (A), R7.1, U1.31 (USART1-RX)
/USART-TX: D3.2 (B), R8.2, U1.30 (USART1-TX)
/XLR-EN: U1.43 (PB7)
GND: C1.2, C2.2, C3.2, C4.2, C5.2, C6.2, C7.1, C48.2, D3.3 (COM), H1.1, H2.1, H3.1, H4.1, J1.6, J2.4, J9.6 (GND), JP1.3 (B), R9.2, R10.2, R11.2, R12.2, SW1.1, U1.8 (GNDA), U1.23 (GND), U1.35 (GND), U1.47 (GND), U1.49 (GND), U2.3 (GND), Y1.2; also elsewhere on the board
unnamed: D1.1 (K), R9.1
unnamed: D2.1 (K), R10.1
unnamed: D4.1 (K), R11.1
unnamed: D5.1 (K), R12.1
unnamed: J2.2, R7.2
unnamed: J2.3, R8.1
unnamed: JP1.2 (C), R2.1
unnamed: R2.2, U1.44 (BOOT0)
unnamed: U1.5 (OSC-IN), Y1.3
unnamed: U1.6 (OSC-OUT), Y1.1
VDD: C1.1, C2.1, C3.1, C4.1, C7.2, C48.1, D1.2 (A), J1.1, J2.1, J9.1 (Vref), JP1.1 (A), R1.1, R3.1, R4.1, R5.1, R6.1, U1.1 (VBAT), U1.24 (VDD), U1.36 (VDDIO), U1.48 (VDD), U2.5 (VCC); also elsewhere on the board
VDDA: C5.1, C6.1, D2.2 (A), U1.9 (VDDA); also elsewhere on the board

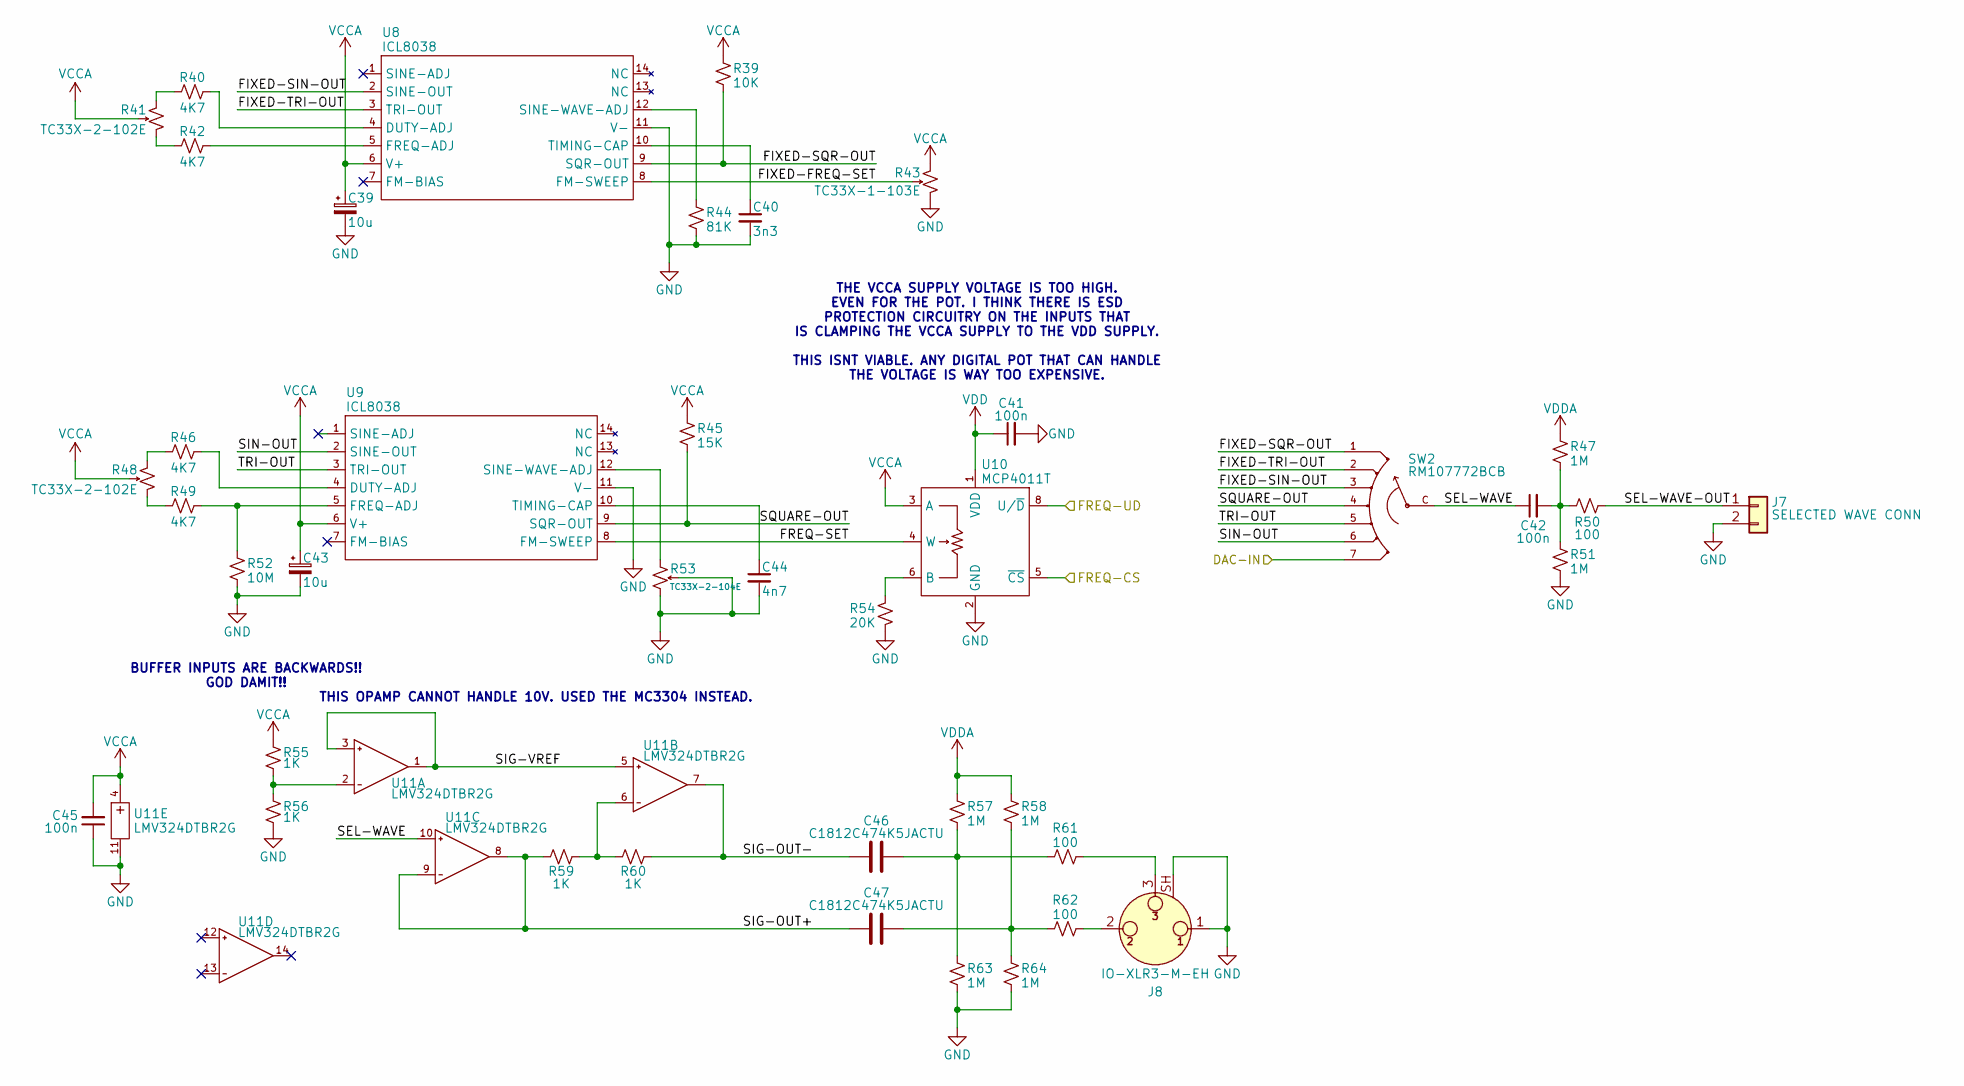
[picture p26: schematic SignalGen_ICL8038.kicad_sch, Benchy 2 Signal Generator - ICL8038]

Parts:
C39, C43: 10u; CAP_TAN_1206
C40: 3n3; CAP_0402
C41, C42, C45: 100n; CAP_0402
C44: 4n7; CAP_0402
C46, C47: C1812C474K5JACTU; CAP_1812
J7: SELECTED WAVE CONN; S2B-XH-A; Part Number 0311-0000-00001
J8: IO-XLR3-M-EH
R39: 10K; RES_0402
R40, R42, R46, R49: 4K7; RES_0402
R41, R48: TC33X-2-102E; Bourns_TC33X
R43: TC33X-1-103E; Bourns_TC33X
R44: 81K; RES_0402
R45: 15K; RES_0402
R47, R51, R57, R58, R63, R64: 1M; RES_0402
R50, R61, R62: 100; RES_0402
R52: 10M; RES_0402
R53: TC33X-2-104E; Bourns_TC33X
R54: 20K; RES_0402
R55, R56, R59, R60: 1K; RES_0402
SW2: RM107772BCB; RM104772BCB
U8, U9: ICL8038; DIP-14_W7.62mm
U10: MCP4011T; SOIC-8_3.9x4.9mm_P1.27mm
U11: LMV324DTBR2G; TSSOP-14_4.4x5mm_P0.65mm

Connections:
/AUDIO-FREQ-CS: U10.5 (~CS); also elsewhere on the board
/AUDIO-FREQ-UD: U10.8 (U/~D); also elsewhere on the board
/ICL8038/FIXED-FREQ-SET: R43.2, U8.8 (FM-SWEEP)
/ICL8038/FIXED-SIN-OUT: SW2.3, U8.2 (SINE-OUT)
/ICL8038/FIXED-SQR-OUT: R39.1, SW2.1, U8.9 (SQR-OUT)
/ICL8038/FIXED-TRI-OUT: SW2.2, U8.3 (TRI-OUT)
/ICL8038/FREQ-SET: U9.8 (FM-SWEEP), U10.4 (W)
/ICL8038/SEL-WAVE: C42.1, SW2.C, U11.10 (IN3+)
/ICL8038/SEL-WAVE-OUT: J7.1, R50.1
/ICL8038/SIG-OUT+: C47.1, R59.2, U11.8 (OUT3), U11.9 (IN3-)
/ICL8038/SIG-OUT-: C46.1, R60.1, U11.7 (OUT2)
/ICL8038/SIG-VREF: U11.1 (OUT1), U11.3 (IN1+), U11.5 (IN2+)
/ICL8038/SIN-OUT: SW2.6, U9.2 (SINE-OUT)
/ICL8038/SQUARE-OUT: R45.1, SW2.4, U9.9 (SQR-OUT)
/ICL8038/TRI-OUT: SW2.5, U9.3 (TRI-OUT)
/SIGNAL GEN/WAVE-GEN: SW2.7; also elsewhere on the board
GND: C39.2, C40.2, C41.2, C43.2, C44.2, C45.1, J7.2, J8.1, J8.SH, R43.3, R44.1, R51.1, R52.1, R53.2, R53.3, R54.1, R56.1, R63.1, R64.1, U8.11 (V-), U9.11 (V-), U10.2 (GND), U11.11 (V-); also elsewhere on the board
unnamed: C42.2, R47.1, R50.2, R51.2
unnamed: C46.2, R57.1, R61.1, R63.2
unnamed: C47.2, R58.1, R62.1, R64.2
unnamed: J8.2, R62.2
unnamed: J8.3, R61.2
unnamed: R40.1, R41.1
unnamed: R41.3, R42.1
unnamed: R46.1, R48.1
unnamed: R48.3, R49.1
unnamed: R40.2, U8.4 (DUTY-ADJ)
unnamed: R42.2, U8.5 (FREQ-ADJ)
unnamed: R44.2, U8.12 (SINE-WAVE-ADJ)
unnamed: C40.1, U8.10 (TIMING-CAP)
unnamed: R46.2, U9.4 (DUTY-ADJ)
unnamed: R49.2, R52.2, U9.5 (FREQ-ADJ)
unnamed: R53.1, U9.12 (SINE-WAVE-ADJ)
unnamed: C44.1, U9.10 (TIMING-CAP)
unnamed: R54.2, U10.6 (B)
unnamed: R55.1, R56.2, U11.2 (IN1-)
unnamed: R59.1, R60.2, U11.6 (IN2-)
VCCA: C39.1, C43.1, C45.2, R39.2, R41.2, R43.1, R45.2, R48.2, R55.2, U8.6 (V+), U9.6 (V+), U10.3 (A), U11.4 (V+); also elsewhere on the board
VDD: C41.1, U10.1 (VDD); also elsewhere on the board
VDDA: R47.2, R57.2, R58.2; also elsewhere on the board

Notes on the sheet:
BUFFER INPUTS ARE BACKWARDS!! GOD DAMIT!!
THIS OPAMP CANNOT HANDLE 10V. USED THE MC3304 INSTEAD.
THE VCCA SUPPLY VOLTAGE IS TOO HIGH. EVEN FOR THE POT. I THINK THERE IS ESD PROTECTION CIRCUITRY ON THE INPUTS THAT IS CLAMPING THE VCCA SUPPLY TO THE VDD SUPPLY. THIS ISNT VIABLE. ANY DIGITAL POT THAT CAN HANDLE THE VOLTAGE IS WAY TOO EXPENSIVE.

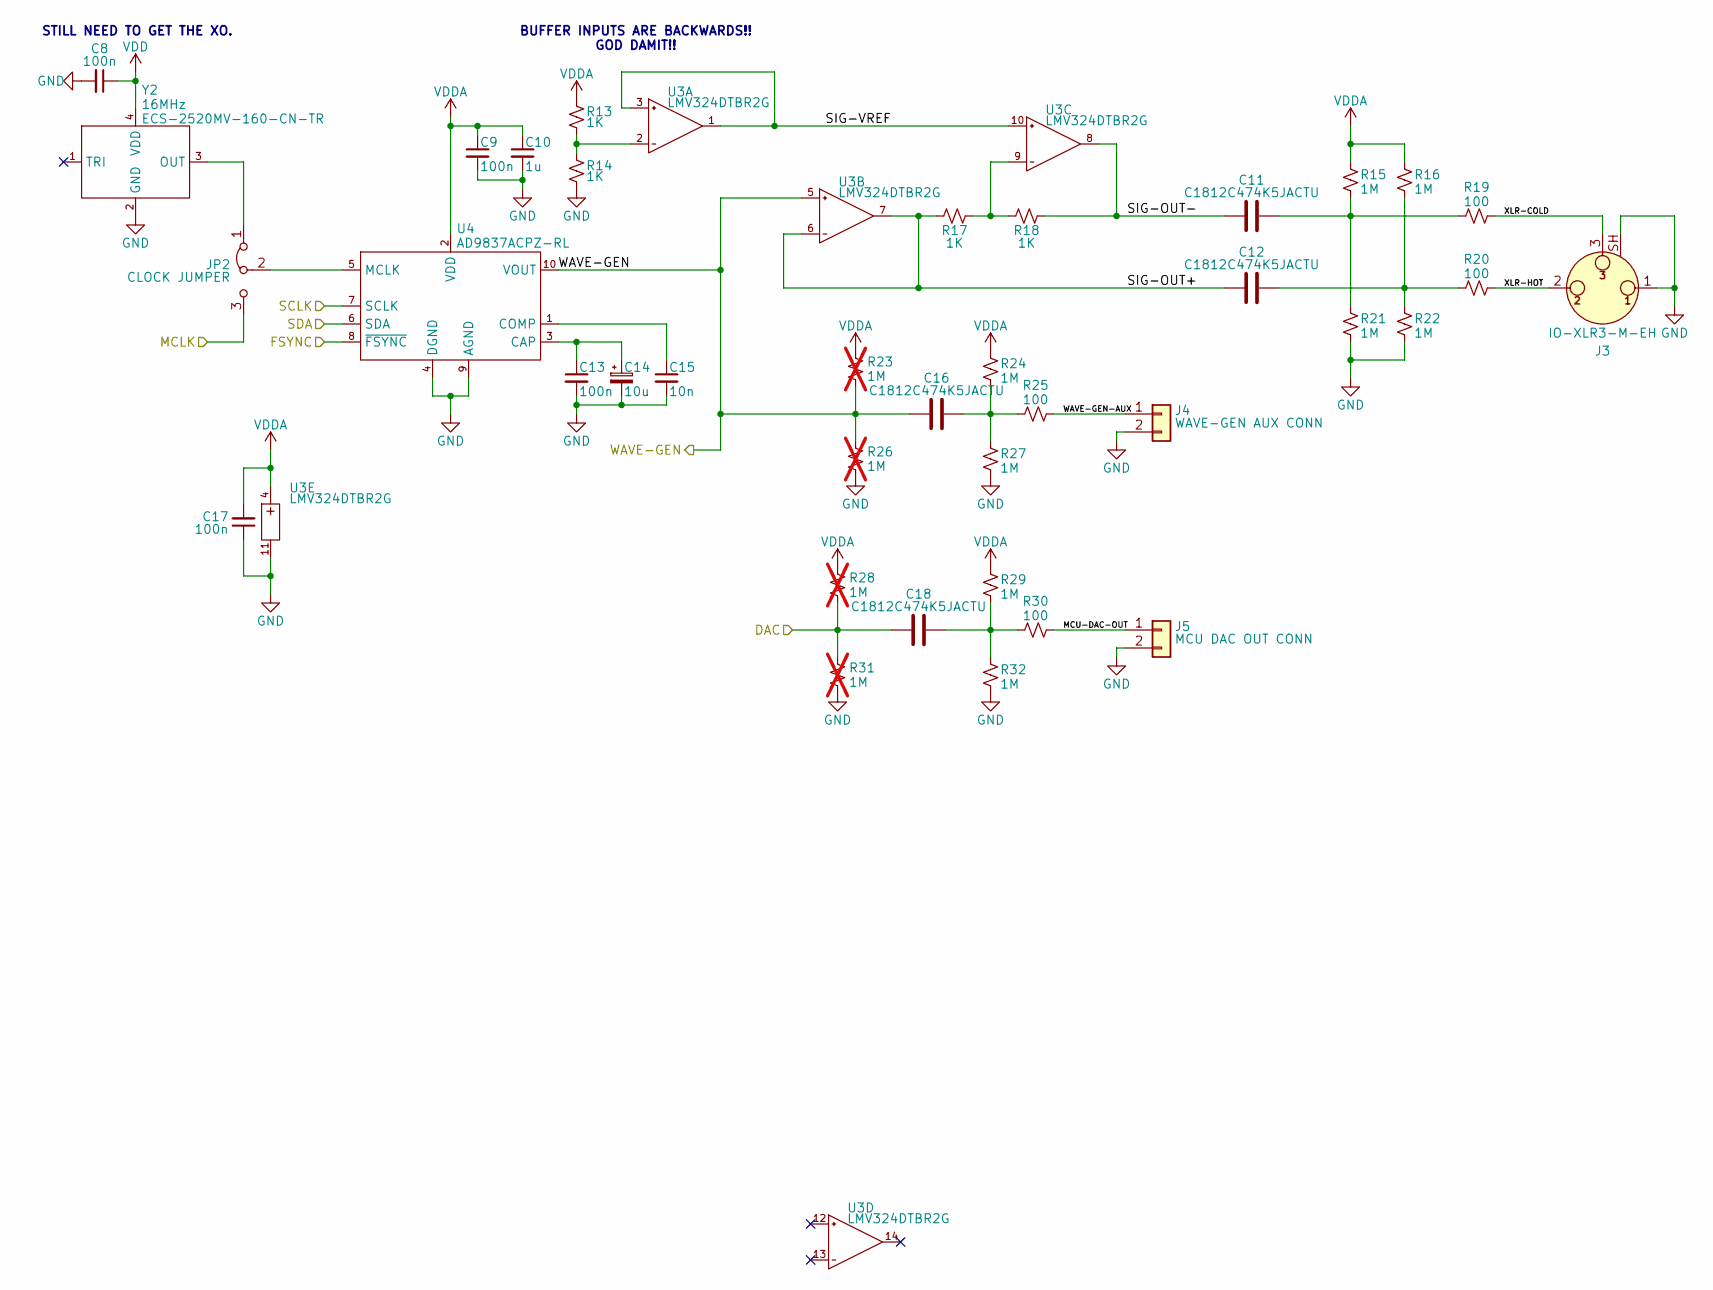
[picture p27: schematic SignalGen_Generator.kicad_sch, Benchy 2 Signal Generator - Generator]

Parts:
C8, C9, C13, C17: 100n; CAP_0402
C10: 1u; CAP_0402
C11, C12, C16, C18: C1812C474K5JACTU; CAP_1812
C14: 10u; CP_EIA-3216-10_Kemet-I
C15: 10n; CAP_0402
J3: IO-XLR3-M-EH
J4: WAVE-GEN AUX CONN; S2B-XH-A; Part Number 0311-0000-00001
J5: MCU DAC OUT CONN; S2B-XH-A; Part Number 0311-0000-00001
JP2: CLOCK JUMPER; SolderJumper-3_P1.3mm_Open_RoundedPad1.0x1.5mm_NumberLabels
R13, R14, R17, R18: 1K; RES_0402
R15, R16, R21, R22, R24, R27, R29, R32: 1M; RES_0402
R19, R20, R25, R30: 100; RES_0402
R23, R26, R28, R31: 1M; RES_0402; not fitted
U3: LMV324DTBR2G; TSSOP-14_4.4x5mm_P0.65mm
U4: AD9837ACPZ-RL; DFN-10-1EP_3x3mm_P0.5mm_EP1.65x2.38mm
Y2: ECS-2520MV-160-CN-TR; Crystal_SMD_4Pin_2.5x2.0mm

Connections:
/AUDIO-MCLK: JP2.3 (B); also elsewhere on the board
/DAC-OUT: C18.1, R28.1, R31.2; also elsewhere on the board
/SIGNAL GEN/MCU-DAC-OUT: J5.1, R30.2
/SIGNAL GEN/SIG-OUT+: C12.1, R17.2, U3.6 (IN2-), U3.7 (OUT2)
/SIGNAL GEN/SIG-OUT-: C11.1, R18.1, U3.8 (OUT3)
/SIGNAL GEN/SIG-VREF: U3.1 (OUT1), U3.3 (IN1+), U3.10 (IN3+)
/SIGNAL GEN/WAVE-GEN: C16.1, R23.1, R26.2, U3.5 (IN2+), U4.10 (VOUT); also elsewhere on the board
/SIGNAL GEN/WAVE-GEN-AUX: J4.1, R25.2
/SIGNAL GEN/XLR-COLD: J3.3, R19.2
/SIGNAL GEN/XLR-HOT: J3.2, R20.2
/SPI-COPI: U4.6 (SDA); also elsewhere on the board
/SPI-CS: U4.8 (~FSYNC); also elsewhere on the board
/SPI-SCL: U4.7 (SCLK); also elsewhere on the board
GND: C8.2, C9.2, C10.2, C13.2, C14.2, C15.2, C17.1, J3.1, J3.SH, J4.2, J5.2, R14.1, R21.1, R22.1, R26.1, R27.1, R31.1, R32.1, U3.11 (V-), U4.4 (DGND), U4.9 (AGND), U4.11 (DGND), Y2.2 (GND); also elsewhere on the board
unnamed: C11.2, R15.1, R19.1, R21.2
unnamed: C12.2, R16.1, R20.1, R22.2
unnamed: C16.2, R24.1, R25.1, R27.2
unnamed: C18.2, R29.1, R30.1, R32.2
unnamed: JP2.1 (A), Y2.3 (OUT)
unnamed: JP2.2 (C), U4.5 (MCLK)
unnamed: R13.1, R14.2, U3.2 (IN1-)
unnamed: R17.1, R18.2, U3.9 (IN3-)
unnamed: C13.1, C14.1, U4.3 (CAP)
unnamed: C15.1, U4.1 (COMP)
VDD: C8.1, Y2.4 (VDD); also elsewhere on the board
VDDA: C9.1, C10.1, C17.2, R13.2, R15.2, R16.2, R23.2, R24.2, R28.2, R29.2, U3.4 (V+), U4.2 (VDD); also elsewhere on the board

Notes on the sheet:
BUFFER INPUTS ARE BACKWARDS!! GOD DAMIT!!
STILL NEED TO GET THE XO.

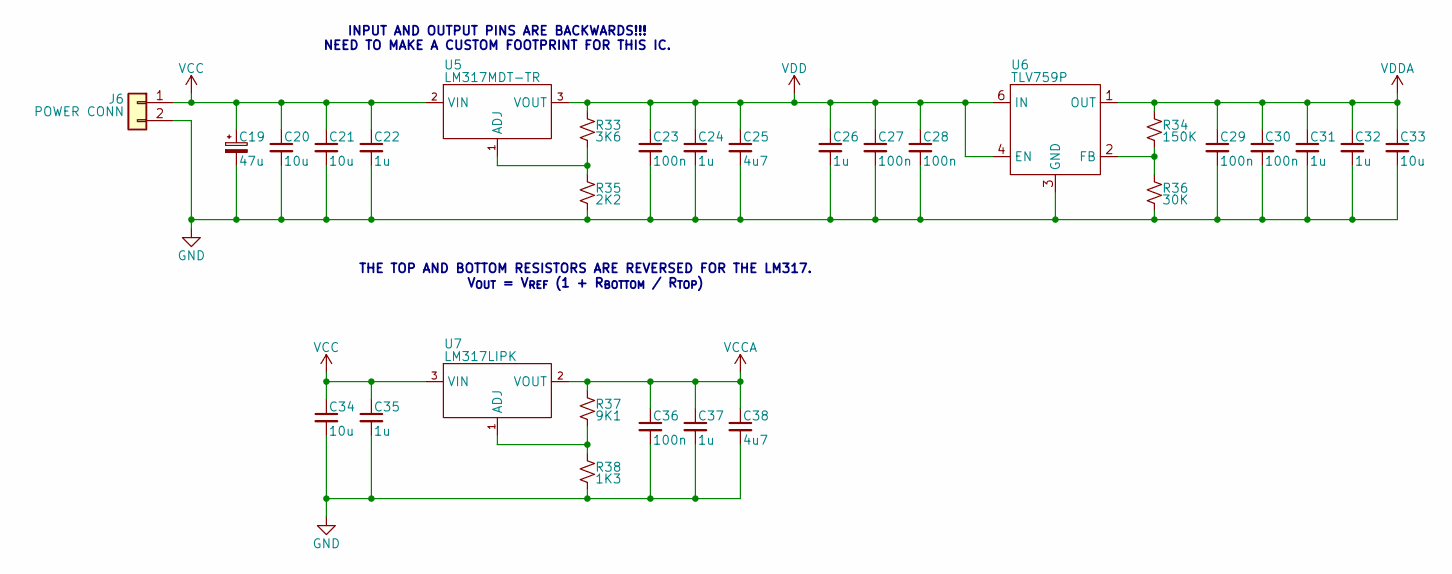
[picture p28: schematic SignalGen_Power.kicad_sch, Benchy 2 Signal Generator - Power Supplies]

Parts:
C19: 47u; CAP_EL_6.3x5.4
C20, C21, C34: 10u; CAP_1210
C22, C35: 1u; CAP_0805
C23, C27, C28, C29, C30, C36: 100n; CAP_0402
C24, C26, C31, C32, C37: 1u; CAP_0603
C25, C38: 4u7; CAP_0805
C33: 10u; CAP_0805
J6: POWER CONN; B2B-XH-A
R33: 3K6; RES_0402
R34: 150K; RES_0402
R35: 2K2; RES_0402
R36: 30K; RES_0402
R37: 9K1; RES_0402
R38: 1K3; RES_0402
U5: LM317MDT-TR; TO-252-2
U6: TLV759P; DFN-6-1EP_2x2mm_P0.65mm_EP1x1.6mm
U7: LM317LIPK; SOT-89-3

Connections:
GND: C19.2, C20.2, C21.2, C22.2, C23.2, C24.2, C25.2, C26.2, C27.2, C28.2, C29.2, C30.2, C31.2, C32.2, C33.2, C34.2, C35.2, C36.2, C37.2, C38.2, J6.2, R35.2, R36.2, R38.2, U6.3 (GND), U6.7 (GND); also elsewhere on the board
unnamed: R33.2, R35.1, U5.1 (ADJ)
unnamed: R34.2, R36.1, U6.2 (FB)
unnamed: R37.2, R38.1, U7.1 (ADJ)
VCC: C19.1, C20.1, C21.1, C22.1, C34.1, C35.1, J6.1, U5.2 (VIN), U7.3 (VIN)
VCCA: C36.1, C37.1, C38.1, R37.1, U7.2 (VOUT); also elsewhere on the board
VDD: C23.1, C24.1, C25.1, C26.1, C27.1, C28.1, R33.1, U5.3 (VOUT), U6.4 (EN), U6.6 (IN); also elsewhere on the board
VDDA: C29.1, C30.1, C31.1, C32.1, C33.1, R34.1, U6.1 (OUT); also elsewhere on the board

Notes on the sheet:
INPUT AND OUTPUT PINS ARE BACKWARDS!!! NEED TO MAKE A CUSTOM FOOTPRINT FOR THIS IC.
THE TOP AND BOTTOM RESISTORS ARE REVERSED FOR THE LM317. V_{OUT} = V_{REF} (1 + R_{BOTTOM} / R_{TOP})

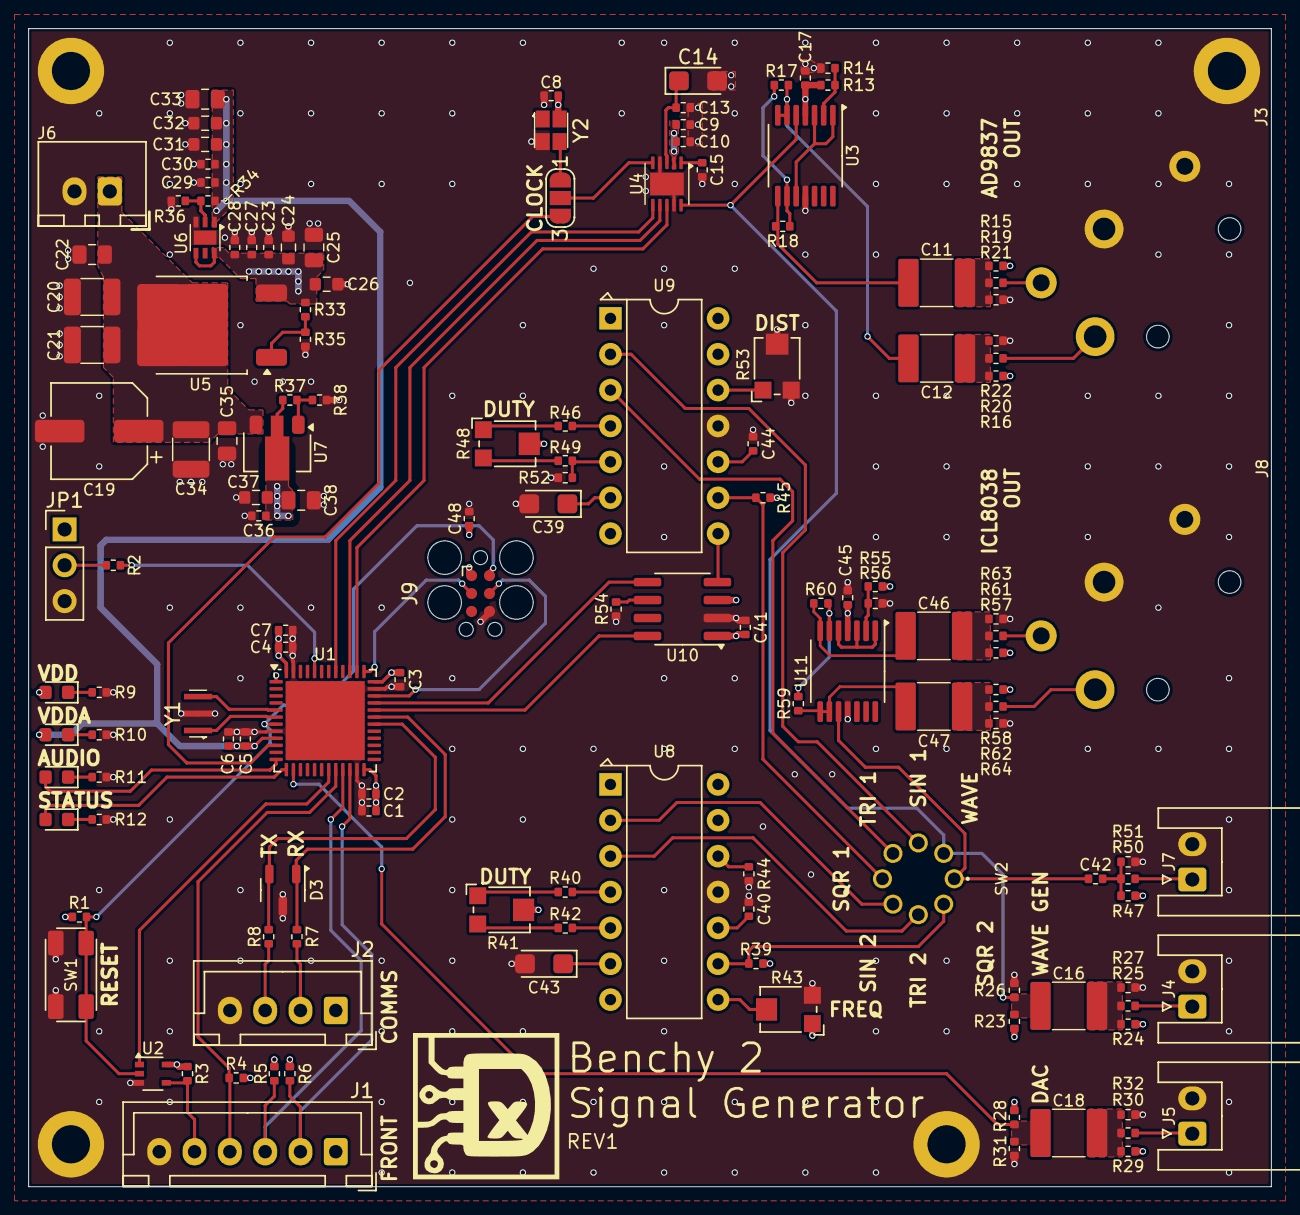
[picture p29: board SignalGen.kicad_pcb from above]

Board: 4 copper layers, 88.0 x 82.0 mm, 147 parts (0 on the bottom side), 88 nets.

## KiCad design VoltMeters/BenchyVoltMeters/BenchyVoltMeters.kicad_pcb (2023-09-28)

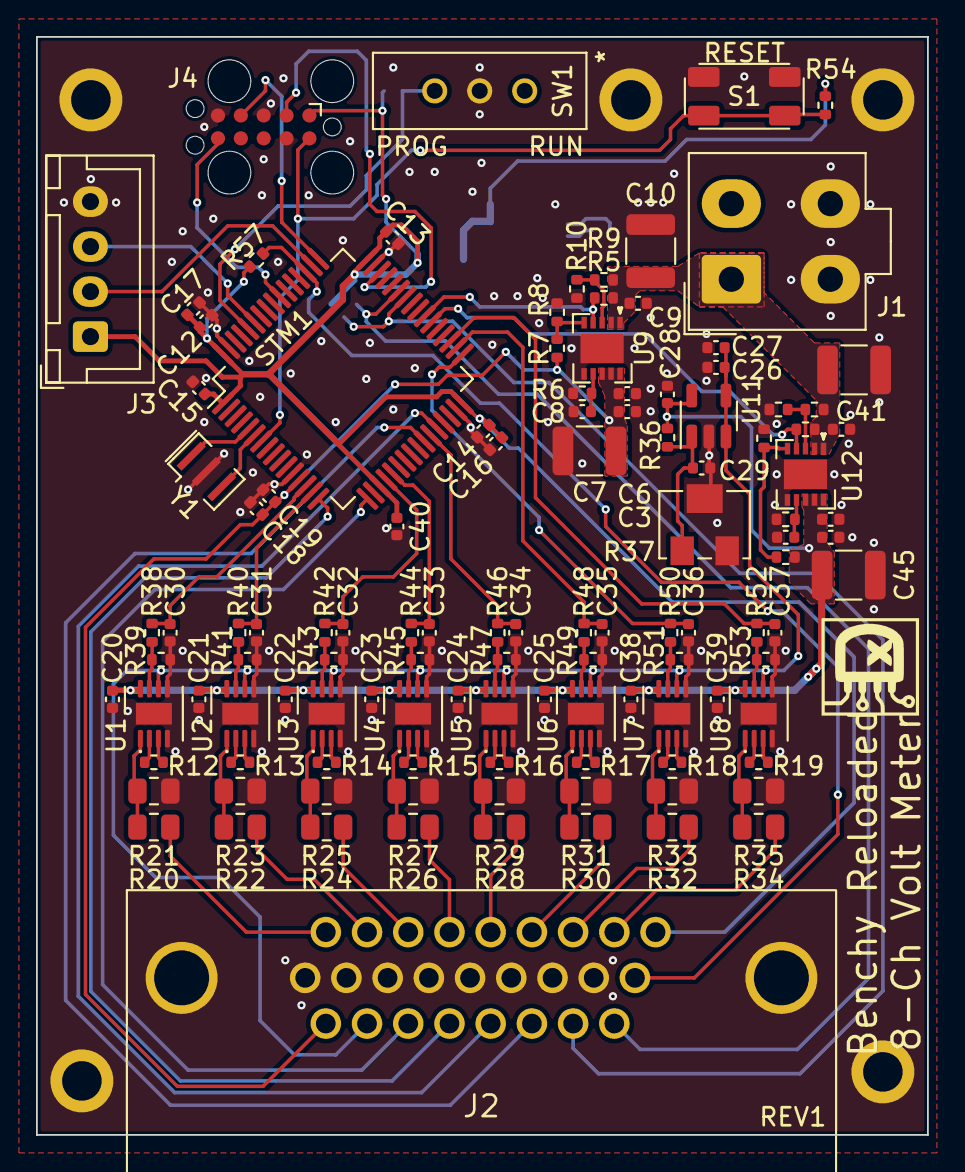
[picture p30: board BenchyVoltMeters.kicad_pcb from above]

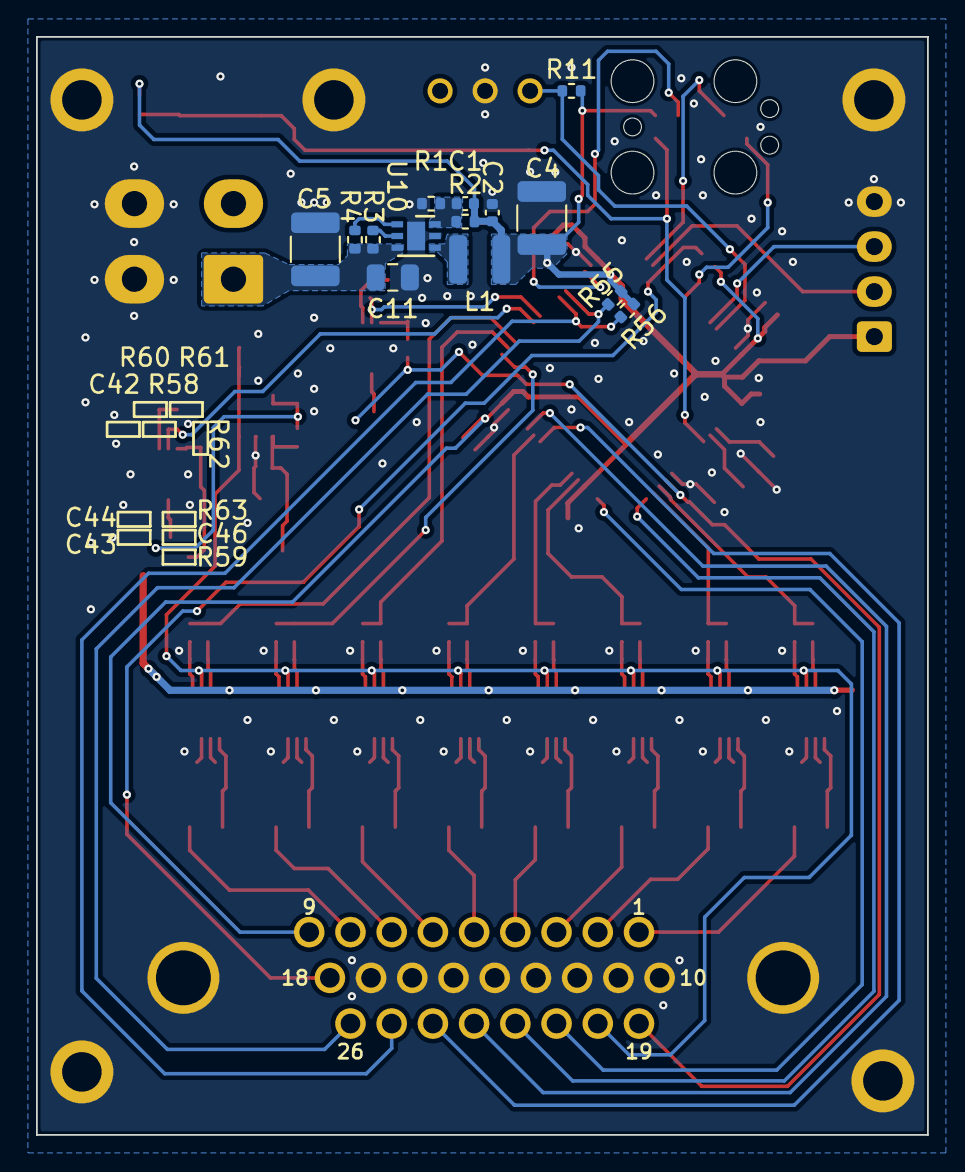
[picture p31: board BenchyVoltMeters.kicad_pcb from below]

Board: 2 copper layers, 49.5 x 61.0 mm, 135 parts (14 on the bottom side), 83 nets.

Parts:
C1: 22pF; C_0402_1005Metric
C2, C3, C6, C9, C20, C21, C22, C23, C24, C25, C26, C27, C28, C29, C38, C39, C42, C43, C44: 100nF; C_0402_1005Metric
C4, C5, C7, C10, C41, C45: 10uF; C_1210_3225Metric
C8, C46: 4.7uF; C_0402_1005Metric
C11: 1uF; C_0805_2012Metric
C12, C13, C14, C15, C16, C17, C18, C19, C40: 100uF; C_0402_1005Metric
C30, C31, C32, C33, C34, C35, C36, C37: 1nF; C_0402_1005Metric
H1, H2, H3, H4, H5: M2; MountingHole_2.2mm_M2_ISO7380_Pad
J1: POWER CONN; 4-Pin_Molex_Mini-Fit_Jr_Vertical
J2: DSUB-26; K66X-A26P-N
J3: MB-COMMS; JST_XH_B4B-XH-A_Vertical
J4: SWD-TAG; Tag-Connect_TC2050-IDC-FP_2x05_P1.27mm_Vertical
L1: 2.2uH; LQH3NPN
R1: 100K; R_0402_1005Metric
R2: 430K; R_0402_1005Metric
R3, R4, R5, R10, R11, R54, R57, R58, R61: 10K; R_0402_1005Metric
R6, R63: 22.1K; R_0402_1005Metric
R7, R59: 183.44K; R_0402_1005Metric
R8, R62: 12.5K; R_0402_1005Metric
R9, R60: 15K; R_0402_1005Metric
R12, R13, R14, R15, R16, R17, R18, R19: 10K 0.1%; R_0402_1005Metric
R20, R22, R24, R26, R28, R30, R32, R34: 10M 1%; R_0805_2012Metric
R21, R23, R25, R27, R29, R31, R33, R35: 256K 1%; R_0805_2012Metric
R36, R39, R41, R43, R45, R47, R49, R51, R53: 10K 1%; R_0402_1005Metric
R37: 10K; Bourns_3214W_Vertical
R38, R40, R42, R44, R46, R48, R50, R52: 100 1%; R_0402_1005Metric
R55, R56: 2.2K; R_0402_1005Metric
S1: RESET-SW; TL3365AF180QG
STM1: STM32F303RCT6TR; LQFP-64_10x10mm_P0.5mm
SW1: BOOT-SW; EG1218
U1, U2, U3, U4, U5, U6, U7, U8: INA826AIDRGR; Texas_S-PWSON-N8_EP1.2x2mm
U9, U12: TPS7A94; WSON-10-1EP_3x3mm
U10: AP3401; DFN-6-1EP_2x2mm_P0.65mm_EP1x1.6mm
U11: APX321; SOT-23-5
Y1: 8MHz; Resonator_SMD_Murata_CSTxExxV-3Pin_3.0x1.1mm

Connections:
/INT-CTRLS: J2.18, R57.2, STM1.51 (PC10)
/MC/COMP.A+: J2.21, STM1.17 (COMP2-IN+)
/MC/COMP.A-: J2.22, STM1.16 (COMP2-IN-)
/MC/COMP.B+: J2.24, STM1.26 (COMP4-IN+)
/MC/COMP.B-: J2.23, STM1.28 (COMP4-IN-)
/MC/I2C-CTRLS-SCL: J2.25, R56.1, STM1.42 (I2C2-SCL)
/MC/I2C-CTRLS-SDA: J2.26, R55.2, STM1.43 (I2C2-SDA)
/MC/I2C-MAIN-SCL: J3.2, STM1.50 (I2C1-SCL)
/MC/I2C-MAIN-SDA: J3.3, STM1.59 (I2C1-SDA)
/MC/SWCLK: J4.4 (SWDCLK), STM1.49 (SWCLK_JTCK)
/MC/SWDIO: J4.2 (SWDIO), STM1.46 (SWDIO_JTMS)
/MC/SWTRACE: J4.6 (SWO), STM1.55 (JTDO_TRACESWO)
/MC/VCCA-PG: R58.2, STM1.38 (PC7), U12.4 (PG)
/MC/VDDA-PG: R5.2, STM1.39 (PC8), U9.4 (PG)
/MC/VOLT1: C30.1, R38.2, STM1.14 (ADC1-IN1)
/MC/VOLT2: C31.1, R40.2, STM1.15 (ADC1-IN2)
/MC/VOLT3: C32.1, R42.2, STM1.20 (ADC2-IN1)
/MC/VOLT4: C33.1, R44.2, STM1.21 (ADC2-IN2)
/MC/VOLT5: C34.1, R46.2, STM1.27 (ADC3-IN1)
/MC/VOLT6: C35.1, R48.2, STM1.34 (ADC3-IN5)
/MC/VOLT7: C36.1, R50.2, STM1.33 (ADC4-IN3)
/MC/VOLT8: C37.1, R52.2, STM1.35 (ADC4-IN4)
/VOLT METERS/VOLT-IN1: J2.1, R20.2
/VOLT METERS/VOLT-IN2: J2.2, R22.2
/VOLT METERS/VOLT-IN3: J2.3, R24.2
/VOLT METERS/VOLT-IN4: J2.4, R26.2
/VOLT METERS/VOLT-IN5: J2.5, R28.2
/VOLT METERS/VOLT-IN6: J2.6, R30.2
/VOLT METERS/VOLT-IN7: J2.7, R32.2
/VOLT METERS/VOLT-IN8: J2.8, R34.2
BOOT0: R11.2, STM1.60 (BOOT0), SW1.3 (C)
GND: C2.2, C3.2, C4.2, C5.2, C6.2, C7.2, C8.1, C9.2, C10.2, C11.2, C12.2, C13.2, C14.2, C15.2, C16.2, C17.2, C18.2, C19.2, C20.2, C21.2, C22.2, C23.2, C24.2, C25.2, C26.2, C27.2, C28.2, C29.2, C30.2, C31.2, C32.2, C33.2, C34.2, C35.2, C36.2, C37.2, C38.2, C39.2, C40.2, C41.2, C42.2, C43.2, C44.2, C45.2, C46.1, H1.1, H2.1, H3.1, H4.1, H5.1, J1.3, J1.4, J2.10, J2.11, J2.12, J2.13, J2.14, J2.15, J2.16, J2.17, J2.27 (MNT), J3.4, J4.3 (GND), J4.5 (GND), J4.9 (GNDDetect), R1.2, R6.2, R8.2, R10.1, R21.1, R23.1, R25.1, R27.1, R29.1, R31.1, R33.1, R35.1, R37.2, R37.3, R39.2, R41.2, R43.2, R45.2, R47.2, R49.2, R51.2, R53.2, R61.1, R62.2, R63.2, S1.2, STM1.12 (GNDA), STM1.31 (GND), STM1.47 (GND), STM1.63 (GND), SW1.2 (B), U1.4 (+), U1.5 (V-), U1.9 (PAD), U2.4 (+), U2.5 (V-), U2.9 (PAD), U3.4 (+), U3.5 (V-), U3.9 (PAD), U4.4 (+), U4.5 (V-), U4.9 (PAD), U5.4 (+), U5.5 (V-), U5.9 (PAD), U6.4 (+), U6.5 (V-), U6.9 (PAD), U7.4 (+), U7.5 (V-), U7.9 (PAD), U8.4 (+), U8.5 (V-), U8.9 (PAD), U9.6 (GND), U9.11 (GND), U10.5 (GND), U10.7 (GND), U11.2 (V-), U12.6 (GND), U12.11 (GND), Y1.2
unnamed: R12.1, U1.3 (RG)
unnamed: R12.2, U1.2 (RG)
unnamed: R13.1, U2.3 (RG)
unnamed: R13.2, U2.2 (RG)
unnamed: R14.1, U3.3 (RG)
unnamed: R14.2, U3.2 (RG)
unnamed: R15.1, U4.3 (RG)
unnamed: R15.2, U4.2 (RG)
unnamed: R16.1, U5.3 (RG)
unnamed: R16.2, U5.2 (RG)
unnamed: R17.1, U6.3 (RG)
unnamed: R17.2, U6.2 (RG)
unnamed: R18.1, U7.3 (RG)
unnamed: R18.2, U7.2 (RG)
unnamed: R19.1, U8.3 (RG)
unnamed: R19.2, U8.2 (RG)
unnamed: R38.1, R39.1, U1.7
unnamed: R40.1, R41.1, U2.7
unnamed: R42.1, R43.1, U3.7
unnamed: R44.1, R45.1, U4.7
unnamed: R46.1, R47.1, U5.7
unnamed: R48.1, R49.1, U6.7
unnamed: R50.1, R51.1, U7.7
unnamed: R52.1, R53.1, U8.7
unnamed: STM1.5 (OSC-IN), Y1.1
unnamed: STM1.6 (OSC-OUT), Y1.3
unnamed: R20.1, R21.2, U1.1 (-)
unnamed: R22.1, R23.2, U2.1 (-)
unnamed: R24.1, R25.2, U3.1 (-)
unnamed: R26.1, R27.2, U4.1 (-)
unnamed: R28.1, R29.2, U5.1 (-)
unnamed: R30.1, R31.2, U6.1 (-)
unnamed: R32.1, R33.2, U7.1 (-)
unnamed: R34.1, R35.2, U8.1 (-)
unnamed: R9.2, R10.2, U9.3 (EN_UV)
unnamed: R7.2, R8.1, U9.5 (FB_PG)
unnamed: C8.2, R6.1, U9.7 (NR/SS)
unnamed: R4.2, U10.1 (EN)
unnamed: C1.2, R1.1, R2.2, U10.6 (FB)
unnamed: L1.1, U10.4 (LX)
unnamed: R3.2, U10.2 (PG)
unnamed: C29.1, R36.1, R37.1, U11.1 (IN+)
unnamed: R60.2, R61.2, U12.3 (EN_UV)
unnamed: R59.2, R62.1, U12.5 (FB_PG)
unnamed: C46.2, R63.1, U12.7 (NR/SS)
RESET: J4.10 (~RESET), R54.2, S1.1, STM1.7 (~RESET)
VCC: C5.1, C9.1, C10.1, C11.1, C41.1, C42.1, J1.1, R3.1, R4.1, R5.1, R9.1, R58.1, R60.1, U9.1 (IN), U9.2 (IN), U10.3 (VIN), U12.1 (IN), U12.2 (IN)
VCCA: C20.1, C21.1, C22.1, C23.1, C24.1, C25.1, C28.1, C38.1, C39.1, C43.1, C44.1, C45.1, R36.2, R59.1, U1.8 (V+), U2.8 (V+), U3.8 (V+), U4.8 (V+), U5.8 (V+), U6.8 (V+), U7.8 (V+), U8.8 (V+), U11.5 (V+), U12.8 (SNS), U12.9 (OUT), U12.10 (OUT)
VDD: C1.1, C2.1, C4.1, C12.1, C13.1, C14.1, C15.1, C16.1, C17.1, C40.1, J2.9, J3.1, J4.1 (Vref), L1.2, R2.1, R11.1, R54.1, R55.1, R56.2, R57.1, STM1.1 (VBAT), STM1.19 (VDD), STM1.32 (VDD), STM1.48 (VDD), STM1.64 (VDD)
VDDA: C3.1, C6.1, C7.1, C18.1, C19.1, J2.19, R7.1, STM1.13 (VDDA), U9.8 (SNS), U9.9 (OUT), U9.10 (OUT)
VREF: C26.1, C27.1, J2.20, U1.6 (REF), U2.6 (REF), U3.6 (REF), U4.6 (REF), U5.6 (REF), U6.6 (REF), U7.6 (REF), U8.6 (REF), U11.3 (IN-), U11.4 (OUT)

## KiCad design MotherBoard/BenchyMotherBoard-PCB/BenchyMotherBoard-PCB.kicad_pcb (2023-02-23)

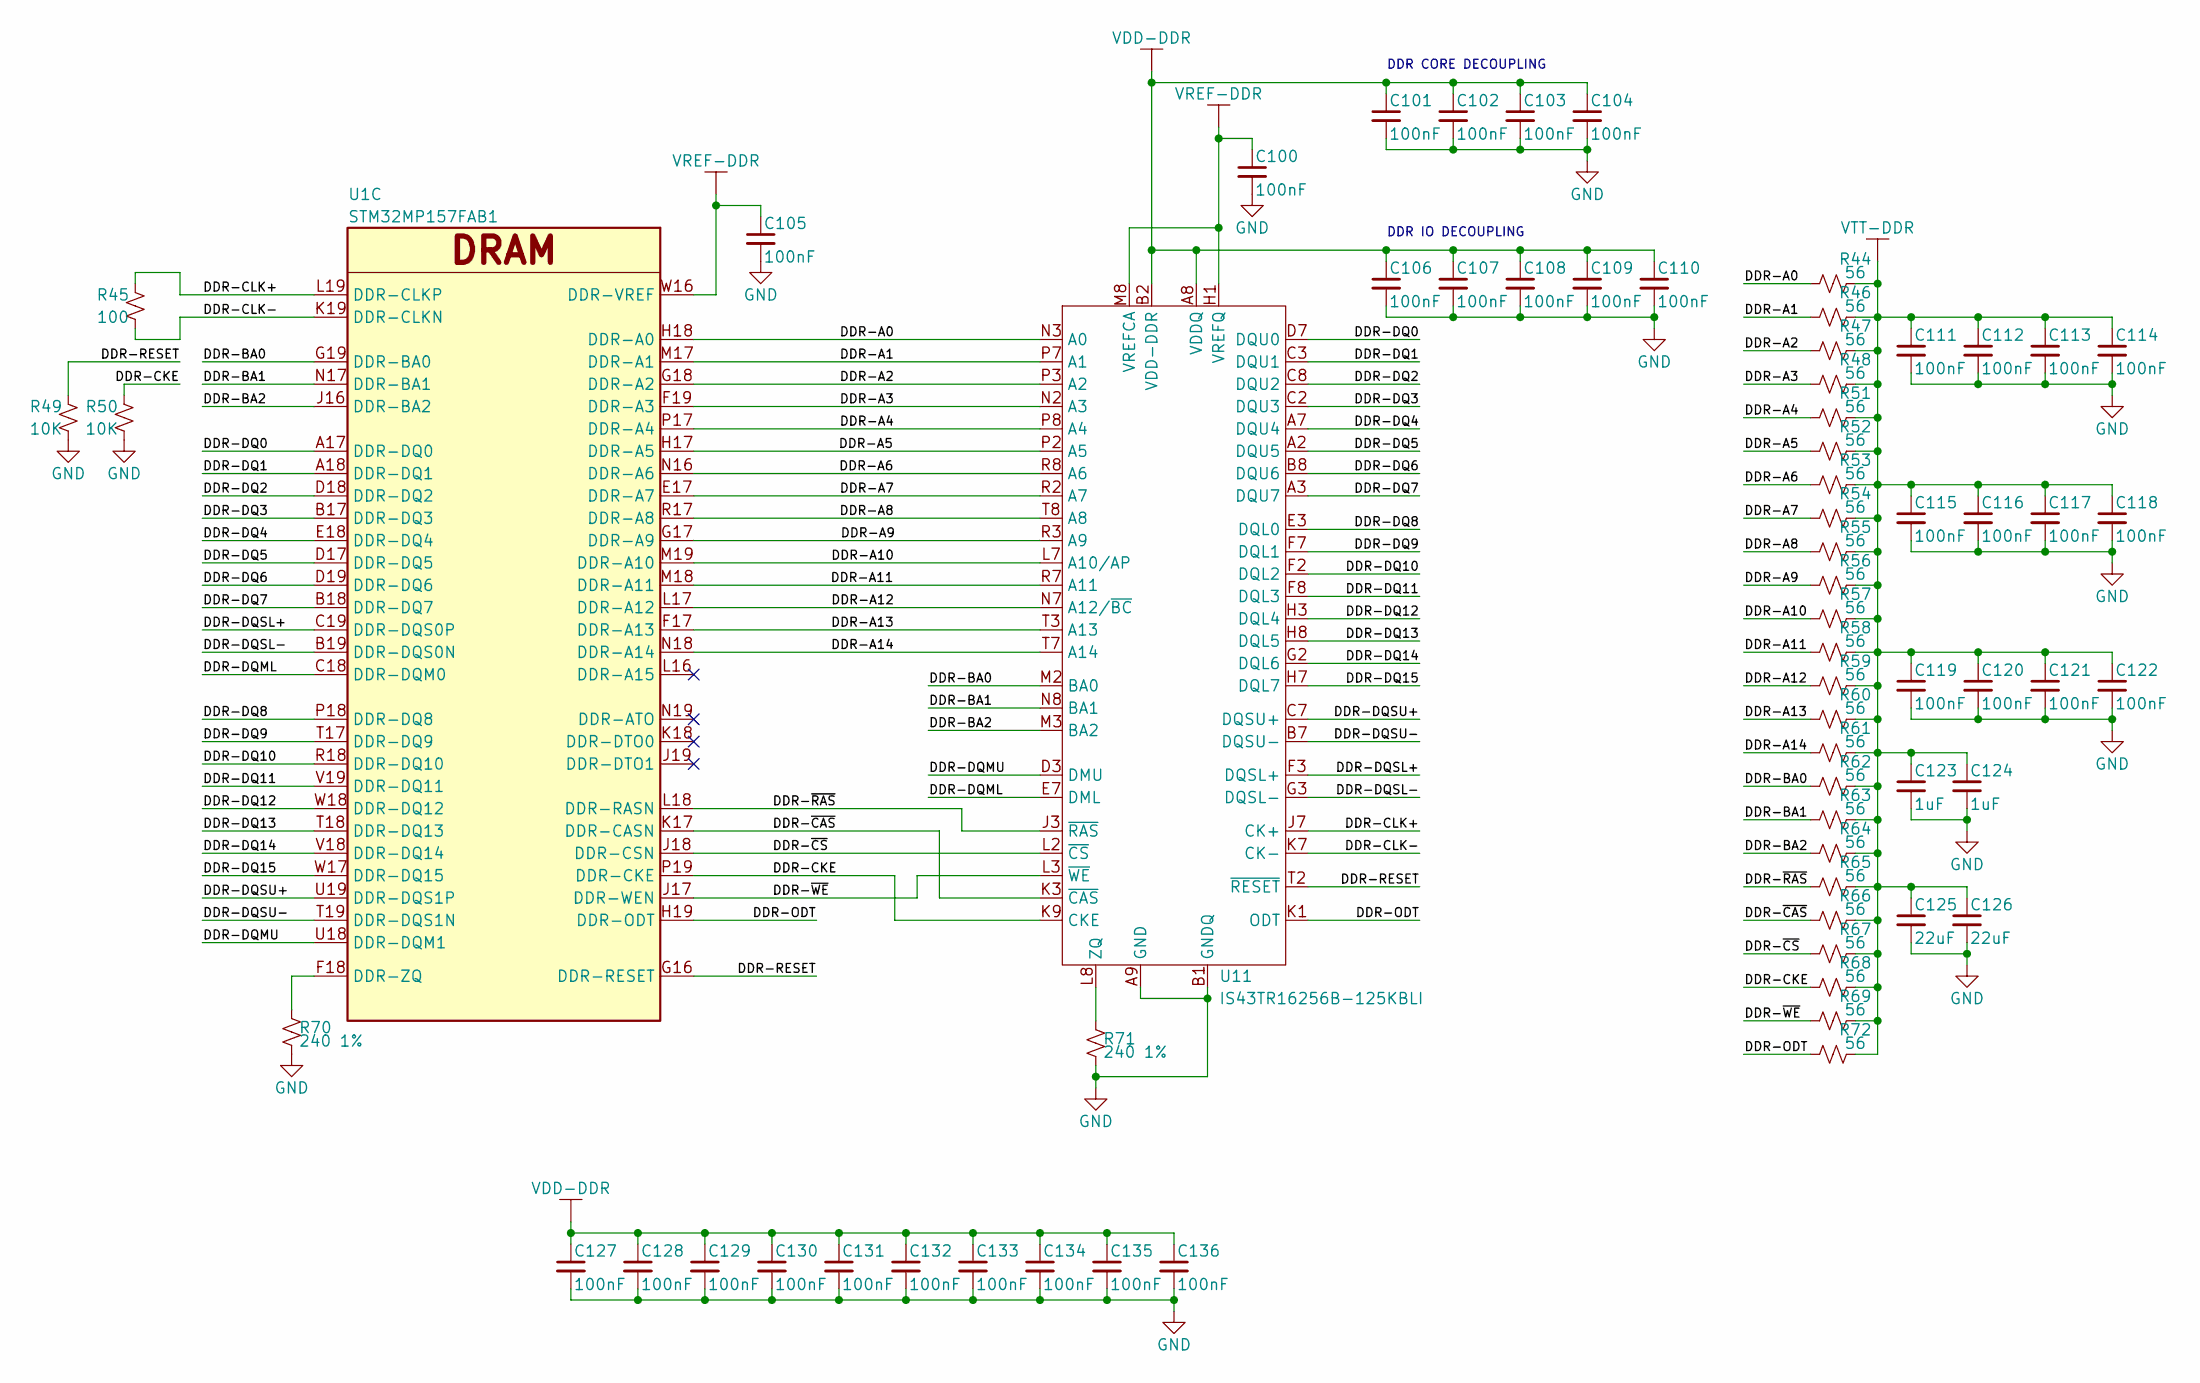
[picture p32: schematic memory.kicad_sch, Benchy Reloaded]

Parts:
C100, C105, C111, C112, C113, C114, C115, C116, C117, C118, C119, C120, C121, C122, C127, C128, C129, C130, C131, C132, C133, C134, C135, C136: 100nF; C_0402_1005Metric
C101, C102, C103, C104, C106, C107, C108, C109, C110: 100nF; C_0603_1608Metric
C123, C124: 1uF; C_0603_1608Metric
C125, C126: 22uF; C_1210_3225Metric
R44, R46, R47, R48, R51, R52, R53, R54, R55, R56, R57, R58, R59, R60, R61, R62, R63, R64, R65, R66, R67, R68, R69, R72: 56; R_0402_1005Metric
R45: 100; R_0402_1005Metric
R49, R50: 10K; R_0402_1005Metric
R70, R71: 240 1%; R_0402_1005Metric
U1: STM32MP157FAB1; LFBGA354-P0.8mm
U11: IS43TR16256B-125KBLI; BGA-96_9.0x13.0mm_Layout2x3x16_P0.8mm

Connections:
/MEMORY/DDR-A0: R44.1, U1.H18 (DDR-A0), U11.N3 (A0)
/MEMORY/DDR-A1: R46.1, U1.M17 (DDR-A1), U11.P7 (A1)
/MEMORY/DDR-A2: R47.1, U1.G18 (DDR-A2), U11.P3 (A2)
/MEMORY/DDR-A3: R48.1, U1.F19 (DDR-A3), U11.N2 (A3)
/MEMORY/DDR-A4: R51.1, U1.P17 (DDR-A4), U11.P8 (A4)
/MEMORY/DDR-A5: R52.1, U1.H17 (DDR-A5), U11.P2 (A5)
/MEMORY/DDR-A6: R53.1, U1.N16 (DDR-A6), U11.R8 (A6)
/MEMORY/DDR-A7: R54.1, U1.E17 (DDR-A7), U11.R2 (A7)
/MEMORY/DDR-A8: R55.1, U1.R17 (DDR-A8), U11.T8 (A8)
/MEMORY/DDR-A9: R56.1, U1.G17 (DDR-A9), U11.R3 (A9)
/MEMORY/DDR-A10: R57.1, U1.M19 (DDR-A10), U11.L7 (A10/AP)
/MEMORY/DDR-A11: R58.1, U1.M18 (DDR-A11), U11.R7 (A11)
/MEMORY/DDR-A12: R59.1, U1.L17 (DDR-A12), U11.N7 (A12/~BC)
/MEMORY/DDR-A13: R60.1, U1.F17 (DDR-A13), U11.T3 (A13)
/MEMORY/DDR-A14: R61.1, U1.N18 (DDR-A14), U11.T7 (A14)
/MEMORY/DDR-BA0: R62.1, U1.G19 (DDR-BA0), U11.M2 (BA0)
/MEMORY/DDR-BA1: R63.1, U1.N17 (DDR-BA1), U11.N8 (BA1)
/MEMORY/DDR-BA2: R64.1, U1.J16 (DDR-BA2), U11.M3 (BA2)
/MEMORY/DDR-CKE: R50.2, R68.1, U1.P19 (DDR-CKE), U11.K9 (CKE)
/MEMORY/DDR-CLK+: R45.2, U1.L19 (DDR-CLKP), U11.J7 (CK+)
/MEMORY/DDR-CLK-: R45.1, U1.K19 (DDR-CLKN), U11.K7 (CK-)
/MEMORY/DDR-DQ0: U1.A17 (DDR-DQ0), U11.D7 (DQU0)
/MEMORY/DDR-DQ1: U1.A18 (DDR-DQ1), U11.C3 (DQU1)
/MEMORY/DDR-DQ2: U1.D18 (DDR-DQ2), U11.C8 (DQU2)
/MEMORY/DDR-DQ3: U1.B17 (DDR-DQ3), U11.C2 (DQU3)
/MEMORY/DDR-DQ4: U1.E18 (DDR-DQ4), U11.A7 (DQU4)
/MEMORY/DDR-DQ5: U1.D17 (DDR-DQ5), U11.A2 (DQU5)
/MEMORY/DDR-DQ6: U1.D19 (DDR-DQ6), U11.B8 (DQU6)
/MEMORY/DDR-DQ7: U1.B18 (DDR-DQ7), U11.A3 (DQU7)
/MEMORY/DDR-DQ8: U1.P18 (DDR-DQ8), U11.E3 (DQL0)
/MEMORY/DDR-DQ9: U1.T17 (DDR-DQ9), U11.F7 (DQL1)
/MEMORY/DDR-DQ10: U1.R18 (DDR-DQ10), U11.F2 (DQL2)
/MEMORY/DDR-DQ11: U1.V19 (DDR-DQ11), U11.F8 (DQL3)
/MEMORY/DDR-DQ12: U1.W18 (DDR-DQ12), U11.H3 (DQL4)
/MEMORY/DDR-DQ13: U1.T18 (DDR-DQ13), U11.H8 (DQL5)
/MEMORY/DDR-DQ14: U1.V18 (DDR-DQ14), U11.G2 (DQL6)
/MEMORY/DDR-DQ15: U1.W17 (DDR-DQ15), U11.H7 (DQL7)
/MEMORY/DDR-DQML: U1.C18 (DDR-DQM0), U11.E7 (DML)
/MEMORY/DDR-DQMU: U1.U18 (DDR-DQM1), U11.D3 (DMU)
/MEMORY/DDR-DQSL+: U1.C19 (DDR-DQS0P), U11.F3 (DQSL+)
/MEMORY/DDR-DQSL-: U1.B19 (DDR-DQS0N), U11.G3 (DQSL-)
/MEMORY/DDR-DQSU+: U1.U19 (DDR-DQS1P), U11.C7 (DQSU+)
/MEMORY/DDR-DQSU-: U1.T19 (DDR-DQS1N), U11.B7 (DQSU-)
/MEMORY/DDR-ODT: R72.1, U1.H19 (DDR-ODT), U11.K1 (ODT)
/MEMORY/DDR-RESET: R49.2, U1.G16 (DDR-RESET), U11.T2 (~RESET)
/MEMORY/DDR-~CAS: R66.1, U1.K17 (DDR-CASN), U11.K3 (~CAS)
/MEMORY/DDR-~CS: R67.1, U1.J18 (DDR-CSN), U11.L2 (~CS)
/MEMORY/DDR-~RAS: R65.1, U1.L18 (DDR-RASN), U11.J3 (~RAS)
/MEMORY/DDR-~WE: R69.1, U1.J17 (DDR-WEN), U11.L3 (~WE)
GND: C100.2, C101.2, C102.2, C103.2, C104.2, C105.2, C106.2, C107.2, C108.2, C109.2, C110.2, C111.2, C112.2, C113.2, C114.2, C115.2, C116.2, C117.2, C118.2, C119.2, C120.2, C121.2, C122.2, C123.2, C124.2, C125.2, C126.2, C127.2, C128.2, C129.2, C130.2, C131.2, C132.2, C133.2, C134.2, C135.2, C136.2, R49.1, R50.1, R70.2, R71.2, U11.A9 (GND), U11.B1 (GNDQ), U11.B3 (GND), U11.B9 (GNDQ), U11.D1 (GNDQ), U11.D8 (GNDQ), U11.E1 (GND), U11.E2 (GNDQ), U11.E8 (GNDQ), U11.F9 (GNDQ), U11.G1 (GNDQ), U11.G8 (GND), U11.G9 (GNDQ), U11.J2 (GND), U11.J8 (GND), U11.M1 (GND), U11.M9 (GND), U11.N1 (GND), U11.P1 (GND), U11.P9 (GND), U11.T1 (GND), U11.T9 (GND); also elsewhere on the board
unnamed: R70.1, U1.F18 (DDR-ZQ)
unnamed: R71.1, U11.L8 (ZQ)
VDD-DDR: C101.1, C102.1, C103.1, C104.1, C106.1, C107.1, C108.1, C109.1, C110.1, C127.1, C128.1, C129.1, C130.1, C131.1, C132.1, C133.1, C134.1, C135.1, C136.1, U11.A1 (VDDQ), U11.A8 (VDDQ), U11.B2 (VDD-DDR), U11.C1 (VDDQ), U11.C9 (VDDQ), U11.D2 (VDDQ), U11.D9 (VDD-DDR), U11.E9 (VDDQ), U11.F1 (VDDQ), U11.G7 (VDD-DDR), U11.H2 (VDDQ), U11.H9 (VDDQ), U11.K2 (VDD-DDR), U11.K8 (VDD-DDR), U11.N9 (VDD-DDR), U11.R1 (VDD-DDR), U11.R9 (VDD-DDR); also elsewhere on the board
VREF-DDR: C100.1, C105.1, U1.W16 (DDR-VREF), U11.H1 (VREFQ), U11.M8 (VREFCA); also elsewhere on the board
VTT-DDR: C111.1, C112.1, C113.1, C114.1, C115.1, C116.1, C117.1, C118.1, C119.1, C120.1, C121.1, C122.1, C123.1, C124.1, C125.1, C126.1, R44.2, R46.2, R47.2, R48.2, R51.2, R52.2, R53.2, R54.2, R55.2, R56.2, R57.2, R58.2, R59.2, R60.2, R61.2, R62.2, R63.2, R64.2, R65.2, R66.2, R67.2, R68.2, R69.2, R72.2; also elsewhere on the board

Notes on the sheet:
DDR CORE DECOUPLING
DDR IO DECOUPLING



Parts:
C145, C146, C148, C149, C150, C151, C152, C153, C154, C155, C156, C159, C168, C172: 10uF; C_1210_3225Metric
C147, C162, C163, C164, C165, C166, C167, C175, C176: 100nF; C_0402_1005Metric
C157, C158, C160: 1uF; C_0805_2012Metric
C161: 100nF; C_0805_2012Metric
C169, C173: 1uF; C_1210_3225Metric
C170, C171, C174, C177: 15pF; C_0402_1005Metric
D1, D2, D3, D4, D5, D9: ESDLC5V0PB8; UDFN-9_1.0x3.8mm_P0.5mm
D6: PUSB3AB4; DFN2510A-10
D7: ORANGE; LED-SMD-1204_RA
D8: YELLOW; LED-SMD-1204_RA
J9: USB3-PORT1; GSB4116341HR
J10: USB3_B; USB-GSB3211311WEU
J11: USB3-PORT2; GSB4116341HR
J12: USB3-PORT3; GSB4116341HR
J13: USB3-PORT4; GSB4116341HR
J14: USB3-PORT5; GSB4116341HR
J15: USB-INTERNAL-PORT1; 1002-014-01000
J16: TFT-DISPLAY; FH12A-20S-0.5SH55
J17: USB-INTERNAL-PORT2; 1002-014-01000
JP2: WP-JMP; PinSocket_1x03_P2.54mm_Vertical
Q3: RQ5A030AP; SOT-23; PartNumber 0704-0001
R91: 43K; R_0402_1005Metric
R92, R113, R114: 50K; R_0402_1005Metric
R93, R94, R108, R109: 2.2K; R_0402_1005Metric
R95, R96, R97: 18K; R_0402_1005Metric
R98, R99, R100, R105, R111, R117: 10K; R_0402_1005Metric
R101: 10 1%; R_0805_2012Metric
R102: 120; R_0805_2012Metric
R103: 330; R_0805_2012Metric
R104: 10K; Bourns_TC33X
R106, R107, R118: 200K; R_0402_1005Metric
R110: 3K; R_0402_1005Metric
R112: 12K 1%; R_0402_1005Metric
R115, R116: 1K; R_0402_1005Metric
U1: STM32MP157FAB1; LFBGA354-P0.8mm
U10: USB7206C; 100-VQFN-GND_12X12; PartNumber 0807-0003
U12, U13, U14: UCS2114; UCS2114T-1-V_LXVAO-Custom; PartNumber 0807-0001
U15: LM317L; SOT-89-3
U16: AS321; SOT-23-5; PartNumber 0803-0004
U17: 24LC08; SOIC-8_3.9x4.9mm_P1.27mm
U18: USB2412; QFN-28-1EP_5x5mm_P0.5mm_EP3.35x3.35mm
Y3, Y4: 25MHz; Crystal_SMD_4Pin_3.2x2.5mm
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

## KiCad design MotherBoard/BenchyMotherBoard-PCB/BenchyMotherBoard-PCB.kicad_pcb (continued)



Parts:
C137, C142: 4.7uF; C_0805_2012Metric
C138, C139, C143, C144: 15pF; C_0402_1005Metric
C140: 1nF; C_0402_1005Metric
C141: 10nF; C_0402_1005Metric
J2: SWD-TAG; Tag-Connect_TC2050-IDC-FP_2x05_P1.27mm_Vertical
J3: FILES-SD-CARD; microSD_HC_Molex_47219-2001
J4: BOOT0-CONN; PinHeader_1x03_P2.54mm_Vertical
J5: BOOT1-CONN; PinHeader_1x03_P2.54mm_Vertical
J6: BOOT2-CONN; PinHeader_1x03_P2.54mm_Vertical
J7: BOOT-SD-CARD; microSD_HC_Molex_47219-2001
J8: FAN-CONN; PinHeader_1x02_P2.54mm_Vertical
Q1: SQ2310ES_SOT23; SOT-23; PartNumber 0703-0001
Q2: MMBT2222A; SOT-23; PartNumber 0701-0001
R73, R82, R88: 10K; R_0402_1005Metric
R74, R75, R76, R77, R78, R83, R84, R85, R86, R87: 47K; R_0402_1005Metric
R79, R80, R81, R89: 100; R_0402_1005Metric
R90: 1K; R_0402_1005Metric
U1: STM32MP157FAB1; LFBGA354-P0.8mm
Y1: 24MHz; Crystal_SMD_4Pin_3.2x2.5mm
Y2: 32.7KHz; Crystal_SMD_4Pin_3.2x2.5mm

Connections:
/COMMUNICATIONS/ELOAD-BUS.SCK: U1.T1 (I2C4-SCL); also elsewhere on the board
/COMMUNICATIONS/ELOAD-BUS.SDA: U1.U12 (I2C4-SDA); also elsewhere on the board
/COMMUNICATIONS/LOGIC-BUS.SCK: U1.B8 (I2C3-SCL); also elsewhere on the board
/COMMUNICATIONS/LOGIC-BUS.SDA: U1.A10 (I2C3-SDA); also elsewhere on the board
/COMMUNICATIONS/PWR-BUS.SCK: U1.W5 (I2C2-SCL); also elsewhere on the board
/COMMUNICATIONS/PWR-BUS.SDA: U1.V1 (I2C2-SDA); also elsewhere on the board
/COMMUNICATIONS/SWITCHER-BUS.SCK: U1.V17 (I2C5-SCL); also elsewhere on the board
/COMMUNICATIONS/SWITCHER-BUS.SDA: U1.U16 (I2C5-SDA); also elsewhere on the board
/INPUT | OUTPUT/BOOT0-JMP: J4.2, R79.1
/INPUT | OUTPUT/BOOT1-JMP: J5.2, R80.1
/INPUT | OUTPUT/BOOT2-JMP: J6.2, R81.1
/INPUT | OUTPUT/DISP-BUS.BRIGHT: U1.C2 (TIM1-CH3)
/INPUT | OUTPUT/DISP-BUS.RESET: U1.B11 (PE4); also elsewhere on the board
/INPUT | OUTPUT/DISP-BUS.TE: U1.D10 (PC6); also elsewhere on the board
/INPUT | OUTPUT/FAN-PWM: R90.2, U1.C1 (TIM1-CH2)
/INPUT | OUTPUT/RELAY-BUS.1: U1.T8 (PB5)
/INPUT | OUTPUT/RELAY-BUS.2: U1.T9 (PB13)
/INPUT | OUTPUT/RELAY-BUS.3: U1.T7 (PC0)
/INPUT | OUTPUT/RELAY-BUS.4: U1.T6 (PA7)
/INPUT | OUTPUT/RELAY-BUS.5: U1.T10 (PE7)
/INPUT | OUTPUT/RELAY-BUS.6: U1.T11 (PE8)
/INPUT | OUTPUT/SD-BOOT-CLK: J7.5 (CLK), R82.2, U1.A5 (SDMMC2-CK)
/INPUT | OUTPUT/SD-BOOT-CMD: J7.3 (CMD), R85.2, U1.A6 (SDMMC2-CMD)
/INPUT | OUTPUT/SD-BOOT-D0: J7.7 (DAT0), R83.2, U1.B3 (SDMMC2-D0)
/INPUT | OUTPUT/SD-BOOT-D1: J7.8 (DAT1), R84.2, U1.A8 (SDMMC2-D1)
/INPUT | OUTPUT/SD-BOOT-D2: J7.1 (DAT2), R87.2, U1.A7 (SDMMC2-D2)
/INPUT | OUTPUT/SD-BOOT-D3: J7.2 (DAT3/CD), R86.2, U1.B9 (SDMMC2-D3)
/INPUT | OUTPUT/SD-BOOT-DETECT: U1.C9 (PB14)
/INPUT | OUTPUT/SD-FILES-CLK: J3.5 (CLK), R73.2, U1.A2 (SDMMC3-CK)
/INPUT | OUTPUT/SD-FILES-CMD: J3.3 (CMD), R76.2, U1.A3 (SDMMC3-CMD)
/INPUT | OUTPUT/SD-FILES-D0: J3.7 (DAT0), R74.2, U1.A4 (SDMMC3-D0)
/INPUT | OUTPUT/SD-FILES-D1: J3.8 (DAT1), R75.2, U1.D6 (SDMMC3-D1)
/INPUT | OUTPUT/SD-FILES-D2: J3.1 (DAT2), R78.2, U1.D7 (SDMMC3-D2)
/INPUT | OUTPUT/SD-FILES-D3: J3.2 (DAT3/CD), R77.2, U1.B4 (SDMMC3-D3)
/INPUT | OUTPUT/SD-FILES-DETECT: U1.C6 (PD3)
/INPUT | OUTPUT/SDMMC-CMD: U1.B10 (PD2)
/INPUT | OUTPUT/SM-BUS.RX: U1.E3 (USART2-RX); also elsewhere on the board
/INPUT | OUTPUT/SM-BUS.TX: U1.W2 (USART2-TX); also elsewhere on the board
/INPUT | OUTPUT/SWDCLK: J2.4 (SWDCLK), U1.D16 (SWCLK)
/INPUT | OUTPUT/SWDIO: J2.2 (SWDIO), U1.D15 (SWDIO)
/INPUT | OUTPUT/SWO: J2.6 (SWO), U1.D14 (SWO-TRACE)
/INPUT | OUTPUT/USB-BUS.RESET: U1.T13 (PB2); also elsewhere on the board
/INPUT | OUTPUT/USB-BUS.SCK: U1.T12 (I2C1-SCL); also elsewhere on the board
/INPUT | OUTPUT/USB-BUS.SDA: U1.B5 (I2C1-SDA); also elsewhere on the board
GND: C137.2, C138.1, C139.2, C141.1, C142.2, C143.1, C144.2, J2.3 (GND), J2.5 (GND), J2.9 (GNDDetect), J3.6 (VSS), J3.9 (SHIELD), J4.3, J5.3, J6.3, J7.6 (VSS), J7.9 (SHIELD), Q1.2 (S), Q2.1 (E), Y1.2, Y1.4, Y2.2, Y2.4; also elsewhere on the board
unnamed: C138.2, U1.M1 (OSC-IN), Y1.1
unnamed: C139.1, U1.M2 (OSC-OUT), Y1.3
unnamed: C140.1, U1.J2 (~RST-CORE)
unnamed: C143.2, U1.H1 (OSC32-IN), Y2.1
unnamed: C144.1, U1.H2 (OSC32-OUT), Y2.3
unnamed: J8.2, Q1.3 (D)
unnamed: Q1.1 (G), R89.2
unnamed: Q2.2 (B), R90.1
unnamed: Q2.3 (C), R88.1, R89.1
unnamed: R79.2, U1.K1 (BOOT0)
unnamed: R80.2, U1.K4 (BOOT1)
unnamed: R81.2, U1.L2 (BOOT2)
RESET: C140.2, C141.2, J2.10 (~RESET), U1.J1 (~RST); also elsewhere on the board
VCC: R88.2; also elsewhere on the board
VDD: C137.1, C142.1, J2.1 (Vref), J3.4 (VDD), J4.1, J5.1, J6.1, J7.4 (VDD), R73.1, R74.1, R75.1, R76.1, R77.1, R78.1, R82.1, R83.1, R84.1, R85.1, R86.1, R87.1; also elsewhere on the board
VPWR: J8.1; also elsewhere on the board

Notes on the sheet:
DEFAULT: SDCARD SDMMC1 BOOT0: 1 BOOT1: 0 BOOT2: 1

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

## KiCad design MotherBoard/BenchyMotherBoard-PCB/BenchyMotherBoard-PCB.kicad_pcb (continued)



Board: 8 copper layers, 160.0 x 100.0 mm, 360 parts (15 on the bottom side), 267 nets.

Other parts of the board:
kibuzzard-63F3F2E0: G***; kibuzzard-63F3F2E0

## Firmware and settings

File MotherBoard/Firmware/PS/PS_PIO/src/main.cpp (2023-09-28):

#include <Arduino.h>
#include <Wire.h>
#include "PMBus.h"

const int PWR_ON_RST_PIN =  PIN_PA4;
const int PWR_ON =  PIN_PA5;
const int PMBUS_ALERT_PIN = PIN_PA6;
const int PWR_SW_PIN = PIN_PA7;

const int ALL_GOOD_PIN = PIN_PB4;
const int PERIPH_EN_PIN = PIN_PB5;
const int PWR_ERR_PIN = PIN_PC0;
const int USB_EN_PIN = PIN_PC1;
const int DDR_EN_PIN = PIN_PC2;
const int VDDA_EN_PIN = PIN_PC3;

const uint8_t PMBusAddress = 0x6F;

PMBusState state = PMBusState();
PMBus pmBus = PMBus(PMBUS_ALERT_PIN, PMBusAddress);

// Power switch state for MPU
bool btnPrev = false;
bool powerON = false;

void InitPins()
{
  // PORTA_DIRSET   = 0;
  // PORTB_DIRSET   = 0b00100000;
  // PORTC_DIRSET   = 0b00001111;
  // // PORTC_PIN0CTRL = 0b10000000;

  // PORTB_OUT = 0;
  // PORTC_OUT = 0;

  pinMode(PWR_ON_RST_PIN, INPUT);
  pinMode(PWR_ON, INPUT);
  pinMode(PWR_SW_PIN, INPUT);
  pinMode(ALL_GOOD_PIN, INPUT);
  pinMode(PERIPH_EN_PIN, OUTPUT);
  pinMode(PWR_ERR_PIN, OUTPUT);
  pinMode(USB_EN_PIN, OUTPUT);
  pinMode(DDR_EN_PIN, OUTPUT);
  pinMode(VDDA_EN_PIN, OUTPUT);
}

void WriteSettings()
{
  // pmBus.SoftReset();
  delay(1000);
  // pmBus.SetEnablePins(PM_ENABLE_CONFIG::ALL_ACTIVE);

  // pmBus.WriteAllSettings();

  // uint8_t startSeq[4] = {1, 2, 3, 3};
  // uint8_t stopSeq[4] = {3, 3, 2, 1};
  // pmBus.SetSequences(startSeq, stopSeq);

  // pmBus.SetWriteProtection(PM_WRITE_PROTECT::ALL_ENABLE);
  // pmBus.SetEnablePins(PM_ENABLE_CONFIG::ALL_INACTIVE);
  #ifdef WRITE_SETTINGS
  pmBus.WriteAllSettings(true);
  #else
  pmBus.WriteAllSettings(false);
  #endif
}

void PinStartupSeq()
{
  digitalWrite(DDR_EN_PIN, HIGH);
  digitalWrite(USB_EN_PIN, HIGH);
}

void Blink(int count)
{
  for (size_t i = 0; i < count; i++)
  {
    // PORTC_OUTSET = 1;
    digitalWrite(PWR_ERR_PIN, HIGH);
    delay(100);
    // PORTC_OUTCLR = 1;
    digitalWrite(PWR_ERR_PIN, LOW);
    delay(100);
  }
}

void setup() {
  InitPins();
  digitalWrite(PWR_ERR_PIN, HIGH);
  state.EnableConfig = PM_ENABLE_CONFIG::ALL_INACTIVE;
  // state.SequenceConfig = PM_SEQUENCE_CONFIG::INGORE_PGOOD;
  state.Rails[0] = RailStatus(); // VDD
  state.Rails[1] = RailStatus(); // VDD-CORE
  state.Rails[2] = RailStatus(); // VDD-DDR
  state.Rails[3] = RailStatus(); // USB-CORE
  state.Rails[0].Sequence.Set(0, 3);
  state.Rails[1].Sequence.Set(1, 2);
  state.Rails[2].Sequence.Set(2, 1);
  state.Rails[3].Sequence.Set(3, 0);
  #ifdef MAN
  state.Rails[0].Delay.Set(0, 100);
  state.Rails[1].Delay.Set(100, 100);
  state.Rails[2].Delay.Set(100, 100);
  state.Rails[3].Delay.Set(100, 0);
  #else
  state.Rails[0].Delay.Set(0, 0b100);
  state.Rails[1].Delay.Set(0b010, 0b010);
  state.Rails[2].Delay.Set(0b100, 0b100);
  state.Rails[3].Delay.Set(0b100, 0);
  #endif
  // Serial.begin(115200);
  pmBus.Init(&state);
  // #ifdef MAN
  // if(powerON)
  // {
  //   pmBus.ManualSequence(PM_RAIL_STATE::ENABLE);
  // }
  // #else
  // #endif
  WriteSettings();
  digitalWrite(VDDA_EN_PIN, HIGH);
  delay(100);
  digitalWrite(PWR_ERR_PIN, LOW);
  digitalWrite(DDR_EN_PIN, HIGH);
}

void loop() {
  #ifndef MAN
  // Blink(2);
  digitalWrite(PWR_ERR_PIN, HIGH);
  // digitalWrite(USB_EN_PIN, HIGH);
  pmBus.EnableAllRails();
  // delay(1000);
  digitalWrite(PWR_ERR_PIN, LOW);
  delay(5000);
  // digitalWrite(USB_EN_PIN, LOW);
  pmBus.DisableAllRails();
  Blink(4);

  // delay(4000);
  // pmBus.ReadStatus(0);
  // pmBus.ReadRailPGOODs();
  // Blink(pmBus.GetPGoods());

  delay(5000);
  #else
  // Blink(4);
  uint8_t btn = digitalRead(PWR_SW_PIN);
  if (btn == LOW && btn != btnPrev)
  {
    powerON = !powerON;
    btnPrev = btn;
    pmBus.ManualSequence(powerON ? PM_RAIL_STATE::ENABLE : PM_RAIL_STATE::DISABLE);
    delay(150);
    Blink(4);
  }
  #endif
}

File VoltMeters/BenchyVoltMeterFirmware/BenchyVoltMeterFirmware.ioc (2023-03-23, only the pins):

Mcu.UserName=STM32F303RCTx
PA0.GPIO_Label=VOLT-1
PA0.Signal=ADC1_IN1
PA1.GPIO_Label=VOLT-2
PA1.Signal=ADC1_IN2
PA10.GPIO_Label=I2C-CTRLS-SDA
PA10.Signal=I2C2_SDA
PA13.Signal=SYS_JTMS-SWDIO
PA14.Signal=SYS_JTCK-SWCLK
PA15.GPIO_Label=I2C-MAIN-SCL
PA15.Signal=I2C1_SCL
PA2.GPIO_Label=COMPA-M
PA2.Signal=COMP2_INM
PA3.GPIO_Label=COMPA-P
PA3.Signal=COMP2_INP
PA4.GPIO_Label=VOLT-3
PA4.Signal=ADC2_IN1
PA5.GPIO_Label=VOLT-4
PA5.Signal=ADC2_IN2
PA9.GPIO_Label=I2C-CTRLS-SCL
PA9.Signal=I2C2_SCL
PB0.GPIO_Label=COMPB-P
PB0.Signal=COMP4_INP
PB1.GPIO_Label=VOLT-5
PB1.Signal=ADC3_IN1
PB12.GPIO_Label=VOLT-6
PB12.Signal=ADC4_IN3
PB13.GPIO_Label=VOLT-7
PB13.Signal=ADC3_IN5
PB14.GPIO_Label=VOLT-8
PB14.Signal=ADC4_IN4
PB2.GPIO_Label=COMPB-M
PB2.Signal=COMP4_INM
PB3.Signal=SYS_JTDO-TRACESWO
PB7.GPIO_Label=I2C-MAIN-SDA
PB7.Signal=I2C1_SDA
PC10.GPIO_Label=INT-CTRLS
PC10.Signal=GPXTI10
PC7.GPIO_Label=VCCA-PG
PC7.Signal=GPIO_Input
PC8.GPIO_Label=VDDA-PG
PC8.Signal=GPIO_Input
PF0-OSC_IN.Signal=RCC_OSC_IN
PF1-OSC_OUT.Signal=RCC_OSC_OUT

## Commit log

2023-02-18 initial Commit - Add mother MPU and PWR ICs
    [BenchyMotherBoard-PCB.kicad_pcb, BenchyMotherBoard-PCB.kicad_sch, TPS65400-TESTING.ods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]
2023-02-19 Add MORE regulators, USB, Display, and SDCard
    [BenchyMotherBoard-PCB.kicad_sch, Motherboard-Power-Calc.ods, TPS65400-TESTING.ods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]
2023-02-20 Initial schematic lock
    [BenchyMotherBoard-PCB.kicad_pcb, BenchyMotherBoard-PCB.kicad_sch, Motherboard-Power-Calc.ods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]
2023-02-20 (WIP) Start layout
    [BenchyMotherBoard-PCB.kicad_pcb, BenchyMotherBoard-PCB.kicad_sch, Motherboard-Power-Calc.ods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]
2023-02-21 (WIP) Replaced DDR VRef with reg and started layout
    [BenchyMotherBoard-PCB.kicad_pcb, BenchyMotherBoard-PCB.kicad_sch, BenchyRelays-PCB.kicad_pcb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]
2023-02-23 Add PGOOD led and replace PWR switch
    [BenchyMotherBoard-PCB.kicad_pcb, BenchyMotherBoard-PCB.kicad_sch, Motherboard-Power-Calc.ods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]
2023-02-24 Start DDR3 layout
    [BenchyMotherBoard-PCB.kicad_sch, DDR3-Memory.ods, comms.kicad_sch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]
2023-02-25 DDR memory length match (Hopefully)
    [memory.kicad_sch]
2023-02-26 (WIP) DDR memory length match (re-calc)
    [memory.kicad_sch]
2023-02-27 Finish DDR3 memory layout
    [DDR3-Memory.ods, DDR_Memory_Length_Equalization.ods, comms.kicad_sch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]
2023-02-28 Mostly routed USB
    [comms.kicad_sch, gpio.kicad_sch, memory.kicad_sch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]
2023-03-01 Most routing completed
    [DDR_Memory_Length_Equalization.ods, gpio.kicad_sch, usb.kicad_sch]
2023-03-02 Fix power reset and finish routing
    [power.kicad_sch]
2023-03-02 (WIP) Fixing stripline impedance for DDR memory
    [memory.kicad_sch]
2023-03-04 Remove old DDR traces, start rerouting
    [bom.csv, designators.csv, memory.kicad_sch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]
2023-03-05 Initial DDR routing, start fixing skew
    [comms.kicad_sch, gpio.kicad_sch, memory.kicad_sch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]
2023-03-05 Replace USB TVS W/ custom & finish DDR data layout
    [memory.kicad_sch, usb.kicad_sch]
2023-03-05 DDR layout mostly complete
    [DDR_Memory_Length_Equalization.ods]
2023-03-07 REV1 - Finish layout and finalize pcb
    [gpio.kicad_sch, power.kicad_sch, usb.kicad_sch]
2023-03-07 REV1 - Finish layout and generate gerbers (add lfs ext for PCB)
    [BenchyRelays-PCB.kicad_pcb]
2023-03-07 Fix file size issue with custom PCB fonts
2023-03-10 Fix fab layer text and generate BOM
2023-03-10 Fix power stuff
    [power.kicad_sch]
2023-03-12 Add volt meter PCB
    [BenchyMotherBoard-PCB.kicad_sch, BenchyVoltMeters.kicad_pcb, BenchyVoltMeters.kicad_sch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]
2023-03-23 Add voltmeter PCB
    [BenchyVoltMeters.kicad_pcb, BenchyVoltMeters.kicad_sch, MICRO.kicad_sch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]
2023-03-23 Fix schematic bugs and add PIO firmware (Not Working)
    [power.kicad_sch]
2023-03-24 Add mplab config and proj / remove pio proj
    [power.kicad_sch, usb.kicad_sch]
2023-03-26 Fix issues with power supply schematic
    [BenchyMotherBoard-PCB.kicad_sch, comms.kicad_sch, gpio.kicad_sch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]
2023-03-27 Add extra functions to PMBus and create manual power sequence
    [power.kicad_sch]
2023-03-27 Add USB power connector and start layout fixes
2023-03-27 Finish trace layout and update PS fb resistor values
    [Motherboard-Power-Calc.ods, comms.kicad_sch, power.kicad_sch]
2023-05-13 Wrap up REV2 and add voltmeter gerbers
    [BenchyVoltMeters.kicad_pcb, HubConfig_1.cfg, gpio.kicad_sch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]
2023-05-14 (!!WIP!!) Started schematic and block diagram
    [BenchyMotherBoard-PCB.kicad_sch, BlockDiagram.kicad_sch, PwrRegBD.kicad_sch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]
2023-06-03 (WIP) Finish more of the PS schematic
    [Audio.kicad_sch, BenchyMotherBoard-PCB.kicad_sch, BlockDiagram.kicad_sch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]
2023-06-03 (WIP) More work on power supply sequencing
    [Audio.kicad_sch, Ethernet.kicad_sch, display.kicad_sch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]
2023-06-05 (WIP) Complete most of the PS and boot schematics
    [Audio.kicad_sch, BenchyMotherBoard-PCB.kicad_sch, Control.kicad_sch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]
2023-06-09 Add new ethernet chip - KSZ9031
    [Control.kicad_sch, Ethernet.kicad_sch, comms.kicad_sch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]
2023-06-11 (WIP) Almost done with schematic
    [Audio.kicad_sch, BenchyMotherBoard-PCB.kicad_sch, Control.kicad_sch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]
2023-06-12 Start PCB layout
    [Audio.kicad_sch, Control.kicad_sch, Ethernet.kicad_sch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]
2023-06-13 Fix power net names and increase PCB size
    [Audio.kicad_sch, Control.kicad_sch, Ethernet.kicad_sch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]
2023-06-15 (WIP) Still laying out PCB
    [Control.kicad_sch, Ethernet.kicad_sch, gpio.kicad_sch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]
2023-09-28 Add docs for benchy reloaded
    [Ethernet.kicad_sch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]
2025-04-12 Replacing motherboard and more - SAVE
    [Audio.kicad_sch, BenchyFrontPanel.kicad_pcb, BenchyFrontPanel.kicad_sch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]
2025-04-13 Schematic capture mostly complete. Starting PCB layout
    [BenchyELoad.kicad_pcb, BenchyELoad.kicad_sch, BenchyELoad_LCR.kicad_sch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]
